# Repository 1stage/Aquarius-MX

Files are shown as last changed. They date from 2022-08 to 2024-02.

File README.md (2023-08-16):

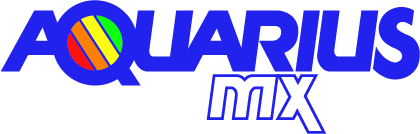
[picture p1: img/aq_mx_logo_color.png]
Aquarius MX Logo


## Overview
The Aquarius MX system expander brings USB compatibility to the Aquarius Computer along with a 32K RAM expansion, and features all the functionality of Bruce Abbott's Micro Expander in an easy-to-build solution that fits the footprint of the Mini Expander.

## Features
- **USB Drive Port** - Reads and writes to USB drive, for quick access to games and programs
- **32k RAM** - Removes the need for a separate RAM expansion cartridge
- **Cartridge ROM Loading** - Quick loading/running of legacy Aquarius ROM cartridges through USB
- **AY-3-8910 Sound Chip** - Three voice PSG (Programmable Sound Generator) with Control Pad IO
- **AY-3-8913 Sound Chip** - Support for optional second PSG (Programmable Sound Generator) for a total of six voices
- **Real Time Clock** - Support for optional Dallas DS1244Y Real Time Clock chip for TimeDate functions
- **PT3 Music Player** - Built-in retro music player
- **Aquarius Control Pad Inputs** - Standard DB9 connectors for attaching Aquarius Control Pads (internal header also available)
- **USB BASIC** - Enhanced commands for USB and IO devices to improve your BASIC programs
- **Classic Design** - Matches original Aquarius design aesthetic, in a device the same size as the Mini Expander: 210mm x 120mm x 55mm / 8.5" x 4.75" x 2.125"
- **Easy to Build** - Using standard through-hole components, this is an easy-to-make project for those who like to tinker in electronics
- **Open Source** - All components of this project are open source: make or modify them to your heart's content
- **Expandable** - System expansion port available for future add-ons

## Status Updates
- **16 AUG 2023** - MX BASIC 2.0 Final Release. Legacy v1.2 moved to archive.
- **09 AUG 2023** - MX BASIC 2.0 Beta Final Candidate release
- **16 JUL 2023** - MX BASIC 2.0 Beta 01 release
- **03 JUN 2023** - Update to 1-6-0 PCB to solve a shorting issue (thanks Carl Miles for finding this one). New version is 1-6-0b. Pushed to PCBWAY and PCB directory. 1-6-0a removed from repo.
- **16 MAY 2023** - Alpha Testing in process. Version 1-6-0a of PCB available, supporting new ROM/CART and RTC reset options; AQ_MX_RRU.JED incremented to 1.2 to support reset behavior updates. ROM v1.3 development upgraded to v2.0 due to large list of features and updates.
- **01 MAY 2023** - Version 1-5-0a of PCB available, supporting RTC integration.
- **02 FEB 2023** - Published version 1-4-0c of the PCB which fixes a missing mounting hole for Controller B when using a metal DB9 port. If you ordered a 1-4-0b version, the hole can be drilled out at 1/8" / 3.25mm.
- **21 JAN 2023** - Published version 1-4-0b of the PCB. Allows use of either **[Type A or Type B CH376S USB interface boards](https://github.com/1stage/Aquarius-MX/tree/main/pcb#ch376s-usb-interface-modules)**, and allows use of less expensive metal DB9 connectors.
- **07 NOV 2022** - Created PDF form template for bottom label.
- **26 SEP 2022** - Released YouTube video on intro to USB BASIC programming. Added source files and tools from the videos into the src/usb-basic folder.
- **21 SEP 2022** - v1.2 of MX ROM released to fix LOAD into array bug, and added "smart" load of SCR files into Screen RAM; [**AquaLite 1.32 released**](http://aquarius.je/aqualite) with the v1.2 MX ROM included, fixes SAVE issues, and can now be used to develop MX-dependent games & software.
- **15 SEP 2022** - Four YouTube videos on the Aquarius MX are posted; see links in docs folder.
- **09 SEP 2022** - Testing complete. All components are cleared for production and sale.
- **29 AUG 2022** - Signature Version (prebuilt) serial number 0001-SPH available for purchase on eBay (SOLD, 9/5/2022).
- **28 AUG 2022** - Prototypes shipped to testers. ROM incremented to v1.1 (replaced KILL command with DEL).
- **24 AUG 2022** - Most files have been uploaded and are actively being updated directly to the Repo.
- **23 AUG 2022** - Vendors identified in USA and UK to supply components.
- **21 AUG 2022** - First prototype completed and tested locally. Others will be built and sent to designated testers through the end of AUGUST 2022.
- **16 AUG 2022** - GitHub repository site created.

## Build Process
1. **Acquire the components** - [Click for Bill of Materials](https://docs.google.com/spreadsheets/d/1y7v0VCkjMdx25ugit28F5JhuhwDJofCVQUG5Ozl9IgA)
2. **Program the ROM and Logic Chips** - [Watch the YouTube video](https://youtu.be/DqxqzWqVAIM)
3. **Assemble the PCB** - [Watch the YouTube video](https://youtu.be/_-p9Ycmr9VQ)
4. **Enclose components in the case** - [Watch the YouTube video](https://youtu.be/FKW6YiFKHf0)
5. **Format and configure USB drive**

## GitHub Folder Structure
- **case** - components to make the 3D printed enclosure
- **docs** - system documentation, including schematics, board layout, and logo files
- **img** - image files used on this site
- **pcb** - files for making or modifying the PCB
- **software** - files for creating or updating the software used to run or control the Aquarius MX
- **src** - files for programming in USB BASIC, or modifying ROM and GAL logic chips

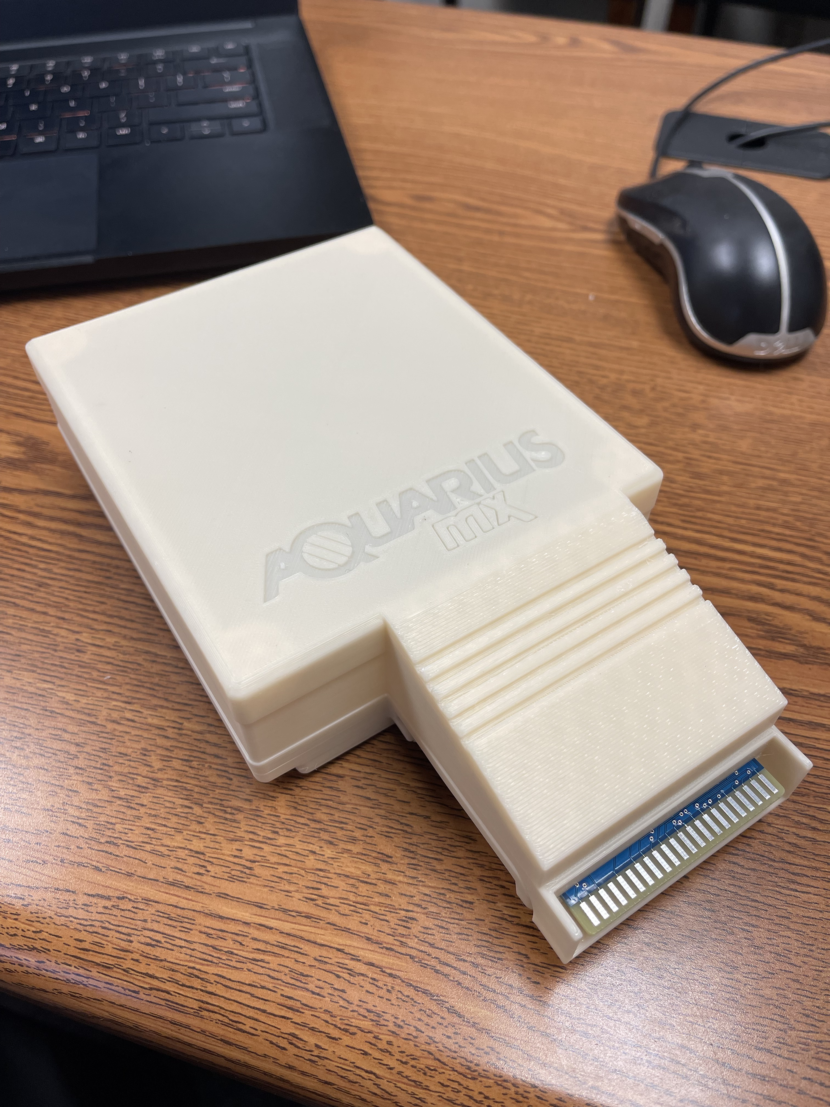
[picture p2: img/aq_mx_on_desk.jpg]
Aquarius MX on Desk


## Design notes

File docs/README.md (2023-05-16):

# Aquarius MX Documentation
This folder contains Aquarius MX documentation and logo files.

## Folder Contents
 - **USB BASIC v1.3.pdf** - This file details the new and updated commands in USB BASIC v1.3.
 - **MX_Bottom_Label.pdf** - This file is a PDF form (with embedded fonts) that allows makers of the Aquarius MX to create a professional-looking label for the bottom of the case. It can be printed using a laser, inkjet, or dyesub printer, or can be used for laser-engraved labels.
   - **Model Number field** - This value should match the PCB version, so the default MX0103-C is probably best. If you make any updates to the MX PCB, or add any modifications, consider changing this to something more in line with your modification.
   - **Serial Number field** - This value is the serial number for your unit. It is common to start with a unique sequence of numbers like 2001, 2002, 2003, followed by a three letter combination of the person making the unit.
   - **Build Date field** - This should be the date you created this unit, in DD MON YYYY format, so January 10, 2023 would be 10 JAN 2023.
 - **logo** - This foder contains the EPS (Encapsulated Post Script) logo files in vector format for use in documentation and other branding for the Aquarius MX.
   - **aq_mx_logo_blue.eps** - This logo file is the MONOCHROME version of the Aquarius MX logo. Use this file for single-color use of the logo. *DO NOT CHANGE THE COLOR OF THE LOGO TO ANYTHING OTHER THAN THE DEFAULT BLUE.*
   - **aq_mx_logo_bw.eps** - This logo file is the BLACK and WHITE version of the Aquarius MX logo. Use this file for instances where the logo will be printed on standard black on white, or on a light-colored background where only BLACK ink is available.
   - **aq_mx_logo_color.eps** - This logo file is the COLOR version of the Aquarius MX logo, which includes color banding in the "Q". Use this file for full-color use of the logo.
   - **aq_mx_logo_white.eps** - This logo file is the WHITE on dark version of the Aquarius MX logo. Use this file for instances where the logo needs to be used against a dark background. *DO NOT CHANGE THE COLOR OF THE LOGO TO ANYTHING OTHER THAN WHITE.*
 - **aq_mx_vX-X-Xx_BOARD.PDF** - This file documents the PCB layout for the Aquarius MX.
 - **aq_mx_vX-X-Xx_SCHEMATIC.PDF** - This file documents the electronic schematic for the Aquarius MX.
 - **usb-basic-commands.md** - A brief overview that discusses the USB BASIC commands.
 
 *Note: There are PNG versions (with transparency) of each of the logos listed above in raster format in the "img" folder at the root of the Aquarius MX GitHub repository.*
## How-to Videos
- **Aquarius MX Build Videos** (YouTube)
   - **[Aquarius Computer - Overview of the Aquarius MX Expander](https://youtu.be/i6mWsHNqth0)**
   - **[Aquarius Computer - Building the Aquarius MX PCB](https://youtu.be/_-p9Ycmr9VQ)**
   - **[Aquarius Computer - Programming the Aquarius MX ROM and GALs](https://youtu.be/DqxqzWqVAIM)**
   - **[Aquarius Computer - Assembling and Testing the Aqurius MX](https://youtu.be/FKW6YiFKHf0)**
   - **[Aquarius Computer - Using USB BASIC](https://youtu.be/Butym641a-0)**

## Logo Usage Recommendations
- **Keep it in Proportion** - Maintain the proper proportions of the Aquarius MX logo. Don't squash or stretch the logo to fill empty space. In most design/layout applications, this means dragging to resize the logo from the CORNER points, not the sides.
- **Colors Matter** - Don't change the colors of the logo to suit your needs. Keep the BLUE the same color blue, and don't change the COLOR version of the logo to modify the rainbow colors in the "Q".
- **Black on White** - If a single-ink/color usage is needed, use the "BW" version of the logo on light color paper/backgrounds in BLACK ink. Otherwise, use the "WHITE" version of the logo on dark color paper/backgrounds in WHITE ink.
- **Don't Make it Your Own** - Don't alter the design of the logo, or add your own branding to it that intrudes within an area closer than 10% of the height or width of the border of the logo. The logo is for EVERYONE to use as a standard.

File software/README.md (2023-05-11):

# Aquarius MX Software
This folder contains the **CURRENT RELEASE** version 1.2 of the software for programming and using the Aquarius MX.

## Folder Contents
 - **bin** - This folder contains the compiled BINARY images 
   - **AQ_MX_ROM.BIN** - For programming the EPROM (64kb MX system ROM)
   - **AQ_MX_RRU.JED** - For programming the GAL which controls the ROM/RAM/USB devices
   - **AQ_MX_AY.JED** - For programming the GAL which controls the AY sound chip IO
 - **usb** - this contains a starting set of files to be written to your properly formatted USB drive, including ROM files, PT3 music files, and starter BASIC programs that demonstrate how to use the Aquarius MX's new USB BASIC commands.

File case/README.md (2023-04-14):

# Aquarius MX 3D Printed Case
This folder contains the STL (STereoLithogray) files needed to 3D print an enclosure for the Aquarius MX.

## Files
- **aq_mx_base_template.stl** - This is a template for consistently applying the rubber feet and bottom label in the correct position on the bottom of the case.
- **aq_mx_case_bottom.stl** - This is the bottom or base of the Aquarius MX case.
- **aq_mx_case_top.stl** - This is the top or cover of the Aquarius MX case.
- **aq_mx_top2.stl** - This is an alternate top or cover with an opening to access control pad header.
- **aq_mx_top2_door.stl** - This is the door that goes with top2.
- **aq_mx_pcb_feet.stl** - This is a set of feet that can be used instead of a case to hold the PCB at the proper height.

## General Notes
- Now that either type of CH376S modules and/or either type of DB9 ports are usable, the 3D printed case MAY have to be modified to allow access to these newer ports...
  - When using the Type B CH376S module, it is inset further into the case than the Type A. This is not a problem with small USB thumbdrives, but some larger drives might not fit.
  - When using metal shrouded DB9 ports instead of the plastic automotive grade versions, the port is inset further into the case, so MOST Control Pad connectors won't fit through the standard opening. The area around these ports will have to be modified to allow these plugs to fit. At some point, a version of the 3D printed case will be developed with an OPEN BACK for the ports, where inserts for any type of port can be printed separately and glued in place. There is no timeline on this option, so for now, modifying the case is the only option.
- The RAM chip can be socketed and eventually replaced with a Dallas DS1244 RTC (Real Time Clock) module. This works as RAM for all released versions of the Aquarius MX (board and ROM), but DateTime commands that access the RTC won't be available until the 1.3 ROM is released (see the src > rom > v1.3 path for the work-in-progress). This relates to the 3D printed case because there is still plenty of HEIGHT inside the case, as-designed, for this RTC, even socketed, but the version of the case with the door (top2) does expose some of the RTC, which could interfere with future Control Pad interfaces or modified doors.

## FDM Printing
The typical method people will use to print the Aquarius MX case is FDM (Fused Deposition Modeling), the most common and cost-effective means to create a 3D printed enclosure. For the Aquarius MX case, here are the recommended specifications for FDM printing.

- **Material** - It is recommended that both components of the Aquarius MX case be printed in PLA (PolyLactic Acid) plastic rather than ABS (Acrylonitrile Butadiene Styrene) plastic, due to the large, flat surface features of the case. ABS is more prone to warping in the corners, and this can create an offset of the plane which keeps the PCB flat and even with the expansion port of the Aquarius computer. A heated build surface is strongly encouraged, particularly with the top of the case, as an embossed Aquarius MX logo is featured, and usually sticks better to a heated surface.
- **Nozzle Diameter** - A typical 0.4mm nozzle works fine
- **Layer Height** - A layer height of between 0.2mm and 0.4mm offers a good range of speed/surface quality.
- **Build Area** - The 3D printer must support a build size of 212.1mm x 120.9mm x 65.3mm / 8.5" x 4.75" x 2.125" to print the largest of the two parts (the top).
- **Support Material** - Standard square supports are recommended. Tree supports do not offer the best results. We don't require a brim or raft, but if you use these, remember to account for this in your build volume dimensions. 

### PLA Part Printing Orientation
- **Bottom** - This part should be printed with the BOTTOM facing down on the build surface, and support material is generated under the "neck" and inside the alignment notches on the neck. Using the above recommended settings, the BOTTOM piece will typically take 10 to 14 hours to complete, and will consume about 90g of PLA filament.
- **Top** - This part should be printed with the TOP facing down on the build surface, and support material is generated beneath the top "ramp" and inside the cartridge alignment guides. Note that this part features an embossed Aquarius MX logo, which prints best if a heated build surface is used. Some printers benefit from additional build surface adhesive, such as glue stick or hairspray, but go with what you're used to doing. Using the above recommended settings, the BOTTOM piece will typically take 13 to 19 hours to complete, and will consume about 114g of PLA filament

## SLA Resin Printing
Some manufacturers such as JLCPCB offer SLA (StereoLithogrAphy) resin printing for about US$20 for the two parts of the case, but shipping will usually add another US$30-40. Due to the volume and dimensions of the Aquarius MX case, SLA resin printing is not practical for most consumer-grade resin printers.

## SLS/MFJ Printing
If you have access to a high-end SLS (Selective Laser Sintering) or MJF (MultiJet Fusion) printer, these produce EXCEPTIONAL results, but at a significant cost. Most service bureaus will charge approximately US$200 for the two parts of the case, plus shipping.

## Finishing
- The case can be printed in a light beige color to approximate the Aquarius plastic (see BOM for details), or in black. The parts can alternately be printed in any color, then primed, filled and painted to suit your needs. Note that there are fine details in the embossed logo that can be lost if a filler primer is used, and some of the parts of the case that join with the Aquarius are tight, and can cause some paints to rub off if not sealed and/or lubricated properly.
- The case uses four 1/2" #4 pan head screws to attach the top and bottom halves. A metal "thread cutting" screw designed for plastic is recommended. See BOM for details.
- The finished case will also need four rubber feet for the bottom to bring the case up to the proper height for alignment with the Aquarius cartridge port. See BOM for details. You can print and use the **aq_mx_base_template** file for accurate positioning of these rubber feet.

## PCB Feet
The PCB feet file can be used instead of printing a full case for the Aquarius MX. These feet print in less than 1 hour on most FDM printers, and can be screwed to the bottom of the PCB through the mounting holes using the same screws that would hold the full case together. This maintains the PCB at a plane that is inline with the Expansion Port on the Aquarius Computer. This is important because if the PCB is at an angle (too high or too low), the contact between the computer and the expander PCB can be lost, and will cause the Aquarius MX (or the computer) to malfunction or become damaged. After printing, the four feet must be separated from one another to fit in each of the four corner PCB mounting holes. The "flashing" at the bottom edges between the feet should be trimmed off or sanded for best results.

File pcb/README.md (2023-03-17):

# Aquarius MX PCB
This folder contains the components and procedures for creating the Aquarius MX PCB (Printed Circuit Board).

[PCB is available for order directly from **PCBWay by clicking here!**](https://www.pcbway.com/project/shareproject/Aquarius_Computer_Aquarius_MX_USB_Expander_c4a2f027.html) Don't forget to like and vote for our project!

## Overview of PCB Assembly Options
For those who want to build their own Aquarius MX, there are a number of options and features that can alter the cost and complexity of the process. Solutions range from a bare PCB with only the components necessary to run and use USB BASIC and the core Aquarius MX software, all the way to a fully assembled and finished Aquarius MX. The following items offer details of the range of options.
- **Bare Bones** - The simplest version of the Aquarius MX features the PCB, the ROM (socket recommended), RAM, USB module (headers recommended), GAL-RRU logic chip (socket recommended), address buffers, ROM address headers, balance capacitors, audio amp, and reset circuit. It does not include a 3D printed enclosure, so the PCB feet MUST be used to keep the PCB aligned with the Aquarius computer Expansion Port. The AY-3-8910 sound chip and the GAL-AY logic chip are ommitted, so there will be no enhanced sound or Control Pad input, and since there is not Control Pad input, the DB9 Control Pad ports are omitted, along with the PSG control header. It is estimated this version of the Aquarius MX can be built for less than US$75.
  - **PROS** - Cheapest solution; easy & quick to build; still maintains USB file access; all USB BASIC commands accessible (if not functional).
  - **CONS** - No three-voice sound or Control Pad input; vulnerable to damage for both the MX and the Aquarius computer due to exposed components.
- **Bare with Sound and IO** - Includes everything from Bare Bones, but adds the AY-3-8910 sound chip (socket recommended), GAL-AY logic chip (socket recommended), and a 2x10 Control Pad pin header (still no DB9 ports). With the additional components, it is estimated this version of the Aquarius MX can be built for less than US$100.
  - **PROS** - Inexpesive solution that has full software functionality of the MX; easy & quick to build.
  - **CONS** - Still vulnerable to damage to the MX and the Aquarius computer due to exposed components.
- **MX to Go** - Adds the 3D printed case and cable-attached DB9 ports to allow Control Pad input at a reduced cost. USB card is more securely mounted to the MX PCB with Nylon stand-offs, both for stability and to keep it at the proper height within the case. Rubber feet are added to the case for proper alignment. DB9 ports are added by using the male end of two, less expensive "ATARI joystick" extension cables, either soldered directly to the DB9 pads on the PCB, or added to a 2x10 pin header, then trailed out the back of the MX case. With the additional components, it is estimated this version of the Aquarius MX can be built for less than US$125.
  - **PROS** - Adds Control Pad input, inexpensively; components are no longer at risk of damage now that they're inside a case
  - **CONS** - Lacks a professional, finished appearance; cables rattle around a bit
- **Complete Aquarius MX** - Adds the official DB9 ports used on the Mini Expander for a finished, professional appearance. It is estimated this version of the Aquarius MX can be built for less than US$150.
  - **PROS** - Professional appearance; perfect for resale
  - **CONS** - More expensive than the other options

## Folder Contents
 - **eagle** - This foder contains the files for Eagle (PCB design and layout tool published by Autodesk)
   - **archive** - Contains previous versions of the PCB source files
   - **aq_mx_v1-4-0c.brd** - Eagle Board file, describing the physical layout for the PCB, including all copper, solder masks, and silkscreen markings
   - **aq_mx_v1-4-0c.cam** - Eagle CAM board manufacturing profile for exporting proper layers to Gerber format
   - **aq_mx_v1-4-0c.sch** - Eagle Schematic file, describing the electronic architecture of the Aquarius MX
 - **gerber** - This folder contains a ZIP archive file used to upload to PCB manufacturers such as OSH Park, JLCPCB, PCBWay, and others.
 
## CH376S USB Interface Modules
There are two types of CH376S USB interface modules available. Here is how to identify the type of CH376S module you have:
 - **Type A Module** (referred to as an "LC Tech module" by Bruce Abbott during development of Micro Expander). Here's how to identify a **Type A** module:
    - Two sets of 1x3 jumper pins next to the USB port
    - Data header row (D0-D7) is at the BACK of the module, furthest away from the USB port
    - LED (D1) is near the 2x8 header pins
 - **Type B Module** (referred to as an "IC Station module" by Bruce Abbott during development of Micro Expander). Here's how to identify a **Type B** module:
    - One set of 1x3 jumper pins next to the USB port
    - Data header row (D0-D7) is towards the MIDDLE of the board, closest to the CH376S chip
    - LED (D1) is between the USB port and the 1x3 jumper pins

Beginning with v1-4-0, the Aquarius MX supports both **Type A** and **Type B** modules on a single PCB. Versions v1-3-0c and prior of the Aquarius MX PCB support only the **Type A** modules.
 - **Type A** modules install into the two columns of header pins closer to the BACK of the Aquarius MX. 
 - **Type B** modules install into the two columns of pins closer to the FRONT of the Aquarius MX. Note that since the **Type B** module is 1/10" further away from the back of the case, some USB thumb drives may be more difficult to insert. 

## Recommended PCB Manufacturing Settings
 - **Base Material:** FR-4
 - **Layers:** 2
 - **Dimension:** 112.5mm x 208.6mm
 - **Different Design:** 1
 - **Delivery Fomat:** Single PCB
 - **PCB Thickness:** 1.6mm
 - **Layer stackup:** PCB
 - **Color:** Blue (recommended)
 - **Silkscreen:** White (default with Blue color)
 - **Surface Finish:** HASL (with lead)
 - **Outer Copper Weight:** 1
 - **Gold Fingers:** No
 - **Flying Probe Test:** Fully Test
 - **Castellated Holes:** No
 - **Remove Order Number:** Yes
 - **Paper between PCBs:** No
 - **Appearance Quality:** IPC Class 2 Standard
 - **Confirm Production file:** No
 - **Silkscreen Technology:** Ink-jet/Screen Printing Silkscreen

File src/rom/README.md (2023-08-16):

# Aquarius MX ROM Source Code
This folder contains the source code files for the Aquarius MX ROM.

## Release Folders
 - **v2-0** - This is the current PRODUCTION version of the MX ROM. See readme.md within folder for full list of commands and functions.
 - **archive** - Old versions of the MX ROM.
   - **v1-2** - This was the final version of USB BASIC. 
   - **v1-1** - Changed KILL to DEL
   - **v1-0** - Last version used by the Micro Expander.

## General Notes
- ROM/BIN (BINary) files are created using ASM (ASseMbly language), which is compiled using a Z80 assembler (usually zmac).

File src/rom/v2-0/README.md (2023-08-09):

MX BASIC Documentation
======================

Generated by makedoc.py

---
## & Operator
Get Variable Address
### FORMAT:
 - &*varname*
   - Action: Returns the address of the first byte of data identified with variable *varname*.
     - Variable *varname* can be either a simple variable or an indexed array element, either string or numeric in both cases.
     - For numeric variables and array elements, the returned address points to the binary floating point number.
     - For string variables and array elements, the returned address points to the string descriptor.
     - If the variable or array does not exist, it is automatically created.
     - The address returned will be an integer in the range of 0 and 65535.
 - &&*varname*
   - Action: Returns the address of the first byte of the string text associated with *stringvar*.
     - Variable *arrayname* can be either a simple string variable or string array element.
     - Returns TM error if *varname* is not a string variable.
     - If the variable or array does not exist, it is automatically created.
     - Returns 0 if the variable or array element was automatically created.
 - &\**arrayname*
   - Action: Returns the address of the first byte of data identified with array *arrayname*.
     - Array *arrayname* can be either a numeric or string array. It is specified without following parenthesis.
     - Returns FC error if the array does not exist.
 - Note: Care should be taken when working with an array, because the addresses of arrays change whenever a new simple variable is assigned.
### EXAMPLES:
` A=44:COPY &A,&B,4:PRINT B `
> Assigns A a value, copies its contents from the address of A to a new address for B, and prints the value at that address.

` DIM A(9):PRINT &*A `
> Prints start address of array A() definition.

` PRINT PEEK(&A$) `
> Prints the length of A$.

` PRINT DEEK(&A$+2) `
> Prints the address of the text for A$.

` PRINT &&A$ `
> Also prints the address of the text for A$.

---
## AND Function
Bitwise AND
### FORMAT:
 - AND( *number1*, *number2* )
   - Action: Returns the bitwise AND of two numbers.
     - Both *number1* and *number2* must be between -32768 and 65535.
     - Can be used instead of AND operator which only allows operands between -32768 and 32767.
### EXAMPLE:
` PRINT AND(-1,$FFFF) `
> Prints 65535

---
## ASC$ Function
Convert Hexadecimal String to ASCII String
### FORMAT:
 - ASC$ ("*string*")
   - Action: Returns string whose characters ASCII values match the series of two digit hexadecimal numbers in *string*.
     - See the HEX$ function for string-to-hex conversion.
### EXAMPLE:
` PRINT ASC$("414243") `
> Prints the string "ABC".

---
## ATN
Arctangent
### FORMAT:
  - ATN ( *number* )
    - Action: This mathematical function returns the arctangent of the number.
      - The result is the angle (in radians) whose tangent is the number given. The result is always in the range -pi/2 to +pi/2.
### EXAMPLES:
` PRINT ATN(1) `
> Prints the arctangent of 1, a value of `0.785398`

` X = ATN(J)*180/ {pi} `
> Defines variable X as the arctangent of another variable, J, divided by pi.

---
## CALL
Jump to and run machine code at specified address
### FORMAT:
 - CALL *address*
   - Action: Causes Z80 to jump from it's current instruction location to the specified one. Note that there must be valid code at the specified address, or the Aquarius will crash.
   - *address* can be a 16 bit signed or unsigned integer or hex value
### EXAMPLES:
` CALL $A000 `
> Begin executing machine code stored at upper half of middle 32k expansion RAM

` 10 LOAD "PRG.BIN",$A000 `

` 20 CALL $A000 `
> Loads raw binary code into upper 16k of 32k expansion, and then begins executing it.

---
## CAT
Catalog disk (quick DIR listing)
### FORMAT:
 - CAT
   - Action: Show a brief listing of all files and folders in the current directory.
     - File size, date, and time are not shown.
     - Directory names are shown in < >.
### EXAMPLE:
` CAT `
> List all files and folders in current directory in a 3-across format

---
## CD
Change directory / current path
### FORMAT:
 - CD
   - Action: show current path
 - CD "*dirname*"
   - Move into directory indicated by *dirname*
### EXAMPLES:
` CD "songs3" `
> Move into `songs3` (add `songs3` to current path)

` CD "/" `
> Move to root of the USB drive

` CD ".." `
> Back up one level to folder containing this one

` CD `
> Show the current path

---
## CD$
Get Current Directory path as a string
### FORMAT:
 - CD$
   - Action: Returns the current directory path as displayed by the CD command with no arguments
### EXAMPLES:
` PRINT CD$ `
> Prints the current directory path to the screen

` 10 A$=CD$:PRINT A$ `
> Assigns the current path string to A$, then prints it.

---
## CIRCLE Statement
Draw circle or ellipse on screen.
### FORMAT:
  - CIRCLE(*xcenter*, *ycenter*), *radius*[,[*color*][,[*start*],[*end*][,*aspect*]]]
    - Action: Draws circle, ellipse, or arc with given *radius* centered at *xcenter*, *ycenter*.
      - If *color* is not specified, the screen colors are maintained.
      - The *start* and *end* angle parameters are radian arguments between -2π and 2π which specify where the drawing of the ellipse is to begin and end.
        - If start or end is negative, the ellipse is connected to the center point with a line, and the angles are treated as if they are positive (note that this is different from adding 2π).
        - The start angle may be less than the end angle.
      - The option *aspect* describes the ratio of the x radius to the y radius (x:y).
        - The default aspect ratio gives a visual circle, assuming a standard monitor screen aspect ratio of 4:3.
        - If the aspect ratio is less than 1, then the radius is given in x-pixels. If it is greater than 1, the radius is given in y-pixels.
        - In many cases, an aspect ratio of 1 gives better ellipses. This also causes the ellipse to be drawn faster.
### EXAMPLES:
` CIRCLE(40,36),10,8 `
> Draws a grey circle in the center of the screen.

` CIRCLE(40,36),10,3,-0.75,-5.7,0.75 `
> Draws a popular arcade character in the middle of the screen

---
## CLEAR
Clear Variables and/or Error Code
### FORMAT:
  - CLEAR [ *number*, [ *address* ] ]
    - Action: Clears all variables and arrays, last arror number and line.
      - If *number* is specified allocates string space.
        - BASIC starts with 1024 bytes of string space allocated.
      - If *address* is specified, sets top of BASIC memory.
        - If 0, set to start of system variables minus one
        - FC Error if less than end of BASIC program plus 40 bytes
        - FC Error if greater than or equal to start of system variables
  - CLEAR ERR
    - Action: Clears last error number and line.
      - Leaves variables and arrays intact.
  - CLEAR DIM *array* [, *array* ...]
   - Action: Eliminates array from program.
     - Arrays may be redimensioned after they are ERASEd, or the previously allocated array space in memory may be used for other purposes.
     - If an attempt is made to redimension an array without first ERASEing it, a "Redimensioned array" errors.
### EXAMPLES:
` CLEAR 2000 `
> Reserves 2000 bytes of space for strings.

` CLEAR 100, $A000 `
> Reserves 100 bytes for strings and sets top of BASIC memory to 40960

` CLEAR 500, 0 `
> Reserves 500 bytes for strings and sets to the maximum allowed

` CLEAR ERR `
> Sets last error number and line as returned by ERR(1) and ERR(2) to 0.

` CLEAR DIM A `
> Removes array A() from memory.

` 10 DIM B$(20) `
` 20 CLEAR DIM B$ `
` 30 DIM B$(10) `
> Dimensions B$ as a 20 unit string array, then ERASES it, then redimensions it as a 10 unit array.

---
## CLS (Extended)
Clear Screen / Clear Screen with specified foreground and background colors
### FORMAT:
 - CLS [ *foreground, background* ]
   - Action: Clears the screen, moves the cursor to the top left position of the screen, and resets the DRAW parameters to their defaults.
     - The optional *foreground* and *background* parameters are numbers between 0 and 15 that specifies the new foreground and background colors.
       - If either parameter is specified, both must be specified.
       - If *foreground* and *background* , the screen is cleared with the default BLACK characters on CYAN background.
>
    0 BLACK      4 BLUE       8  GREY        12 LTYELLOW
    1 RED        5 MAGENTA    9  DKCYAN      13 DKGREEN
    2 GREEN      6 CYAN       10 DKMAGENTA   14 DKRED
    3 YELLOW     7 WHITE      11 DKBLUE      15 DKGREY

   - Warning: If the foreground and background colors are the same, typed and PRINTed text will be invisible.
   - Advanced: Unlike PRINT CHR$(11), CLS does not clear memory locations 13288 - 13313 ($33E8 - $33FF) and 14312 - 14355 ($37E8 - $37FF).
### EXAMPLES:
` CLS `
> Clear screen with default colors

` CLS 0,7 `
> Clear screen - black text on white background

` CLS 3,0 `
> Clear screen - yellow text on black background

` CLS F,B `
> Clear screen - text color F, background color B (using BASIC variables)

---
## COLOR Function
Get Current Color
### FORMAT:
 - COLOR( 0 )
   - Action: Returns the current draw color as set by the last CLS or DRAW statement.
 - COLOR( 1 )
   - Action: Returns the current draw color as set by the last CLS or DRAW statement.
 - Any other arguments result in an FC Error.
### EXAMPLES:
` PRINT COLOR(0) `
> Prints the current draw color

---
## COLOR Statement
Set Foreground Color
### FORMAT:
 - COLOR *color*
   - Action: Sets the default color for LINE and COLOR to *color*.
     - Results in FC Error if *color* is not between 0 and 15, inclusive.
### EXAMPLES:
` COLOR 2 `
> Sets the foreground to green.

---
## COPY Statement (Enhanced)
Copy screen to Line Printer / Copy memory
### FORMAT:
  - COPY
    - Action: Sends screen contents to line printer (legacy command)
  - COPY *source*, *dest*, *count*
### EXAMPLES:
` COPY ` (no parameters)
> Send contents of screen to line printer

` COPY 12368,12328,920 `
> Scroll Screen Up One Line

` COPY 12288,12328,920 `
> Scroll Screen Down One Line

` COPY 12329,12328,39 `
> Scroll Row 1 right 1 char

` COPY $3000,$2000,2048 `
> Copy Screen and Colors to Low RAM

` COPY $2000,$3000,2048 `
> Restore Screen and Colors

---
## DEBUG
Activate machine language debugger
### FORMAT:
 - DEBUG
   - Action: Pauses current program and activates the debugger (if one is installed).
     - At startup, no debugger is installed: A message is displayed and control immediately returns to BASIC.
### EXAMPLES:
` DEBUG `
> Displays message "Debugger not installed" and returns to BASIC prompt.

---
## DEC
Hexadecimal to integer conversion
### FORMAT:
 - DEC(*hexadecimal string*)
   - Action: Returns the DECimal value of the hexadecimal number in *hexadecimal string*.
     - If the first non-blank character of the string is not a decimal digit or the letters A through F, the value returned is zero.
     - String conversion is finished when the end of the string or any character that is not a hexadecimal digit is found.
     - See the HEX function for number-to-hex conversion.
### EXAMPLES:
` PRINT DEC("FFFF") `
> Prints "65535"

` 10 A$=HEX$(32):PRINT DEC(A$) `
> Prints "32"

---
## DEEK
Read 16 bit word from Memory
### FORMAT:
- DEEK(*address*)
  - Action: Reads a word from memory location *address*, returning a number between 0 and 65535.

### EXAMPLES:
` POKE DEEK(14337),PEEK(14349) `
> Remove cursor from screen.

` PRINT DEEK($384B) `
> Print the top of BASIC memory address.

---
## DEF FN / FN
Define User Function
### FORMAT:
  - DEF FN *name* ( *variable* ) = *expression*
    - Action: This sets up a user-defined function that can be used later in the program. The function can consist of any mathematical formula. User-defined functions save space in programs where a long formula is used in several places. The formula need only be specified once, in the definition statement, and then it is abbreviated as a function name. It must be executed once, but any subsequent executions are ignored.
      - The function name is the letters FN followed by any variable name. This can be 1 or 2 characters, the first being a letter and the second a letter or digit.
      - The parameter *variable* represents the argument variable or value that will be given in the function call and does not affect any program variable with the same name. For any other variable name in *expression*, the value of that program variable is used.
      - A DEF FN statement must be executed before the function it defines may be called. If a function is called before it has been defined, an "Undefined user function" error occurs.
      - Multiple user functions may be defined at once, each with a unique FN name. Executing a DEF with the same FN name as a previously defined user function replaces the previous definition with the new one. DEF FN is illegal in direct mode.
      - The function is called later in the program by using the function name with a variable in parentheses. This function name is used like any other variable, and its value is automatically calculated.
### EXAMPLES:
` 10 DEF FN A(X)=X+7 `

` 20 PRINT FN A(9) `
> Prints the value 16 (9 + 7)

` 10 DEF FN AA(X)=Y*Z `

` 20 R=FN AA(9) `
> Assigns R the value of X * Y, and the number 9 inside the parentheses does not affect the outcome of the function, because the function definition in line 10 doesn't use the variable in the parentheses.

` 10 DEF FN A9(Q) = INT(RND(1)*Q+1) `

` 20 G=G+FN A9(10) `
> Increments the value of G the rounded value of a random number between 1 and 10.

---
## DEF USR
Set USR() Function Address
### FORMAT:
  - DEF USR = *address*
    - Action: Sets the address to call when the USR() function is executed.
### EXAMPLES:
` DEF USR=1382 `
> Sets USR() to execute a RET, returning the whatever value was passed into it.
` DEF USR=$150B `
> Sets USR() to execute NEG, returning negative the passed in value.

---
## DEL
Delete a file
### FORMAT:
 - DEL *filespec*
   - Action: Deletes the file named *filespec* from the current directory.
     - *filespec* can be any string expression
     - No warnings are given.
     - Wildcards and paths cannot be used.
     - If *filspec* is a literal string, the end quotation mark is optional.
### ERRORS
 - If *filespec* is not included, an MO Error results
 - If file *filespec* does not exist, an IO Error with DOS Error "file not found" results.
### EXAMPLES:
` DEL "THISFILE.BAS" `
> Deletes the file named `THISFILE.BAS` from the current directory.

` 10 DEL "SAVEGAME.DAT" `
> Deletes the file named `SAVEGAME.DAT` from the current folder from within a program.

---
## DIR
Get a listing of the files on the current USB directory
### FORMAT:
 - DIR [ "*wildcard*" ]
   - Action: Show files in current directory with size, with an optional wildcard on filename
 - DIR SDTM [ "*wildcard*" ]
   - Action: Show files in current directory with size, date, and time, with optional *wildcard* on filename
   - Final quotation mark at end of *wildcard* string is optional.
### EXAMPLES:
` DIR `
> Show all files in current directory

` DIR "*.BAS" `
> Show BASIC program files in current directory

` DIR "*." `
> List all folder (or files without an extension) in current directory

` DIR SDTM "*A*" `
> Show any files with a letter A in the name, along with their last DateTime stamp

---
## DOKE
Writes 16 bit word(s) to memory location(s), aka "Double Poke"
### FORMAT:
 - DOKE *address*, *word*, [, *word* ...]
   - Action: Writes *word* to memory starting at *address*.
### EXAMPLES:
` DOKE 14340, 1382 `
> Set USR() function address

` DOKE $3028, $6162 `
> Put the characters `ba` at the top left of the screen

` DOKE $3028, $3130, $3332 `
> Put the characters `0123` at the top left of the screen

---
## DRAW Statement
Draws a figure.
### FORMAT:
  - DRAW *string expression*
    - Action: The DRAW statement combines most of the capabilities of the other graphics statements into an object definition language called Graphics Macro Language (GML). A GML command is a single character within a string, optionally followed by one or more arguments.
#### Commands:
Each of the movement commands begins movement from the current graphics position.
 - This is usually the coordinate of the last graphics point plotted with another GML command, LINE, or PSET.
 - The current position defaults to upper right hand corner of the screen (0,0) when at startup and after CLS or RUN.
 - Movement commands move for a distance of scale factor *n, where the default for n is 1; thus, they move one point if n is omitted and the default scale factor is used.
| Command  | Action
|    Un    | Move up
|    Dn    | Move down
|    Ln    | Move left
|    Rn    | Move right
|    En    | Move diagonally up and right
|    Fn    | Move diagonally down and right
|    Gn    | Move diagonally down and left
|    Hn    | Move diagonally up and left
This command moves as specified by the following argument:
` Mx, y ` Move absolute or relative.
  - If x is preceded by a + or -, x and y are added to the current graphics position, and connected to the current position by a line.
  - Otherwise, a line is drawn to point x, y from the current position.
The following prefix commands may precede any of the above movement commands:
` B`  Move, but plot no points.
` N`  Move, but return to original position when done.
The following commands are also available:
` An  ` Set angle n.
- n may range from 0 to 3, where 0 is 0°, 1 is 90°, 2 is 180°, and 3 is 270°.
- Figures rotated 90° or 270° are scaled so that they will appear the same size as with 0° or 180° on a monitor screen with the standard aspect ratio of 4:3.
- Angle is set to 0 at startup and by CLS and RUN.
` Cn  ` Set color n.
` Sn  ` Set scale factor n.
- n may range from 1 to 255. n is divided by 4 to derive the scale factor.
- The scale factor is multiplied by the distances given with U, D, L, R, E, F, G, H, or relative M commands to get the actual distance traveled.
- Scle factor is set to 4 at startup and by CLS and RUN.
`x*string* ` Execute substring.
- This command executes a second substring from a string, much like GOSUB. One string executes another, which executes a third, and so on.
- *string* is a variable assigned to a string of movement commands.
#### Numeric Arguments:
- Numeric arguments can be constants like "123" or "=variable;", where variable is the name of a variable.
- When you use the second syntax, "=variable;", the semicolon must be used. Otherwise, the semicolon is optional between commands.
### EXAMPLES:
```
  10 DRAW "BM 40,36"
  20 A=20: DRAW "R=A; D=A; L=A; U=A;"
```
> Moves to the center of the screen without drawing, then draws a box 11 pixels wide by 11 pixels high.
```
  30 PSET (10, 20)
  40 DRAW "E20 F20 L39"
```
> Draws a 42 pixel wide triangle with its top vertex at x-coordinate 10 and y-coordinate 20.

---
## DTM$
Get DateTime
### FORMAT:
 - DTM$(*number*)
   - Action: If a Real Time Clock is installed:
     - If *number* is 0, returns a DateTime string "YYMMDDHHmmsscc"
     - Otherwise returns formatted times string "YYYY-MM-DD HH:mm:ss"
     - Returns "" if a Real Time Clock is not detected.
### EXAMPLES:
` PRINT DTM$(0) `
> 38011903140700

` PRINT DTM$(1) `
> 2038-01-19 03:14:07

` PRINT LEFT$(DTM$(1),10) `
> 2038-01-19

` PRINT RIGHT$(DTM$(1),8) `
> 03:14:07

` PRINT MID$(DTM$(1),6,11) `
> 01-19 03:14

---
## EDIT
Edit BASIC Line
### FORMAT:
 - EDIT *line number*
   - Action: Displays BASIC line *line number* on screen and enters edit mode. While editing a line, the following control keys are available:
```
  CTL - P   Move cursor left
  CTL - /   Move cursor right
    <--     Delete character to left
  CTL - \   Delete character to right
    RTN     Save changes and exit edit mode
  CTL - C   Discard changes and exit edit mode
  CTL - R   Retype previously entered IMMEDIATE MODE command
```

   - Note: The above control keys are also available when entering a new line or direct mode command.

---
## ERR
Error Status
### FORMAT:
  - ERR ( *number* )
    - Action: Returns error status values.
      - If *number* is -1, returns the line number to GOTO when an error occurs.
        - Returns 0 if error trapping is disabled.
      - If *number* is 0, returns the number corresponding to the last error.
        - - Returns 0 if no error has occurred.
      - If *number* is 1, returns the line number the last error occurred on.
        - Returns 0 if no error has occurred.
        - Returns 65535 if the error occurred in immediate mode.
      - If *number* is 2, returns the number corresponding to the last DOS error.
        - Returns 0 if the last DOS command completed successfully.
      - If *number* is 3, returns the status code of the last CH376 operation.
        - This may not be directly related to the DOS error number.
      - Returns FC Error if *number* is none of the above

### Basic Error Numbers
| Err# | Code | Description |
|---|---|---|
| 1  |  NF  | NEXT without FOR |
| 2  |  SN  | Syntax error |
| 3  |  RG  | RETURN without GOSUB |
| 4  |  OD  | Out of DATA |
| 5  |  FC  | Function Call error |
| 6  |  OV  | Overflow |
| 7  |  OM  | Out of Memory |
| 8  |  UL  | Undefined Line number |
| 9  |  BS  | Bad Subscript |
|  10  |  DD  | Re-DIMensioned array |
|  11  |  /0  | Division by Zero |
|  12  |  ID  | Illegal direct |
|  13  |  TM  | Type mismatch |
|  14  |  OS  | Out of String space |
|  15  |  LS  | String too Long |
|  16  |  ST  | String formula too complex |
|  17  |  CN  | Can't CONTinue |
|  18  |  UF  | UnDEFined FN function |
|  19  |  MO  | Missing operand |
|  20  |  RE  | Disk I/O error |
|  21  |  IO  | RESUME without ERROR |
|  22  |  UE  | Unprintable error |

### DOS Error Numbers
| Err# | Error Message | Description |
|---|---|---|
| 1  | no CH376 | CH376 not responding |
| 2  | no USB | Not in USB mode |
| 3  | no disk | USB Drive mount failed |
| 4  | invalid name | Invalid DOS file name |
| 5  | file not found | File does not exist |
| 6  | file empty | File does not contain data |
| 7  | filetype mismatch | File is not in CAQ format |
| 8  | remove dir error | Unable to remove directory |
| 9  | read error | Error while reading USB drive  |
|  10  | write error | Error while writing USB drive  |
|  11  | file create error | Unable to create file |
|  12  | directory not found | Unable to open directory |
|  13  | path too long | Path is too long |
|  14  | disk error #xx | Other disk error |

---
## ERR$
Error Status
### FORMAT:
  - ERR$ ( *number* [, *error*] )
    - Action: Returns string containing description of error
      - If *number* is 0, returns a two character BASIC error code.
      - If *number* is 1, returns a BASIC error description
      - If *number* is 2, returns a DOS error description
    - If second argument *error* is included, prints the description for that error number.
      - Otherwise, prints the description corresponding to the value returned by ERR(*number*).
      - Returns an empty string if *error* or ERR(*number*) is 0.
      - Returns FC Error if *error* or ERR(*number*) is less than 0.
### EXAMPLES:
`

---
## ERROR
Trigger a BASIC Error
### FORMAT:
 - ERROR *error*
   - Action: Simulate the occurrence of an MX BASIC error or allows error codes to be defined by the user.
     - The value of *error* must be greater than 0 and less than 128.
     - If the value of *error* equals an error code already in use by MX BASIC (see ERR):
       - The ERROR statement will simulate the occurrence of that error, and the corresponding error message will be printed.
     - To define your own error code, use a value that is greater than any used by MX BASIC's error codes.
       - It is preferable to use the highest available values, so compatibility may be maintained when more error codes are added to MX BASIC.
       - This user-defined error code may then be conveniently handled in an error trap routine.
     - If an ERROR statement specifies a code for which no error message has been defined, MX BASIC responds with the message UNPRINTABLE ERROR.
     - Execution of an ERROR statement for which there is no error trap routine causes an error message to be printed and execution to halt.
     - If *error* is 0, no error is triggered, and program execution continues normally.
### EXAMPLES:
```
10 S = 10
20 T = 5
30 ERROR S + T
40 END
```
> Displays `?LS Error in 30` and halts program.

` ERROR 15 `
> Displays `?LS Error`

```
110 ON ERROR GOTO 400
120 INPUT "WHAT IS YOUR BET";B
130 IF B>5000 THEN ERROR 120
...
400 IF ERR(0)=120 THEN PRINT "HOUSE LIMIT IS $5000"
410 IF ERR(1)=130 THEN RESUME 120
```

---
## EVAL
Evaluate a formula in a string.
### FORMAT:
 - EVAL(*string*)
   - Action: Evaluates the numeric formula contained in *string* and returns the result.
### EXAMPLE:
` PRINT EVAL("7 + 4") `
> Prints the number 11.

---
## FILE$
Get Last Filename
### FORMAT:
 - FILE$
   - Action: Returns the contents of the FileName buffer.
### EXAMPLES:
` PRINT FILE$ `
> Prints the name of the last file accessed.

---
## FILEEND
Get End Address of Last LOADed File
### FORMAT:
 - FILE$
   - Action: Returns the end address of the last successful LOAD. This is the address of the last byte loaded plus one.
### EXAMPLES:
```
LOAD "BINFILE.RAW",START
PRINT FILEEND-START
```
> Loads file then prints the total bytes loaded.

---
## FRE Function (Enhanced)
Show available Memory / Show memory details
### FORMAT:
 - FRE ( 0 )
   - Action: Returns the number of bytes in memory not being used by BASlC.
 - FRE ( 1 )
   - Action: Returns the total size of string space (as set by the first argument of CLEAR).
 - FRE ( 2 )
   - Action: Returns the top of BASIC memory (as set by the second argument of CLEAR).
 - FRE ( 3 )
   - Action: Returns the top of user memory (the highest value allowed for CLEAR).
 - FRE ( *string* )
   - Action: Forces a garbage collection before returning the number of free bytes of string space.
     - BASIC will not initiate garbage collection until all free memory has been used up.
     - Therefore, using FRE("") periodically will result in shorter delays for each garbage collection.
  - Any other argument returns an FC error.
### EXAMPLE:
` PRINT FRE(0) `
> Displays amount of free remaining memory available to BASIC.

` PRINT HEX$(FRE(2)) `
> Displays the current top address of BASIC memory as a hexadecimal format address.

---
## GET Statement
Copy a rectangle of screen data to a numeric array.
### FORMAT:
 - GET (*x1*,*y1*)-(*x2*,*y2*),*arrayname*
   - Action: Copies a rectangle of screen characters and colors to numeric array *arrayname*.
     - The rectangle's upper left corner is at column *x1* on line *y1* and lower right corner is at column *x2* on line *y2*
     - *arrayname* must already be DIMensioned to a size large enough to hold the data.
       - To calculate the size of an array needed to store the elements in a rectangle:
         - Multiply the width of the rectangle in columns by the height in lines.
         - Round up to an even number
         - Divide by two
     - Can also be combined with LOAD array* and SAVE array* to import/export "sprite" graphics from/to USB drive.
     - See PUT statement for copying from array to screen.
 - Advanced: The screen data (CHRRAM and COLRAM) is stored in the array as binary data.
### EXAMPLE:
```
10 DIM A(8)
20 GET (1,1)-(4,4),A
30 SAVE "CURSOR.SPR",*A
```
> Saves the contents of a 4x4 character/color grid at the upper left of the screen to file CURSOR.SPR.

---
## HEX$
Integer to hexadecimal conversion
### FORMAT:
 - HEX$(*number* [,*length*])
   - Action: Returns string containing *number* in two-byte hexadecimal format.
     - If *length* is 0 or omitted, the returned string will be two characters if *number* is between 0 and 255, otherwise it will be four characters.
     - If *length* is 1, the returned string will be two characters long. If *nunmber* is greater than 255 or less than 0, only the LSB will be returned.
     - If *length* is 2, the returned string will be four characters long.
     - Returns FC Error if *number* is not in the range -32676 through 65535 or *length* is not in the range 0 through 2.
     - See the DEC function for hex-to-number conversion.
 - HEX$("*string*")
   - Action: Returns string containing a series of two digit hexadecimal numbers representing the characters in *string*.
     - Length of returned string is twice that *string*.
     - LS Error results if length of *string* is greater than 127.
     - See the ASC$ function for hex-to-string conversion.
### EXAMPLES:
` PRINT HEX$(1) `
> Prints "01"

` PRINT HEX$(1,2) `
> Prints "0001"

` PRINT HEX$(-1,1) `
> Prints "FF"

` 10 PRINT HEX$(PEEK(12288)) `
> Prints the HEX value of the border char (usually "20", SPACE character)

` PRINT HEX$("123@ABC") `
> Prints "31323340414243"

---
## Hexadecimal Numeric Literals
 - A hexadecimal numeric literal is a value between 0 and 65535, inclusive. It consists of a dollar sign followed by 1 to 4 hexadecimal digits.
   - May be used in any numeric expression or anywhere a numeric expression is allowed.
   - May be be used in DATA statements.
   - May *not* be used as entries to the INPUT statement, in string arguments to the VAL() function, or as the target of a GOTO or GOSUB statement.
### EXAMPLES:
` PRINT $FFFF `
> Prints 65535

` A = $101 `
> Sets A to 257

` P = $3000+40*R+C `
> Sets P to screen row 1, column 1 address

---
## Hexadecimal String Literal
 - A hexadecimal string literal consists of a dollar sign followed by quotation mark, an even number of hexadecimal digits.
   - Terminated with a quotation mark or end of line.
   - May be used in any string expression or anywhere a string expression is allowed.
   - May be be used in DATA statements.
   - May *not* be used as entries to the INPUT statement.
### EXAMPLE:
` PRINT $"414243" `
> Prints ` ABC `

---
## IN
Read Z80 I/O Port
### FORMAT:
 - IN(*address*)
   - Action: Reads a byte from the I/O port specified by LSB of *address*.
   - Advanced: During the read, *address* is put on the Z80 address bus.
### EXAMPLES:
` PRINT IN(252) `
> Prints cassette port input status

` S=IN($FE) `
> Set variable S to Printer Ready status

---
## INSTR Function
Search for string in another string
### FORMAT:
 - INSTR ( [ *offset* , ] *string1* , *string2* )
   - Action: Searches for the first occurrence of *string2* in *string1* and returns the position at which the match is found.
     - Optional *offset* sets the position for starting the search.
       - Must be in the range 1 to 255 or an FC Error results.
     - If *offset* > LEN(*string1*) or if *string1* is null or if *string2* cannot be found, INSTR returns 0.
     - If *string2* is null, INSTR returns *offset* or 1.
     - *string1* and *string2* may be string variables, string expressions or string literals.
### EXAMPLE:
```
  10 X$ = "ABCDEB"
  20 Y$ = "B"
  30 PRINT INSTR(X$,Y$) ;INSTR(4,X$,y$)
```
> Prints the numbers 2 and 6.

---
## JOY
Read AY-3-8910 Control Pad Inputs
### FORMAT:
 - JOY(*stick*)
   - Action: Reads integer input value from *stick*, where:
     - `0` will read left or right control pad
     - `1` will read left control pad only
     - `2` will read right control pad only
### EXAMPLES:
` PRINT JOY(0) `
> Prints input value of either/both control pads (not effective in immediate mode).

```
10 PRINT JOY(1)
20 GOTO 10
```
> Continuously reads and prints the input value from only the left control pad.

---
## KEY
Read Keyboard
### FORMAT:
 - KEY(*number*)
   - Action: Checks for a key press and returns the ASCII code of the key.
     - If *number* is 0, waits for a key to be pressed then returns it's ASCII code.
     - If *number* is positive, checks to see if a key has been pressed, returning the key's ASCII code (or 0 if no key was pressed). A key press will only be detected once, returning 0 on subsequent calls until the key is released and pressed again.
     - If *number* is negative, returns the ASCII code of the key currently being pressed (or 0 if no keys are being pressed). Subsequent calls will continue to return the key's ASCII code if the key remains pressed.
     - KEY() does not expand control-key combinations to keywords. Instead CTRL-A through CTRL-Z generate ASCII 1 through 27 (^A-^Z) The rest of the control characters are assigned as follows:
```
  KEY:  ;   =   0   :   /   -  8   9   7   ,   1   .   2  <--
ASCII: 128  27  28  29  30  31 91  93  96 123 124 125 126 127
 NOTE:  ^@ ESC  ^\  ^]  ^^  ^_ [   ]   `  {    |   }   ~  DEL

  KEY:   3    4    5    6   SPACE  RTN  Shift-SPC  Shift-RTN
ASCII:  158  143  159  142   $C6   255     160        134
 NOTE: LEFT  UP  DOWN RIGHT  dot  black   blank   checkerboard
```

### EXAMPLES:
` PRINT KEY(0) `
> Wait for a key press then print ASCII code

` 10 K=KEY(1) `

` 20 IF K THEN S$=S$+CHR$(K) `
> Check for key press and add key character to string once per key press

` 10 K=KEY(-1) `

` 2O IF K=97 THEN X=X-1 `

` 30 IF K=115 THEN X=X+1 `
> Continuously decrement or increment X as long as the A or S key, respectively, is pressed.

---
## KEY Statement
Controls keyboard functions
### FORMAT:
 - KEY SOUND [ON | OFF]
   - Action: Turns key click ON or OFF
 - KEY *string*
   - Action: Causes BASIC to act as though the characters in *string* are being typed on the keyboard.
     - Returns LS Error if *string* is longer than 15 characters.

### EXAMPLES:
` KEY SOUND OFF `
> Turns key click off.

` KEY SOUND ON `
> Turns key click on.

---
## LINE Statement
Draw line or box on screen.
### FORMAT:
  - LINE [ (*x-coord1*,*y-coord1*) ] - ( *x-coord2*,*y-coord2*) [ ,[ *color* ] [,B[F] ]
    - Action: Draws line from the first specified point to the second specified point.
      - If the first (*x-coord1*,*y-coord1*) is omitted (starts with a dash), the line starts at the last referenced point.
      - B (box) draws a box with the specified points at opposite corners.
      - BF (filled box) draws a box (as ,B) and fills in the interior with points.
      - If *color* is not specified, the current screen colors are maintained and two commas must be used before B or BF
### EXAMPLES:
` LINE (0,36)-(79,36) `
> Draws a horizontal line which divides the screen in half from top to bottom.

` LINE (40,0)-(40,71) `
> Draws a vertical line which divides the screen in half from left to right.

` LINE (0,0)-(79,71) `
> Draws a diagonal line from the top left to lower right corner of the screen.

` LINE (10,10)-(20,20),2 `
> Draws a green line.

```
10 CLS
20 LINE -(RND(1)*80,RND(1)*72),RND(1)*16
30 GOTO 20
```
>  Draw lines forever using random attributes.

---
## LOAD Statement (updated)
Load File from USB Drive
### FORMAT:
 - LOAD *filespec*
   - Action: Load BASIC program *filespec* into memory
     - *filename* can be any string expression
     - If *filename* is shorter than 9 characters and does not contain a ".", the extension ".BAS" is appended.
     - File on USB drive must be in CAQ format. The internal filename is ignored.
     - If *filspec* is a literal string, the end quotation mark is optional.
 - LOAD *filespec* , \**arrayname*
   - Action: Load contents of array file *filespec* into array *arrayname*
     - If *filename* is shorter than 9 characters and does not contain a ".", the extension ".CAQ" is added.
     - File on USB drive mus be in CAQ format with the internal filename "######".
 - LOAD *filespec* , *address* [ , *length* [, *offset*]]
 - LOAD *filespec* , \**arrayname*
   - Action: Load contents of array file *filespec* into array *arrayname*
 - LOAD *filespec* , *address* [ , *length* [, *offset*]]
   - Action: Load contents of binary file *filespec* into memot
     - *length* specifies the number of bytes to load from the file
     - *offset* specifies the position in the file to start loadin from
### ERRORS
 - If *filespec* is not included, an MO Error results
 - If file *filespec* does not exist, an IO Error with DOS Error "file not found" results.
 - If only *filespec* is specified and the file is not a BASIC program in CAQ format, an IO Error with DOS Error "filetype mismatch" results.
 - If *arrayname* is specified and the array is not DIMmed, an FC Error results.
 - If *arrayname* is specified and the file is not array data in CAQ format, an IO Error with DOS Error "filetype mismatch" results.
### EXAMPLES:
` LOAD "progname.bas" `
> Load basic program into memory.

` LOAD "array.caq",*A `
> Load contents of file into array A().

` LOAD "capture.scr",12288 `
> Loads the file "capture.scr" into SCREEN RAM.

---
## LOCATE
Move the cursor to a specific column and row on the screen
### FORMAT:
 - LOCATE *column*,*row*
   - Action: Moves the cursor to the specified spot on the screen
     - *column* can be 1-38 (leftmost and rightmost columns cannot be used)
     - *row* can be 1-23 (topmost and bottommost rows cannot be used)
### EXAMPLES:
` LOCATE 1,1:print"Hello" `
> Prints `Hello` at top left of screen

` CLS:LOCATE 19,11:PRINT"&" `
> Clears the screen and prints `&` in the middle

---
## MENU
Display and execute menu.
### FORMAT:
  - MENU ( *xpos*,*ypos*) [, *spacing*;] *string* [,*string*,...] GOTO *line*, [,*line*...]
    - xpos* and *ypos* are the coordinates of the top left-most corner of the list of options display.
      - The list will actually start at (*xpos*+1, *ypos*), and the cursor will appear at (*xpos*,*ypos*).
      - The coordinates must fall in the target range (0,0) to (39,23), otherwise an FC error results..
    - "spacing" determines the number of blank lines between each menu item.
    - Each *string* identifies the menu items that will be printed on the screen.
      - Variables may be used here, but they must be defined before the MENU statement is executed.
      - Literal strings must be enclosed in quotation marks.
    - The subsequent GOTO statement indicates which part of the program to execute once a menu item has been selected.
      - Each *string* menu item corresponds to the *line* number in the same position.
      - If there is no corresponding line number, for a selected menu item, a UL error results.
### EXAMPLE:
```
10 CLS Clear the screen.
20 MENU(10,5),2,"CIRCLE","TRIANGLE","BOX"GOTO 100,200,300
100 CLS
110 CIRCLE (35,30),25
120 INPUT X
130 CLS
140 GOTO 20
200 CLS
210 LINE(10,10)-(40,40)
220 LINE-(50,25)
240 INPUT X
250 CLS
260 GOTO 20
300 CLS
310 LINE(30,30)-(70,70),,BF
320 INPUT X
330 CLS
340 GOTO 20
```

---
## MID$ Statement
  Replace a portion of one string with another string.
### FORMAT:
 - MID$ ( *var$* , *pos* [ , *len*] ) = *string*
   - Action: The contents of string variable *var$*, beginning at position *pos*, are replaced by the characters in *string*
     - if *pos* is less than 1 or more than 255, an FC error results
     - The optional *len* refers to the number of characters from *string* that will be used in the replacement
     - If *len* is omitted, all of *string* is used.
     - Regardless of whether *len* is omitted or included, the replacement of characters never goes beyond the original length of *var$*.
### EXAMPLE:
```
10 A$="KANSAS CITY, MO"
20 MID$(A$,14) ="KS"
30 PRINT A$
```
> Prints ` KANSAS CITY, KS `

---
## MKDIR
Create directory in current path
### FORMAT:
 - MKDIR "*dirname*"
   - Action: Create directory *dirname* in the current directory (see CD).
     - Returns without error if directory already exists.
     - Returns Disk I/O Error "file exists" if a file with the same name is in the current directory.
### EXAMPLE:
` MKDIR "mydir" `
> Creates new directory MYDIR in the current directory.

---
## ON ERROR
Enable or Disable error trapping.
### FORMAT:
  - ON ERROR GOTO *line number*
    - Action: Enables error trapping and specifies the first line of the error handling subroutine.
      - Once error trapping has been enabled all errors detected, including direct mode errors , will cause a jump to the specified error handling subroutine
      - If **line number* does not exist, an UL error results.
      - If an error occurs during execution of an error handling subroutine, the BASIC error message is printed and execution terminates.
        - Error trapping does not occur within the error handling subroutine.
  - ON ERROR GOTO 0
    - Action: Disables error trapping.
      - Subsequent errors will print an error message and halt execution.
      - An ON ERROR GOTO statement that appears in an error trapping subroutine causes MX BASIC to stop and print the error message for the error that caused the trap.
        - To prevent this, use CLEAR ERR or RESUME *line number* before the ON ERROR GOTO 0.
      - It is recommended that all error trapping subroutines execute an ON ERROR GOTO 0 if an error is encountered for which there is no recovery action.
### EXAMPLE:
```
10 ON ERROR GOTO 100
20 NEXT
30 PRINT "I get skipped"
100 PRINT ERR(-1)
110 PRINT ERR(0)
120 PRINT ERR(1)
```
> Sets line 100 as the error handler, forces an error (NEXT without FOR) in line 20, then jumps to 100 and prints `100` for the error handler line, then the error number, then the line the error occurred on `20`.

---
## OR Function
Bitwise OR
### FORMAT:
 - OR( *number1*, *number2* > )
   - Action: Returns the bitwise OR of two numbers.
     - Both *number1* and *number2* must be between -32768 and 65535.
     - Can be used instead of OR operator which only allows operands between -32768 and 32767.
### EXAMPLE:
` PRINT HEX$(OR($8080,$0808)) `
> Prints 8888

---
## OUT
Write to Z80 I/O Port
### FORMAT:
 - OUT *address*,*byte*
   - Action: Writes *byte* to the I/O port specified by LSB of *address*.
   - Advanced: During the write, *address* is put on the Z80 address bus.
### EXAMPLES:
` OUT 246, 12 `
> Send a value of 12 to the SOUND chip

` 10 X=14:OUT $FC, X `
> Send a value of 14 to the Cassette sound port

---
## PEEK Function (Enhanced)
Read Byte from Memory
### FORMAT:
 - PEEK( *address* )
   - Action: Returns contents of memory location *address*.
### EXAMPLES:
` PRINT CHR$(PEEK(12288)) `
> Print the current border character

` PRINT PEEK($3400) `
> Print the current border color value

---
## PEEK$ Function
Read String from Memory
### FORMAT:
 - PEEK( *address*, *length* )
   - Action: Returns a string containing *length* bytes from memory starting at location *address*.
     - Length must be between 0 and 255, inclusive.
     - If length is 0, an empty string is returned.
### EXAMPLES:
` PRINT PEEK$(12328,40) `
> Print the contents of screen line 1.

` PRINT HEX$(PEEK$(&A,4)) `
> Print the binary value floating point number in variable A as a hexadecimal number.

---
## POKE Statement (Enhanced)
Writes byte(s) to memory location(s)
### FORMAT:
 - POKE *address*, [ *byte or string*, *byte or string*... ] [,STEP *count*, *byte or string*...]
   - Action: Writes *byte or string* to *address*, followed by *address* STEP *count* addresses away...
 - POKE *address1* TO *address2* [STEP *count*], *byte*
   - Action: Writes *byte* to memory from *address1* TO *address2*.
     - If optional STEP *count* is specified then then then *count* minus 1 locations are skipped between writes.
       - FC Error if *count* is not between 1 and 255.
### EXAMPLES:
` POKE $3000+500,64 `
> Display `@` at screen center

` POKE 12347,7,6 `
> Display double-ended arrow

` POKE 12366,$13,STEP 39,$14 `
> Display standing person "sprite"

` POKE 12329,$D4,STEP 1023,$10 `
> Display red heart on black background

` POKE $3009,T$,5,C$ `
> Display T$, copyright, C$ on row 0

` POKE $3400 TO $3427,5 `
> Set border color to magenta

` POKE $3028 TO $33E7,$86 `
> Fill screen with checkerboard character

` POKE 12689 TO 12699 STEP 2,64 `
> Draws six @ characters on the screen, skipping one character location between each.

```
POKE 12367 TO 13287 STEP 40,255
POKE 13391 TO 14311 STEP 40,$16
```
> Draws a red vertical bar along the right side of the screen.

---
## POS Function (Enhanced)
Get Screen Position
### FORMAT:
 - POS( 0 )
   - Action: Returns current print column. This is one less than the actual screen column as set using LOCATE.
 - POS( 1 )
   - Action: Returns current screen column. This is the same as would be set by the first parameter of the LOCATE command.
 - POS( 2 )
   - Action: Returns current screen row. This is the same as would be set by the row parameter of the LOCATE command.
 - POS( 3 )
   - Action: Returns the screen RAM address corresponding to the current screen position.
 - POS( 4 )
   - Action: Returns the color RAM address corresponding to the current screen position.
 - POS( -1 )
   - Action: Returns last pixel X-coordinate as set by PSET, PRESET, LINE, or DRAW
 - POS( -2 )
   - Action: Returns last pixel Y-coordinate as set by PSET, PRESET, LINE, or DRAW
 - POS( -3 )
   - Action: Returns the last calculated screen RAM address,
     - The value returned is dependent on the last graphics command executed.
 - Any other arguments result in an FC Error.
### EXAMPLES:
` P = POS(0) `
> Sets P to current print position
` LOCATE POS(1)+1,POS(2)+1 `
> Moves cursor one character position down and to the right
` POKE POS(3),32 `
> Replaces the cursor with a space
` POKE POS(4),$70 `
> Changes the colors at the current screen position with white on black.

---
## PRESET Statement
Erase a pixel
### FORMAT:
  - PRESET [STEP] (*x-coord*,*y-coord*)
    - Action: Erases a pixel from the screen.
### EXAMPLES:
` PRESET (20,10) `
> Erases the pixel at column 20 of line 10.

` PRESET STEP (0,0) `
> Erases the pixel at the last referenced coordinates.

---
## PSET Statement (Enhanced)
Draw a pixel
### FORMAT:
  - PSET [STEP] (*x-coord*,*y-coord*) [ , *color* ]
    - Action: Draws a pixel on the screen.
### EXAMPLES:
` PSET (20,10) `
> Draws a pixel at x-coordinate 20 and y-coordinate 10.
` PSET (40,36),3 `
> Draws a yellow pixel at the center of the screen.

` PSET STEP (-10,8) `
> Draws a pixel at 10 points to the left of and 8 points below the last referenced Coordinates.

---
## PSG
Write to Programmable Sound Generator(s)
### FORMAT:
 - PSG *register*, *value* [, ...]
   - Action: Writes a *register* *value* pair to either PSG1 or PSG2
     - *register*  0-15 goes to PSG1 at $F7 (register) and $F6 (data)
     - *register* 16-31 goes to PSG2 at $F9 (register) and $F8 (data)
### EXAMPLES:
` PSG 8,15,0,148,1,1,7,56 `
> Play a Db4 note on PSG1 channel A, continuously

` PSG 8,0,7,0 `
> Turn the PSG1 sound off

` PSG 24,15,16,148,17,1,23,56 `
> Play a Db4 note on PSG2 channel A, continuously

` PSG 24,0,23,0 `
> Turn the PSG2 sound off

---
## PUT Statement
Copy data from a numeric array into a rectangle of screen data.
### FORMAT:
 - PUT (*x1*,*y1*)-(*x2*,*y2*),*arrayname* [,*operation*]
   - Action: Copies bytes from *arrayname* into a a rectangle of screen characters and colors.
     - The rectangle's upper left corner is at column *x1* on line *y1* and lower right corner is at column *x2* on line *y2*
     - *arrayname* must already be DIMensioned and populated with data.
     - *operation* determines what the foreground and background colors will be when the image is written onto the screen.
       - PSET overwrites the screen colors with the colors in the array.
       - PRESEST overites the screen colors with the ones-complement of the colors in the array.
       - SWAP overwrites the foreground colors on the screen with the backgrounds in the array and vice versa.
       - AND, OR, and XOR combine the color byte in the array with the screen color byte using the equivalent bit operation.
       - *Note:* If no operation is specified, the PSET operation is used .
     - See GET statement for copying from screen to array.

### EXAMPLE:
```
10 DIM A(8)
20 LOAD "CURSOR,SPR",*A
30 PUT (1,1)-(4,4),A,PSET
```
> Loads a file into array A, then displays the contents of in a 4x4 character/color grid at the upper left of the screen.

---
## RESUME Statement
Continue program execution after an error recovery procedure has been performed.
### FORMAT:
 - RESUME *line number*
   - Resumes execution at *line number*.
   - A RESUME statement that is not in an error trap routine causes an "RESUME without error" message to be printed*
### EXAMPLE:
```
10 ON ERROR GOTO 900
...
900 IF ERR(0)=120 AND ERR(1)=90 THEN PRINT "TRY AGAIN": RESUME 80
```

---
## RUN Statement (Enhanced)
Loads and runs BASIC programs (*.CAQ or *.BAS)
### FORMAT:
 - RUN *filename*
   - Action: Loads program into memory and runs it.
     - If *filename* is shorter than 9 characters and does not contain a ".", the extension ".BAS" is appended.
     - File on USB drive must be in CAQ format. The internal filename is ignored.
 - RUN "*filename*"
   - Action: Loads program named *filename* into memory and runs it.
     - If executed from within another BASIC program, the original program is cleared (same as NEW command) and the new program is loaded and executed in its place.
     - Wildcards and paths cannot be used.
### EXAMPLES:
` RUN "RUN-ME" `
> Loads and runs the file named `RUN-ME.BAS`. Note the program must exist within the current folder path.

` 10 PRINT "Loading Program..." `

` 20 RUN "NEXTPRG.CAQ" `
> Displays "Loading Program..." on screen and then immediately loads and runs the `NEXTPRG.CAQ` program.

---
## SAVE Statement (Updated)
Save File to USB Drive
### FORMAT:
 - SAVE "*filename*"
   - Action: Save BASIC program to file *filename* on USB drive.
     - *filename* can be any string expression
     - If *filename* is shorter than 9 characters and does not contain a ".", the extension ".BAS" is appended.
     - If *filspec* is a literal string, the end quotation mark is optional.
     - Advanced: File on USB drive will be in CAQ format with the internal filename set to the first 6 characters of *filename*.
 - SAVE "*filespec*",\**arrayname*
   - Action: Save contents of array *arrayname* to file *filename* on USB drive.
     - If *filename* is shorter than 9 characters and does not contain a ".", the extension ".CAQ" is added.
     - Advanced: File on USB drive will be in CAQ format with the internal filename set to "######".
 - SAVE *filespec*,*address*,*length*[,*offset*]
   - Action: Saves *length* bytes of memory starting at *address* to file *filename* on USB drive.
### ERRORS
 - If *filespec* is not included, an MO Error results
 - If file *filespec* does not exist, an IO Error with DOS Error "file not found" results.
 - If *arrayname* is specified and the array is not DIMmed, an FC Error results.
### EXAMPLES:
` SAVE "progname" `
> Save current program to USB drive with file name "PROGNAME.BAS"

` SAVE "progname." `
> Save current program to USB drive with file name "PROGNAME"

` SAVE "progname.caq" `
> Save current program to USB drive with file name "PROGNAME.CAQ"

` SAVE "array",*A `
> Save contents of array A() to USB drive with file name "ARRAY.CAQ"

` SAVE "capture.src",12288,2048 `
> Save Screen and Color RAM as raw binary file

---
## SDTM
Set DateTime
### FORMAT:
 - SDTM "*string*"
   - Action: If a Real Time Clock is installed, allows user to set the time on the Dallas DS1244Y RTC. DateTime string must be listed in "YYMMDDHHMMSS" format:
        - Improperly formatted string causes FC Error
        - DateTime is set by default to 24 hour mode,
          with cc (hundredths of seconds) set to 0
### EXAMPLES:
` SDTM "230411101500" `
> Sets DateTime to 11 APR 2023 10:15:00 (24 hour format)

` 10 SDTM "010101000000" `
> Sets DateTime to 01 JAN 2001 00:00:00 (24 hour format)

---
## SLEEP
Pause program execution.
### FORMAT:
 - SLEEP *number*
   - Action: Causes BASIC to pause for approximately *number* milliseconds.
     - If *number* is zero, does not pause.
     - Returns FC Error if *number* is not between 0 and 65535, inclusive.
     - Ctrl-C will interrupt the SLEEP command and the BASIC Program
### EXAMPLES:
` SLEEP 250 `
> Pauses for 1/4 second.

` SLEEP S `
> Pauses for S / 1000 seconds.

---
## STRING$
Create string of repeating characters.
### FORMAT:
 - STRING$ (*length*)
   - Action: Returns a string of *length* whose characters all spaces (ASCII code 32).
 - STRING$ (*length*, *byte* )
   - Action: Returns a string of *length* whose characters all have ASCII code *byte*.
 - STRING$ (*length*, *string* )
   - Action: Returns a string of *length* whose characters are all r the first character of *string*.
### EXAMPLE:
```
  10 X$ = STRING$ (10 , 45)
  20 PRINT X$ "MONTHLY REPORT" X$
```
Prints ` ----------MONTHLY REPORT---------- `

---
## SWAP
Swap variable contents.
### FORMAT:
 - SWAP *variable1*, *variable2*
   - Action: Exchanges the values of two variables.
     - The variables must be of the same type or a TM error results.
### EXAMPLE:
```
  10 A$=" ONE " : B$=" ALL ": C$="FOR"
  20 PRINT A$ C$ B$
  30 SWAP A$, B$
  40 PRINT A$ C$ B$
```
> Prints ` ONE FOR ALL ` then ` ALL FOR ONE `.

---
## SWAP Statement
Swap MSB and LSB
### FORMAT:
 - SWAP(*number*)
   - Action: Returns *number* with the least significant and most significant bytes swapped.
     - *number* must be between -32768 and 65535.
### EXAMPLES:
` PRINT HEX$(SWAP($ABCD)) `
> Prints CDAB

---
## VER
Returns 16 bit integer value of MX BASIC ROM version
### FORMAT:
 - VER(0)
   - Action: Returns integer of current MX BASIC ROM version
### EXAMPLES:
` PRINT VER(0) `
> Prints `512`

` PRINT HEX$(VER(0)) `
> Prints `0200`, the HEX value of version 2, rev 0

---
## WAIT Statement
Suspend program execution while monitoring the status of a Z80 input port.
### FORMAT:
 - WAIT *address*, *byte1* [, *byte2*]
   - Action: Causes execution to be suspended until a Z80 port develops a specified bit pattern.
     - The I/O port to read is specified by the LSB of *address*
     - The data read at the port is Exclusive OR'ed with *byte2*, then AND'ed with *byte1*.
     - If the result is zero, MX BASIC loops back and reads the data at the port again.
     - If the result is nonzero, execution continues with the next statement.
     - If *byte2* is omitted, it is assumed to be zero
   - Advanced: During the read, *address* is put on the Z80 address bus.
   - Caution: WAIT is not interrupted by Control-C. The RST key must be used to exit a WAIT that is in an infinite loop.
### EXAMPLE:
` WAIT $FF,$3F,$FF `
> Wait for any key to be pressed.

---
## XOR Function
Bitwise Exclusive OR
### FORMAT:
 - XOR( *number1*, *number2* )
   - Action: Returns the bitwise Exclusive OR of two numbers.
     - Both *number1* and *number2* must be between -32768 and 65535.
### EXAMPLE:
` PRINT HEX$(XOR($FFFF,$0808)) `
> Prints F7F7

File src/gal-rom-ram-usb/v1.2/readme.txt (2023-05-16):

files
=====

AQ_MX_RRU.PLD source code for use with WinCUPL http://www.atmel.com/tools/wincupl.aspx

AQ_MX_RRU.docx WinCUPL listing file (includes expanded logic terms, fuse map, chip pinouts)

AQ_MX_RRU.jed JEDEC file used to program GAL

Explanation of PLD Source Code
==============================

Syntax:-  

  ! = negate/invert signal
  # = logical OR
  & = logical AND

Pin assignment example:-

PIN 17 = !RAME ; 

  Designates pin 17 as variable 'RAME'. '!' = inverted (active low) at pin.  

Equations:-

RAME = !MREQ&(!RD#!WR)&(((A15&!A14&!LATCH)#(!A15&A14))#(A15&A14&LATCH&!RD));

The 32k static RAM is selected when MREQ is low and RD or WR is low, normally in the address range $4000-$BFFF. When the ROM remapping latch is set the lower 16k still has full read/write access at $4000-$7FFF, but the upper 16k is write-protected and accessed at $C000-$FFFF.  

LATCH = LATR&((!IORQ&!WR&!A7&!A6)#LATCH);

If LATR is low then the ROM remapping latch is forced into reset. This occurs on power up when the reset generator pulls LATR low. When LATR is released the latch can be set by writing to I/O address $00-$3F. Once set it remains so until the next power up, because the output is fed back into the input which holds it high (LATCH = ... OR LATCH). 

ROME = !MREQ&(!RD#!WR)&A15&A14&!LATCH; 

In this revision, the ROM device has been changed from a Winbond W27C512 256k (16kb x 4) EPROM to a Dallas DS1244Y Real-Time Clock (RTC) with 32k (16kb x 2) of NVRAM. The device functions in the same way as the ROM, but the Write Enable line has been added to the logic to allow access to the Phantom Clock functions. The ROM is enabled when reading memory addresses $C000-$FFFF, but only when the latch is reset. When the latch is set the ROM is disabled.

RA14 = A14&!(A15&LATCH);

RAM address line A14 normally passes straight through, but when the latch is set A14 is forced low when A15 is high. This causes the upper 16k to be addressed at $C000-$FFFF.

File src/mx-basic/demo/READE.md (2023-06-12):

# MX BASIC Demonstration Programs

| Program  | Description |
| --- | --- |
| keys.bas | Directlty reads keyboard using IN() function. Shows keys keys currently pressed. |

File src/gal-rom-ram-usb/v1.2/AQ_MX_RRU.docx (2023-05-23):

*******************************************************************************

AQ_MX_RRU v1.2

*******************************************************************************

CUPL(WM) 5.0a Serial# 60008009

Device g16v8ma Library DLIB-h-40-8

Created Sun Feb 12 08:24:00 2023

Name AQ_MX_RRU

Partno 0

Revision 02

Date 05/22/2023

Designer Sean Harrington, Mack Wharton, & Bruce Abbott

Company

Assembly

Location

===============================================================================

Expanded Product Terms

===============================================================================

CH376 =>

A6 & !A7 & !IORQ & !WR

# A6 & !A7 & !IORQ & !RD

LATCH =>

!A6 & !A7 & !IORQ & LATR & !WR

# LATCH & LATR

PRST =>

!RESET

RA14 =>

A14 & !A15

# A14 & !LATCH

RAME =>

A14 & A15 & LATCH & !MREQ & !RD

# A14 & !A15 & !MREQ & !RD

# A14 & !A15 & !MREQ & !WR

# !A14 & A15 & !LATCH & !MREQ & !WR

# !A14 & A15 & !LATCH & !MREQ & !RD

ROME =>

A14 & A15 & !LATCH & !MREQ & !RD # !WR

CH376.oe =>

1

LATCH.oe =>

1

LATR.oe =>

0

PRST.oe =>

1

RA14.oe =>

1

RAME.oe =>

1

ROME.oe =>

1

===============================================================================

Symbol Table

===============================================================================

Pin Variable Pterms Max Min

Pol Name Ext Pin Type Used Pterms Level

A5 16 V - - -

A6 1 V - - -

A7 2 V - - -

A14 3 V - - -

A15 4 V - - -

! CH376 12 V 2 7 1

IORQ 8 V - - -

LATCH 18 V 2 7 1

LATR 15 V - - -

MREQ 5 V - - -

PRST 13 V 1 7 1

RA14 19 V 2 7 1

! RAME 17 V 5 7 1

RD 6 V - - -

RESET 9 V - - -

! ROME 14 V 1 7 1

WR 7 V - - -

CH376 oe 12 D 1 1 0

LATCH oe 18 D 1 1 0

LATR oe 15 D 1 1 0

PRST oe 13 D 1 1 0

RA14 oe 19 D 1 1 0

RAME oe 17 D 1 1 0

ROME oe 14 D 1 1 0

LEGEND D : default variable F : field G : group

I : intermediate variable N : node M : extended node

U : undefined V : variable X : extended variable

T : function

===============================================================================

Fuse Plot

===============================================================================

Syn 02192 - Ac0 02193 -

Pin #19 02048 Pol - 02120 Ac1 -

00000 --------------------------------

00032 ----x----x----------------------

00064 ----x--x------------------------

00096 xxxxxxxxxxxxxxxxxxxxxxxxxxxxxxxx

00128 xxxxxxxxxxxxxxxxxxxxxxxxxxxxxxxx

00160 xxxxxxxxxxxxxxxxxxxxxxxxxxxxxxxx

00192 xxxxxxxxxxxxxxxxxxxxxxxxxxxxxxxx

00224 xxxxxxxxxxxxxxxxxxxxxxxxxxxxxxxx

Pin #18 02049 Pol - 02121 Ac1 -

00256 --------------------------------

00288 -x-x--------------x--x---x------

00320 ------x-----------x-------------

00352 xxxxxxxxxxxxxxxxxxxxxxxxxxxxxxxx

00384 xxxxxxxxxxxxxxxxxxxxxxxxxxxxxxxx

00416 xxxxxxxxxxxxxxxxxxxxxxxxxxxxxxxx

00448 xxxxxxxxxxxxxxxxxxxxxxxxxxxxxxxx

00480 xxxxxxxxxxxxxxxxxxxxxxxxxxxxxxxx

Pin #17 02050 Pol x 02122 Ac1 -

00512 --------------------------------

00544 ----x-x-x----x---x--------------

00576 ----x----x---x---x--------------

00608 ----x----x---x-------x----------

00640 -----x-xx----x-------x----------

00672 -----x-xx----x---x--------------

00704 xxxxxxxxxxxxxxxxxxxxxxxxxxxxxxxx

00736 xxxxxxxxxxxxxxxxxxxxxxxxxxxxxxxx

Pin #16 02051 Pol x 02123 Ac1 -

00768 xxxxxxxxxxxxxxxxxxxxxxxxxxxxxxxx

00800 xxxxxxxxxxxxxxxxxxxxxxxxxxxxxxxx

00832 xxxxxxxxxxxxxxxxxxxxxxxxxxxxxxxx

00864 xxxxxxxxxxxxxxxxxxxxxxxxxxxxxxxx

00896 xxxxxxxxxxxxxxxxxxxxxxxxxxxxxxxx

00928 xxxxxxxxxxxxxxxxxxxxxxxxxxxxxxxx

00960 xxxxxxxxxxxxxxxxxxxxxxxxxxxxxxxx

00992 xxxxxxxxxxxxxxxxxxxxxxxxxxxxxxxx

Pin #15 02052 Pol x 02124 Ac1 -

01024 xxxxxxxxxxxxxxxxxxxxxxxxxxxxxxxx

01056 xxxxxxxxxxxxxxxxxxxxxxxxxxxxxxxx

01088 xxxxxxxxxxxxxxxxxxxxxxxxxxxxxxxx

01120 xxxxxxxxxxxxxxxxxxxxxxxxxxxxxxxx

01152 xxxxxxxxxxxxxxxxxxxxxxxxxxxxxxxx

01184 xxxxxxxxxxxxxxxxxxxxxxxxxxxxxxxx

01216 xxxxxxxxxxxxxxxxxxxxxxxxxxxxxxxx

01248 xxxxxxxxxxxxxxxxxxxxxxxxxxxxxxxx

Pin #14 02053 Pol x 02125 Ac1 -

01280 --------------------------------

01312 ----x--xx----x---x--------------

01344 xxxxxxxxxxxxxxxxxxxxxxxxxxxxxxxx

01376 xxxxxxxxxxxxxxxxxxxxxxxxxxxxxxxx

01408 xxxxxxxxxxxxxxxxxxxxxxxxxxxxxxxx

01440 xxxxxxxxxxxxxxxxxxxxxxxxxxxxxxxx

01472 xxxxxxxxxxxxxxxxxxxxxxxxxxxxxxxx

01504 xxxxxxxxxxxxxxxxxxxxxxxxxxxxxxxx

Pin #13 02054 Pol - 02126 Ac1 -

01536 --------------------------------

01568 -----------------------------x--

01600 xxxxxxxxxxxxxxxxxxxxxxxxxxxxxxxx

01632 xxxxxxxxxxxxxxxxxxxxxxxxxxxxxxxx

01664 xxxxxxxxxxxxxxxxxxxxxxxxxxxxxxxx

01696 xxxxxxxxxxxxxxxxxxxxxxxxxxxxxxxx

01728 xxxxxxxxxxxxxxxxxxxxxxxxxxxxxxxx

01760 xxxxxxxxxxxxxxxxxxxxxxxxxxxxxxxx

Pin #12 02055 Pol x 02127 Ac1 -

01792 --------------------------------

01824 -xx------------------x---x------

01856 -xx--------------x-------x------

01888 xxxxxxxxxxxxxxxxxxxxxxxxxxxxxxxx

01920 xxxxxxxxxxxxxxxxxxxxxxxxxxxxxxxx

01952 xxxxxxxxxxxxxxxxxxxxxxxxxxxxxxxx

01984 xxxxxxxxxxxxxxxxxxxxxxxxxxxxxxxx

02016 xxxxxxxxxxxxxxxxxxxxxxxxxxxxxxxx

LEGEND X : fuse not blown

- : fuse blown

===============================================================================

Chip Diagram

===============================================================================

______________

| Aqu_mem |

A6 x---|1 20|---x Vcc

A7 x---|2 19|---x RA14

A14 x---|3 18|---x LATCH

A15 x---|4 17|---x !RAME

MREQ x---|5 16|---x A5

RD x---|6 15|---x LATR

WR x---|7 14|---x !ROME

IORQ x---|8 13|---x PRST

RESET x---|9 12|---x !CH376

GND x---|10 11|---x

|______________|

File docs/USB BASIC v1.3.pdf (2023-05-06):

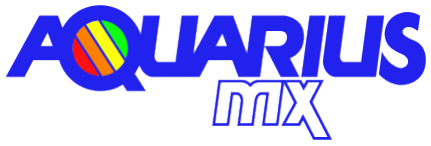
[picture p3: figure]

# USB BASIC v1.3

Supplemental BASIC Commands for Aquarius MX Aquarius System Development
Sean Harrington, Designer

Deck
1-0

1-0

# OVERVIEW

### USB BASIC is a set of commands and functions that extend the original

Aquarius BASIC language for use with the Aquarius MX expander.

- Works on Aquarius MX and Micro Expander modules
- Leverages USB drive for rapid access to digital storage
- Implements a RTC (Real Time Clock) for TimeDate functionality
- Expands addressing capabilities of BASIC commands
- Runs as a ROM, so Ext BASIC is not accessible (Aquarius II and modded Aquarius)

1-0

# NEW FEATURES

- Numeric references in most BASIC commands updated
- Can accept signed integers (-32768 to 32767)
- Can accept unsigned integers (0 to 65535)
- Can accept hexadecimal values ($0000 to $FFFF)
- Support for Dallas DS1244Y RTC (RealTime Clock) for DateTime functions
- PEEK & POKE commands expanded
- Can accept auto-incrementing start address with multiple trailing values
- Can accept start address and TO keyword with end address for repeated single value
- Can accept STEP keywords for counts, followed by one or more bytes
- PT3 Player has been migrated to a standalone ROM file (PT3PLAY.ROM)

1-0

# SCHEDULE

Plan for roll-out of USB BASIC v1.3

1-0

# TESTING & ROLLOUT

- Alpha Testers needed to run test plans on real and emulated hardware
- 5 MAY 2023 – Test plans ready; Test ROM available to download and burn
- 10 MAY 2023 – Alpha Testing complete
- Beta Testers needed to run unstructured tests on real and emulated hardware
- 11 MAY 2023 – Final ROM and documentation ready to download and test
- 16 MAY 2023 – All testing complete
- 17 MAY 2023 – General Release (TARGET)
- Integrators to begin offering replacement ROMs
- Instructions on RTC installation for existing Hardware complete

1-0

# COMMANDS

Review of Original and New USB BASIC Commands

1-0

# COMMANDS - ORIGINAL

- ATN( )
- CALL xx
- CAT
- CD “ “
- CLS x
- COPY aa,bb,cc
- DEBUG
- DEC( )
- DEEK( )
- DEF FN
- DEL “ “
- DIR
- DOKE xx, zz
- DTM$( )
- EDIT
- HEX$( )
- IN( )
- JOY( )
- KEY( )
- LOAD “ “, x
- LOCATE x,y
- OUT x, z
- PSG( )
- RUN “ “
- SAVE “ “, xx, z
- SDTM “ “
- VER( )

1-0

# COMMANDS – NEW, v1.3

- ATN( )
- CALL xx
- CAT
- CD “ “
- CLS x
- COPY aa,bb,cc
- DEBUG
- DEC( )
- DEEK( )
- DEF FN
- DEL “ “
- DIR
- DOKE xx, zz
- DTM$( )
- EDIT
- HEX$( )
- IN( )
- JOY( )
- KEY( )
- LOAD “ “, x
- LOCATE x,y
- OUT x, z
- PSG( )
- RUN “ “
- SAVE “ “, xx, z
- SDTM “ “
- VER( )

1-0

# ATN( )

Mathematical function that returns the arctangent of a number. The result is the angle (in radians) whose tangent is the number fed to the function.
EXAMPLES:

## PRINT ATN(0)

10 J=12

## 20 X=ATN(J)*180/3.14159

1-0

# CALL xx

Causes the Aquarius to jump to a machine code routine at the address given. EXAMPLES:

## CALL 8192

## 20 CALL $4000

1-0

# CAT

Displays a brief listing of the files in the current directory of the USB drive (immediate mode only!).
EXAMPLE:

## CAT

<.. | > <DATA | > RUN-ME BAS
<SCR | >

1-0

CD “ “

Changes the Current Directory of the USB drive to the one supplied, otherwise, displays the name of the Current Directory.
EXAMPLES:

## CD “DATA”

CD

## /DATA

CD “..” | (Goes to previous directory)

1-0

# CLS x

Clears the screen of all color and text to a default black text on cyan background (value 6), unless a value for color is supplied: (FG * 16) + BG
EXAMPLES:

## CLS

## 10 CLS 9

## 10 CLS $0006

1-0

# COPY aa,bb,cc

Copies a section of memory starting from address aa to the address beginning at bb for a size of cc bytes.
EXAMPLES:
COPY $3000,$3000+440,120 | Copy the top three lines of characters on the screen to the middle of the screen
10 COPY $C000,$8000,$4000 | Copy the memory in the cartridge space to the top 16k of the 32k expansion

1-0

# DEBUG

Launches the built-in AquBug Debugger in the Aquarius MX ROM. EXAMPLE:

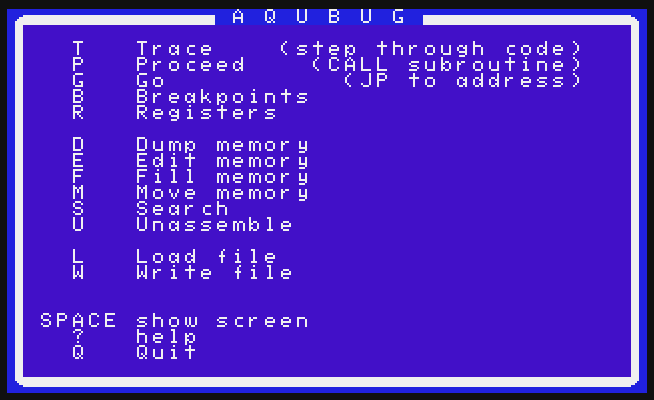
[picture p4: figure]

## DEBUG

1-0

# DEC( )

Returns the DECimal value of the hexadecimal number in <string>. EXAMPLES:

## PRINT DEC(“FFFF”) Prints 65535

## 10 A$=HEX$(32)

20 PRINT DEC(A$) | Prints 32

1-0

# DEEK( ) – “DOUBLE PEEK”

Reads a word from memory location <address>, returning a number between 0 and 65535.
EXAMPLES:
POKE DEEK(14337),PEEK(14349) | Remove cursor from screen
10 PRINT DEEK($384B) | Prints the top of BASIC memory address

1-0

# DEF FN / FN

This sets up a user-defined function that can be used later in the program. The function can consist of any mathematical formula.
EXAMPLES:

## 10 DEF FN A(X)=X+7

20 PRINT FN A(9) | Prints 16 (9 + 7)

1-0

# DEL “ “

Deletes the file or directory supplied in quotes.
EXAMPLES:
DEL “RUN-ME.BAS” | Deletes file named run-me.bas

## 20 A$=“data.bin”

10 DEL A$ | Deletes filename in A$, data.bin

1-0

# DIR

Displays a complete listing of the files in the current directory of the USB drive, with file type and size (immediate mode only!).
EXAMPLE:

## DIR

.. | <dir> data | <dir>
run-me | BAS 139 splash SCR 2048
Ok

1-0

# DOKE xx, zz – “DOUBLE POKE”

Write 16 bit (2 byte) word to Memory Location(s).
EXAMPLES:
DOKE 14340,1382 | Set USR() function address
DOKE $3028,$6162 | Put the characters ab at the top left of the screen

1-0

# DTM$( )

If a RTC (Real Time Clock) is installed, returns a DateTime string in one of two formats. EXAMPLES:

PRINT DTM$(0) | Prints 23051208140700 (YYMMDDHHMMSSCC)

## 10 A$=DTM$(1)

20 PRINT LEFT$(A$,10) | Prints 2023-05-12
30 PRINT RIGHT$(A$,8) | Prints 08:14:07

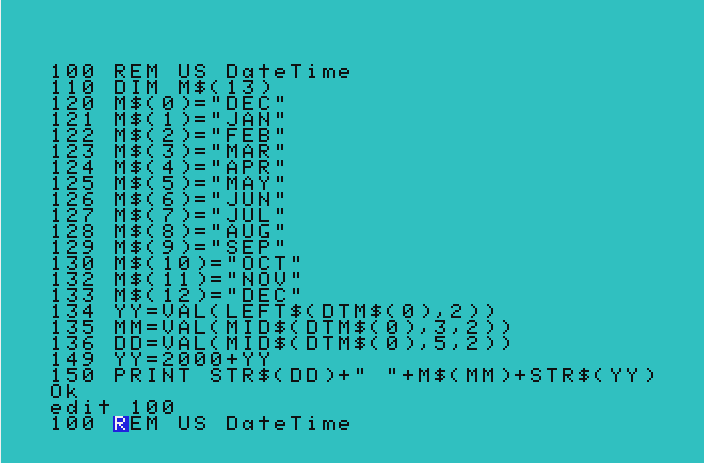
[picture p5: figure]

1-0

# EDIT

Activates the built-in, single line BASIC editor in the Aquarius MX ROM. DETAILS:

## CURSOR is shown as BLUE box with WHITE text

CTRL + P | = cursor left
CTRL + / | = cursor right

## DELETE/BKSP = delete char left of cursor text keyed = adds text at cursor RETURN = enters/commits edits

1-0

# HEX$( )

Returns string containing <number> in two-byte hexadecimal format. EXAMPLES:

PRINT HEX$(255) | Prints 00FF
10 PRINT HEX$(PEEK(12288)) | Prints 0020

1-0

IN( )

Reads a byte from the I/O port specified by LSB of <address>. EXAMPLES:

PRINT IN(252) | Prints cassette port input status
10 S=IN($FE) | Set variable S to Printer Ready status

1-0

# JOY( )

Reads an input value from the joystick(s).
EXAMPLES:
PRINT JOY(0) | Prints value from either joystick/control pad
10 Z=JOY(1) | Set variable Z to value from left joystick/control pad
50 PRINT HEX$(JOY(2)) | Prints hex value from right joystick/control pad

1-0

# KEY( )

Reads a key value input from the keyboard.
EXAMPLES:
PRINT HEX$(KEY(0)) | Wait until a key is pushed and print hex value
10 A=KEY(1000) | Scan the keyboard up to 1000 times or until a key is pushed, and assign the value to variable a

1-0

# LOAD “ “, aa

Loads a file into memory at the specified address. The following filetypes don’t require an address, as the system knows where to load them: .CAQ, .ROM, .BAS, .SCR. EXAMPLES:
LOAD “RUN-ME.BAS” | Loads file named run-me.bas
20 LOAD “data.bin”,8192 | Loads file named data.bin to address 8192
40 LOAD “splash.scr” | Loads file named splash.scr to CHRRAM and COLRAM

1-0

# LOCATE x, y

Moves the cursor to a specified column and row on the screen. Note that in immediate mode, the cursor returns to the next row, so the command is more useful in a BASIC program loop.
EXAMPLES:
LOCATE 1,0 | Moves cursor to first character of top row
10 LOCATE 20,12 | Moves cursor to the middle of the screen
20 PRINT CHR$(KEY(0)) | and prints the character of the first key pressed

1-0

# OUT x, z

Sends a value (z) to the specified IO device (x).
EXAMPLES:
OUT 246, 12 | Send a value of 12 to the SOUND chip
10 X=14:OUT $FC, X | Send a value of 14 to the Cassette sound port

1-0

# PSG x, z, …

Send a value (z) to the specified sound chip register (x). Multiple pairs of values may be strung together separated by commas.
EXAMPLES:
PSG 8,15,9,15,10,15 | Set volume of all sound channels to 15 (max)
10 PSG 8,15,0,148,1,1,7,56 | Play a Db4 on channel A, and wait for a key
20 A=KEY(0):PSG 8,0 | press before stopping the sound

1-0

# RUN “ “

Loads a file into memory and runs it. Only works properly with the following filetypes: .CAQ, .ROM, .BAS. (Note that old program will be overwritten!)
EXAMPLES:
RUN “SNAFU.ROM” | Loads and runs file named SNAFU.rom
20 RUN “game.bas” | Loads and runs file named game.bas

1-0

# SAVE “ “, aa, zz

Saves a file from memory address (aa) for a specified length (zz). If no address and length are given, it assumed to save from BASIC program space, and should be given a .BAS suffix by user when named.
EXAMPLES:
SAVE “TESTER.BAS” | Saves the current BASIC program to a file

## named TESTER.BAS

20 SAVE “DATA.BIN”,$8000,32 Saves 32 bytes of memory starting at $8000 to a file named DATA.BIN

1-0

# SDTM “ “

If a RTC (Real Time Clock) is installed, sets the date when the string is entered in the format “YYMMDDHHMMSS”. Note that the century is assumed to be 20, and the centiseconds are assumed to be 00.
EXAMPLES:

## SDTM “230512081407” Sets RTC to 2023-05-12 08:14:07

## 10 SDTM “010101000000” Sets RTC to 2001-01-01 00:00:00

1-0

# VER( )

Returns the current version of USB BASIC. The value in parenthesis is typically 0, but can be any integer between -32768 and 65535.
EXAMPLES:
PRINT HEX$(VER(0)) | Prints 0103 for USB BASIC v1.3
20 A=VAL(HEX$(VER(0))) | Checks version and prints No if less
30 IF A<103 THEN PRINT “No” | than 103.

1-0

# QUESTIONS?

- Visit GitHub site at https://github.com/1stage/Aquarius-MX
- Email Sean Harrington, sph@1stage.com

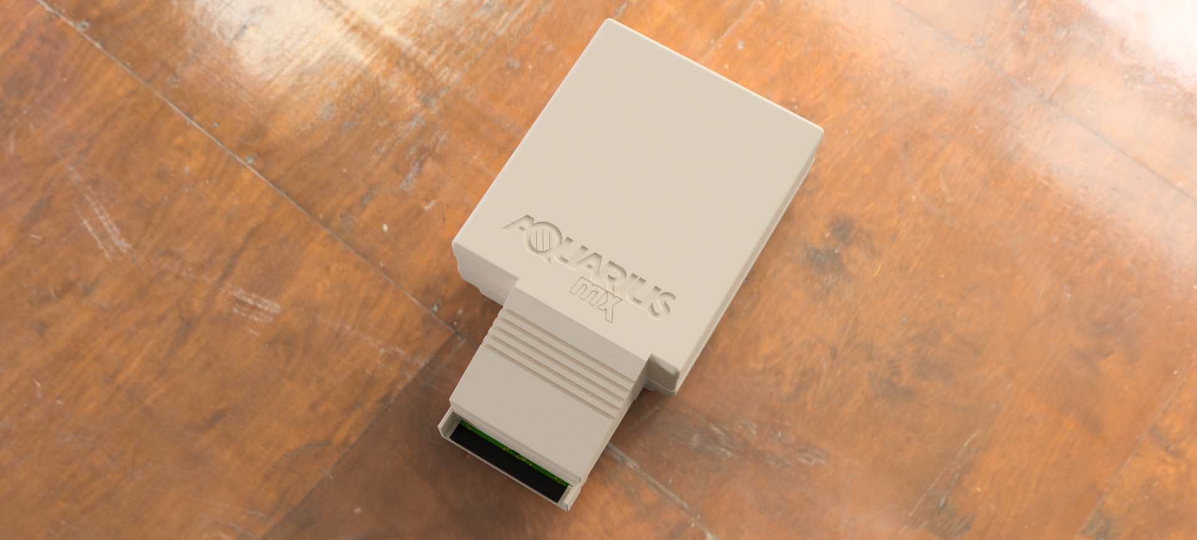
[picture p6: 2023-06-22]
img/Aquarius MX Case.png

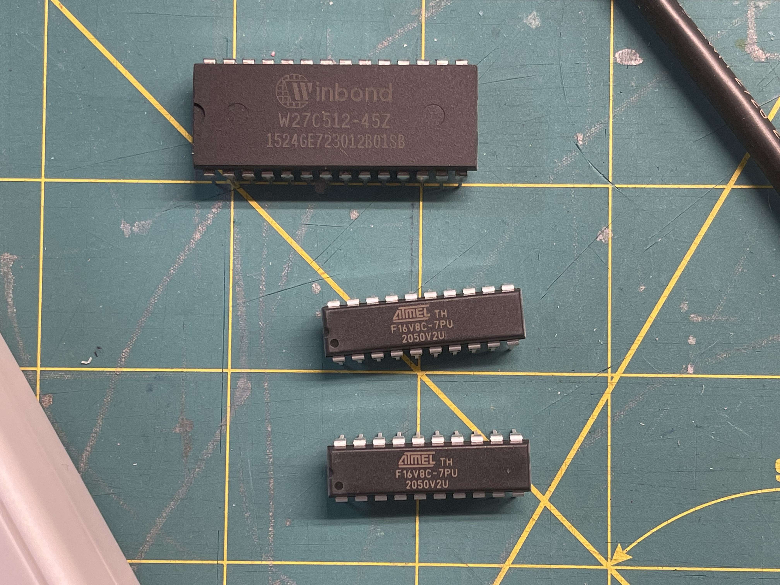
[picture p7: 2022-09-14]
img/aq_mx_chips.jpg

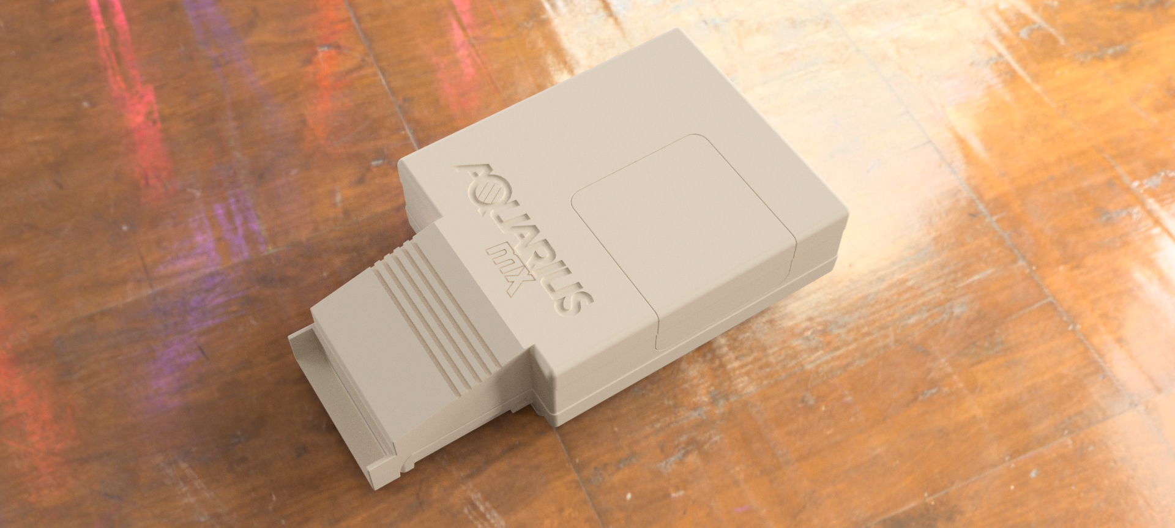
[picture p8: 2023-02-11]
img/Aquarius MX Expansion Door.png

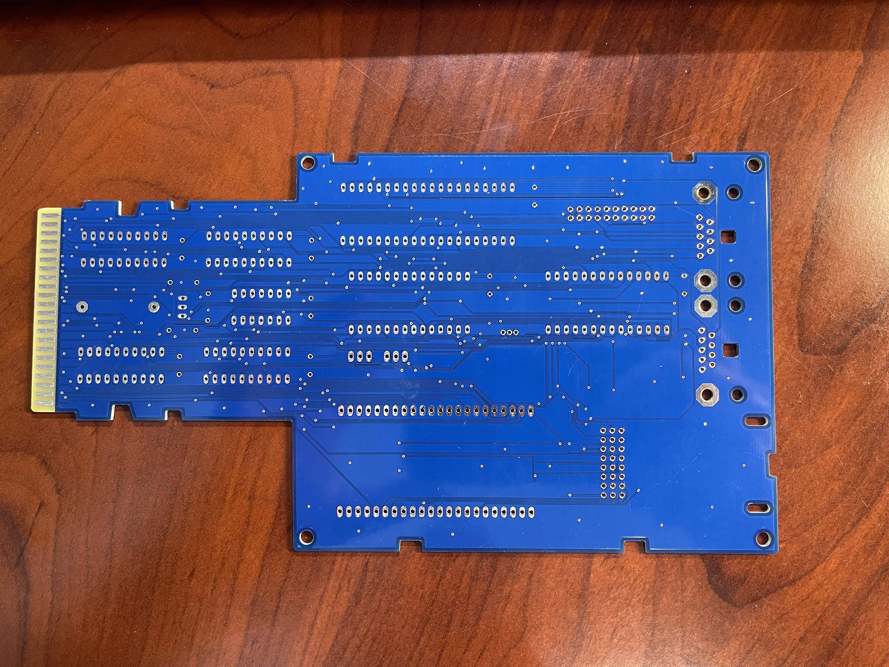
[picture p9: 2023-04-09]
img/aq_mx_pcb_bottom.jpg

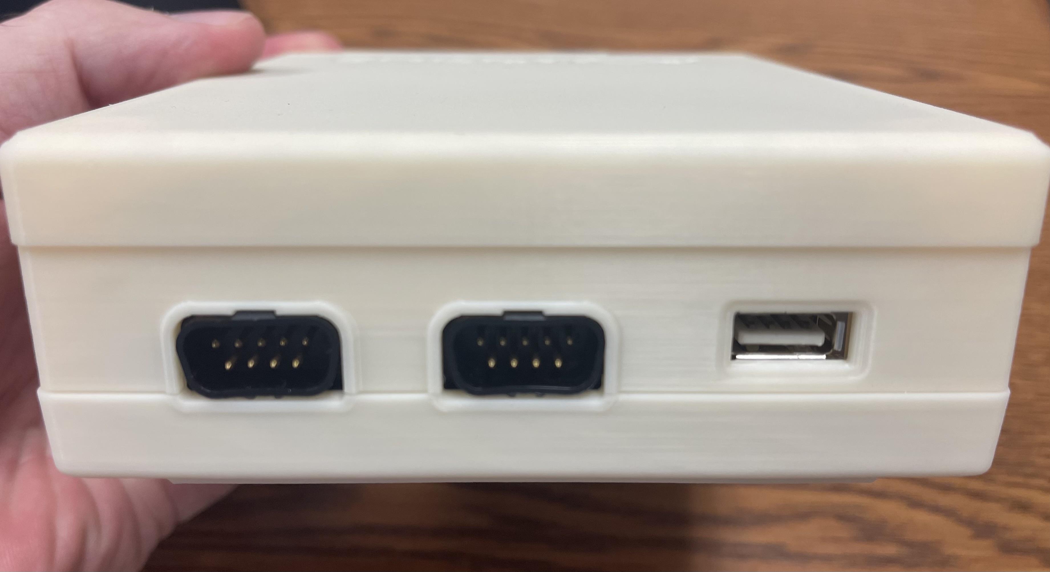
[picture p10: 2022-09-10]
img/aq_mx_back_ports.jpg

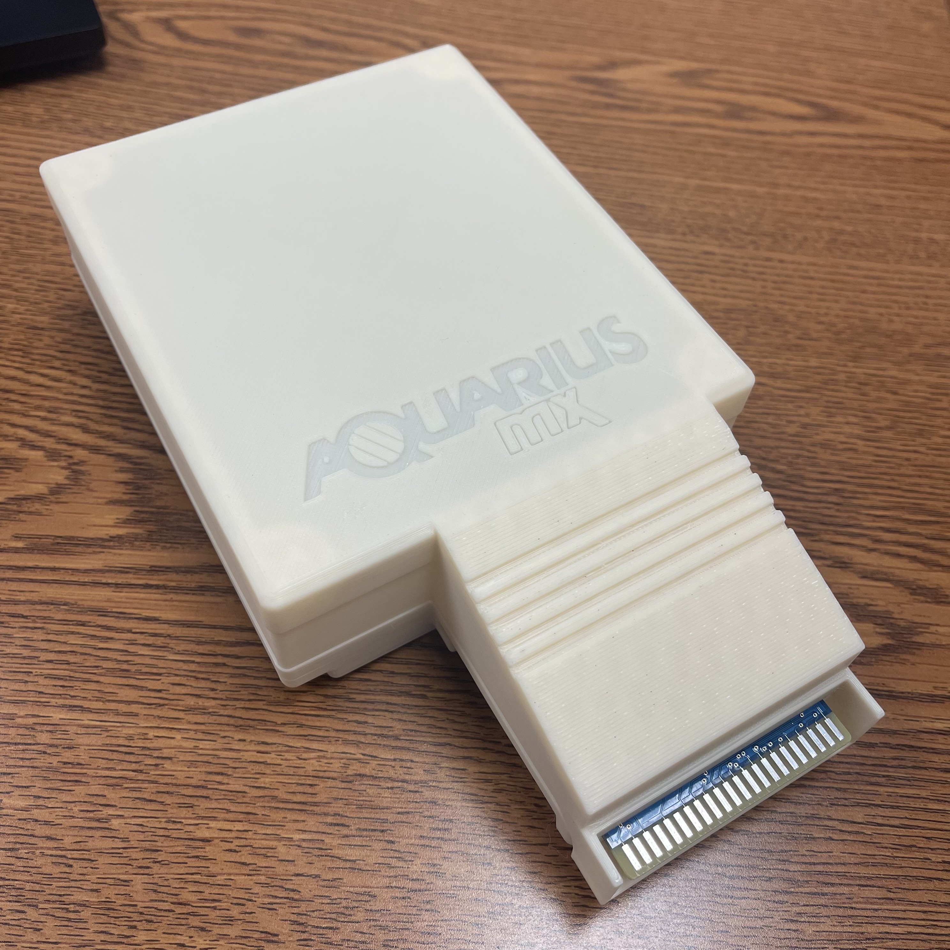
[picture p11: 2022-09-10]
img/aq_mx_on_desk_close.jpg

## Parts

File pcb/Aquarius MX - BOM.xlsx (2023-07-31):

Order Qty. | Description | EST Price (USD) | EST Ext. Price: (USD) | Notes | Link
1 | Aquarius MX PCB - v1.4.0 Rev C (Blue PCB) | $6.16 | $6.16 | As of 16 AUG 2022, 10 @ PCBs are US$24.66, DHL Shipping is $36.72 via JLCPB
1 | 3D printed shell, top & bottom | $7.00 | $7.00 | Assumes about 1/4 of a 1kg roll of "skin tone" PLA 1.75mm, @ about 36 hours of printing | https://www.amazon.com/gp/product/B01N7R2CZL/ref=ppx_yo_dt_b_search_asin_title?ie=UTF8&psc=1
4 | #4 1/2" Pan Head Phillips Screw for Plastic, 20tpi | $0.10 | $0.40 | Use hot glue or 2-part putty in screw holes if your screws are too small | https://www.mcmaster.com/catalog/129/3370/90380A110
4 | Rubber feet | $0.10 | $0.40 | Required to keep unit at cartridge port height | https://www.amazon.com/gp/product/B01LDLJG2W/ref=ppx_yo_dt_b_asin_title_o00_s00?ie=UTF8&psc=1
1 | 2x10 keyed male vertical pin header | $0.37 | $0.37 | Control IO header | https://www.amazon.com/gp/product/B00VGDRKYO/ref=ppx_yo_dt_b_asin_title_o05_s00?ie=UTF8&psc=1
1 | 2x8 female vertical pin header | $1.50 | $1.50 | USB header; can mount for internal USB or external USB connection | https://www.amazon.com/Glarks-Straight-Connector-Assortment-Prototype/dp/B076H25ZB8
2 | DIL20-4 IC socket | $1.00 | $2.00 | GAL sockets | https://www.amazon.com/uxcell-2-54mm-Soldering-Socket-Adaptor/dp/B07H3RPFH8?s=industrial
1 | DIL28-6 IC socket | $1.00 | $1.00 | Sound chip socket | https://www.amazon.com/Glarks-122Pcs-Sockets-Adaptor-Assortment/dp/B01GOLSUAU
1 | DIL40-6 IC socket | $2.00 | $2.00 | ROM socket | https://www.amazon.com/Glarks-122Pcs-Sockets-Adaptor-Assortment/dp/B01GOLSUAU
2 | CONN D-SUB PLUG 9POS R/A SOLDER | $11.33 | $22.66 | DB9 Control Pad connectors, can use either indicated plastic variety or standard metal DB9 ports | https://www.arrow.com/en/products/5745001-3/te-connectivity?q=5745001-3
1 | CH376S U-Disk Read Write Module USB | $9.00 | $9.00 | USB Interface board, can accept either Type A or Type B boards. | https://www.ebay.com/sch/i.html?_from=R40&_trksid=p2380057.m570.l1313&_nkw=ch376s&_sacat=0
8 | 0.1uF 104 100nF Multilayer Monolithic Ceramic Capacitor 5.08mm | $0.70 | $5.60 | Chip filter/balance caps | https://www.amazon.com/gp/product/B08B3VCK42/ref=ppx_yo_dt_b_asin_title_o03_s00?ie=UTF8&psc=1
1 | 10uF @ 16v (or higher) Axial Electrolytic Capacitor | $0.25 | $0.25 | 5v balance cap (63v rating is typical but anything >16v will work)
1 | 4.7K ohm 1/4w metal film resistor, axial | $0.10 | $0.10
1 | 47 ohm 1/4w metal film resistor, axial | $0.10 | $0.10
1 | 10k ohm 1/4w metal film resistor, axial | $0.10 | $0.10
1 | BC548 NPN TO-92 Transistor (CBE) | $0.50 | $0.50
1 | DS1233 Econo Reset controller T0-92 | $1.00 | $1.00 | DS1233D-10-T-R | https://www.digikey.com/en/products/detail/analog-devices-inc-maxim-integrated/DS1233D-10-T-R/956854
2 | 74LS244N DIL20-4 Address Buffer | $1.25 | $2.50 | soldered
1 | 74LS74N Clock Divider DIP14 | $1.25 | $1.25 | soldered
1 | CY62256LL-PC RAM DIP28 | $5.00 | $5.00 | 32k RAM - soldered
1 | 27C512AP Winbond EEPROM DIP28-6 | $7.00 | $7.00 | Socketed
2 | GAL16V8 Logic Chip DIP20 | $0.50 | $1.00 | Socketed
1 | General Instruments AY-3-8910 Sound Chip | $13.00 | $13.00 | Socketed
2 | 1x3 Right Angle pin header | $1.00 | $2.00 | ROM select lines
2 | Pin header jumper | $0.05 | $0.10 | ROM select lines
2 | 10mm Nylon mounting spacers M2.5 single pass | $0.25 | $0.50 | USB board mounting hardware | https://www.amazon.com/gp/product/B08HS7694T/ref=ppx_yo_dt_b_search_asin_title?ie=UTF8&th=1
2 | Nylon mounting nuts M2.5 | $0.10 | $0.20 | USB board mounting hardware | https://www.amazon.com/gp/product/B07LFXL1KH/ref=ppx_yo_dt_b_search_asin_title?ie=UTF8&psc=1
4 | Nylon washers M.25 | $0.05 | $0.20 | USB board mounting hardware | https://www.amazon.com/gp/product/B07CRBVDF3/ref=ppx_yo_dt_b_search_asin_title?ie=UTF8&psc=1
2 | 6mm Nylon mounting screws M2.5 | $0.20 | $0.40 | USB board mounting hardware | See Mounting Spacers link above
1 | 32Gb USB Drive, slim size | $6.30 | $6.30 | USB thumb drive, formatted FAT32 | https://www.amazon.com/dp/B018SVZZ0W/?coliid=I156AO276GUR1G
47 | TOTAL |  | $99.59 | ESTIMATED

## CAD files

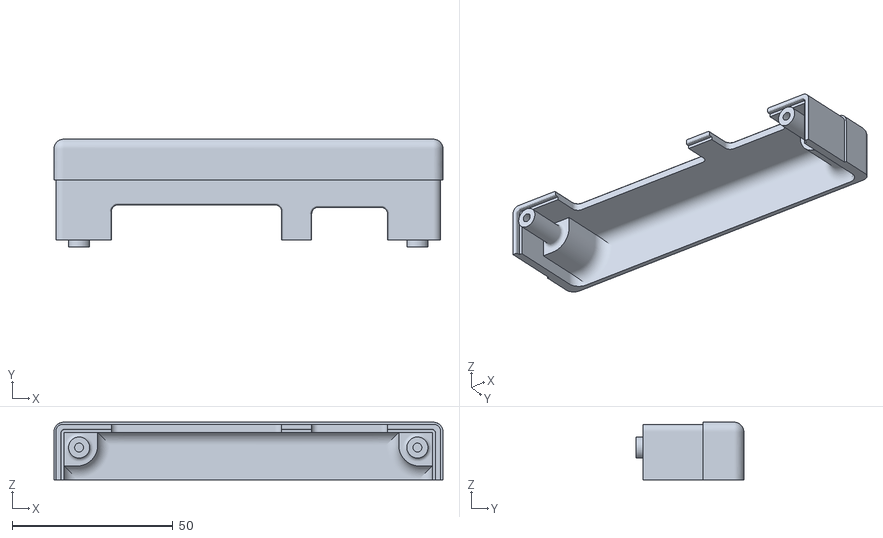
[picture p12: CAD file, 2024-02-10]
case/Top Ports.stl
120.9 x 33.5 x 17.9

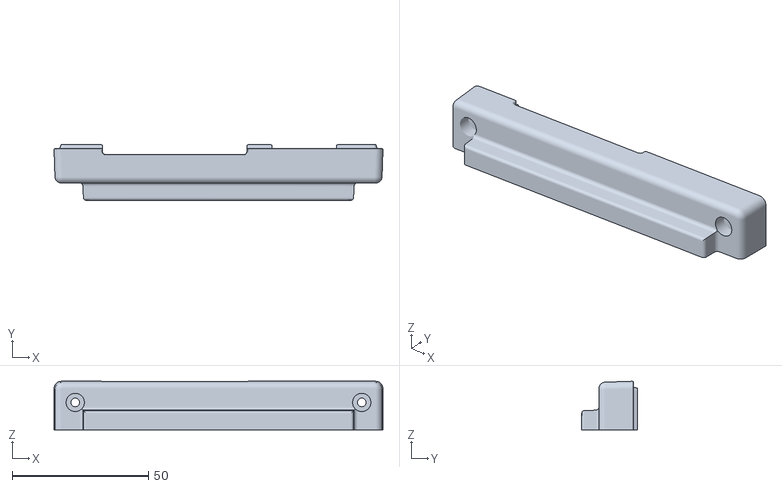
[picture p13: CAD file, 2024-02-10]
case/Base Ports.stl
120.7 x 20.4 x 17.8

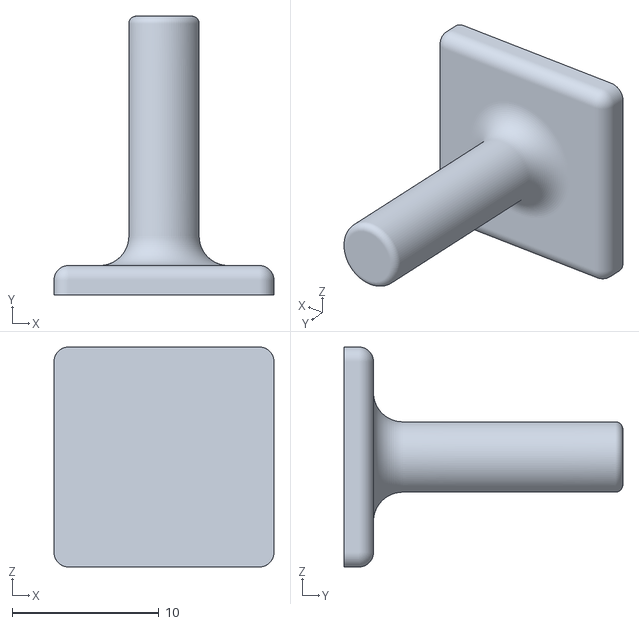
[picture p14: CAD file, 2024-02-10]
case/aq_mx_rtc_foot.stl
15.0 x 19.0 x 15.0

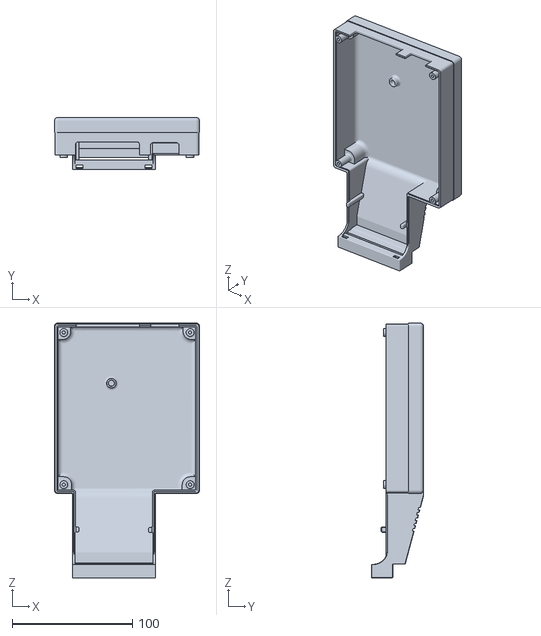
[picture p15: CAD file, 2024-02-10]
case/aq_mx_case_top.stl
120.9 x 43.5 x 212.1

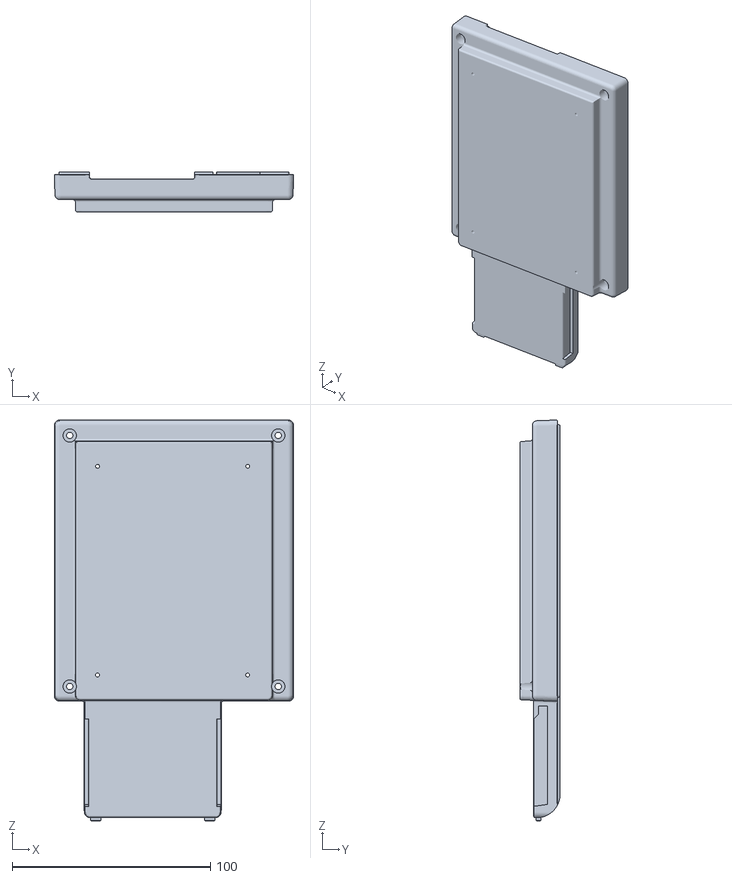
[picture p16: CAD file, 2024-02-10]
case/aq_mx_case_bottom.stl
120.7 x 20.4 x 202.2

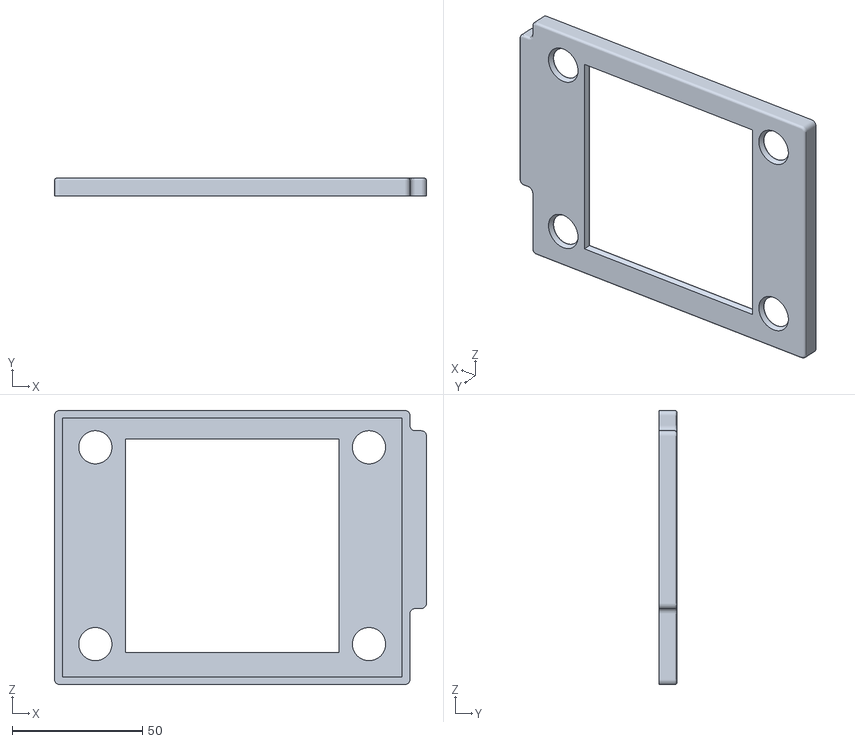
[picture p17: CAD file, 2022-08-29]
case/aq_mx_base_template.stl
143.0 x 7.00 x 105.5

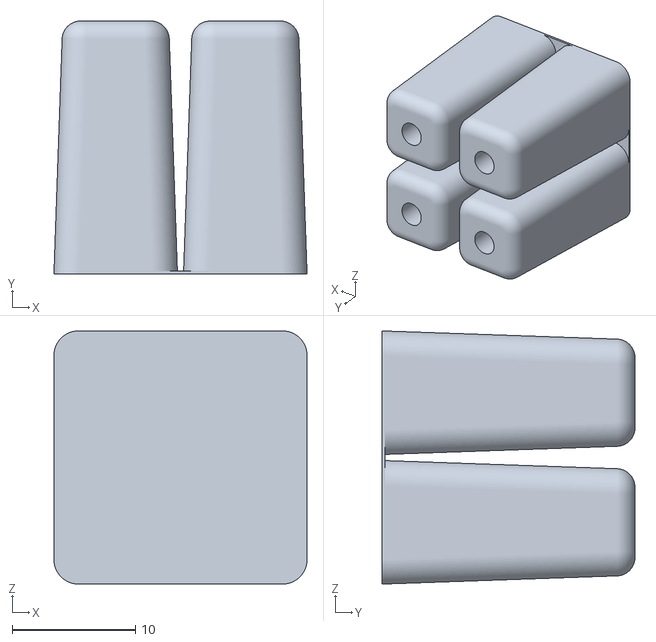
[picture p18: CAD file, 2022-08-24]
case/aq_mx_pcb_feet.stl
20.5 x 20.5 x 20.5

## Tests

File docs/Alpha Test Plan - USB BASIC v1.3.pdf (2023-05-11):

Alpha Test Plan - USB BASIC v1.3.xlsx

Tester Name:

Date Completed:

E1

Environment(s) Tested: | AquaLite S2 + Micro Expander Option
Test No | Environment | Description | Process | Expected Results | Actual Results ("As Expected" ok) | Pass/Fail | Initials | Date/Time
E-1.0.0 | AL S2 + MX | Setup AquaLite v1.36
E-1.0.1 | AL S2 + MX | | Download & install AquaLite v1.36 from https://aquarius.je/aqualite (unzip files) | AquaLite v1.36 is downloaded and installed on your system.
E-1.0.2 | AL S2 + MX | | Launch AquaLite v1.36. (aqualite.exe) | System should boot into "BASIC Press RETURN key to start" flashing screen. Menubar should say AquaLite v1.36.
E-1.0.3 | AL S2 + MX | | Within AquaLite v1.36, go to menu option Tool > Options, select the Peripherals tab, and make sure Micro Expander is checked. Click Ok. | System should beep and reboot.
E-1.0.4 | AL S2 + MX | | Press the A key within the emulator. | The "About USB BASIC" screen should be displayed. Release Date should show "Alpha 2023-05-09".
E-1.0.5 | AL S2 + MX | | Press any key to exit the About screen. | The "Aquarius MX USB BASIC v1.3" screen should be displayed.
E-1.0.6 | AL S2 + MX | | Press RETURN/ENTER key to go to the USB BASIC command screen. Note: This screen is the starting point for most tests in this plan. | The "Copyright © 1982 by Microsoft, Inc S2" screen should be displayed with "USB BASIC v1.3" on the next line, followed by "Ok" on the next line with a cursor below.
Test No | Environment | Description | Process | Expected Results | Actual Results ("As Expected" ok) | Pass/Fail | Initials | Date/Time
E-1.1.0 | AL S2 + MX | Test legacy commands
E-1.1.1.1 | AL S2 + MX | Test CALL xx | From the USB BASIC command screen type CALL $8000 and hit RETURN | The cursor should move down one row, and the system should freeze.
E-1.1.1.2 | AL S2 + MX | | From the AquaLite menu, select File > Hard Reset, and then hit the RETURN/ENTER key to go to USB BASIC. | The "Copyright © 1982 by Microsoft, Inc S2" screen should be displayed with "USB BASIC v1.3" on the next line, followed by "Ok" on the next line with a cursor below.
E-1.1.1.3 | AL S2 + MX | | From the USB BASIC command screen type CALL -32768 and hit RETURN | The cursor should move down one row, and the system should freeze.
E-1.1.1.4 | AL S2 + MX | | From the AquaLite menu, select File > Hard Reset, and then hit the RETURN/ENTER key to go to USB BASIC. | The "Copyright © 1982 by Microsoft, Inc S2" screen should be displayed with "USB BASIC v1.3" on the next line, followed by "Ok" on the next line with a cursor below.
E-1.1.1.5 | AL S2 + MX | | From the USB BASIC command screen type CALL 32768 (NO minus sign!) and hit RETURN | The cursor should move down one row, and the system should freeze.
E-1.1.1.6 | AL S2 + MX | | From the AquaLite menu, select File > Hard Reset, and then hit the RETURN/ENTER key to go to USB BASIC. | The "Copyright © 1982 by Microsoft, Inc S2" screen should be displayed with "USB BASIC v1.3" on the next line, followed by "Ok" on the next line with a cursor below.
E-1.1.2 | AL S2 + MX | Test CAT | From the USB BASIC command screen type CAT and hit RETURN | System should display a brief listing of the contents of the USB folder within the AquaLite program folder, followed by Ok beneath. Note that the contents can vary from system to system.
E-1.1.3.1 | AL S2 + MX | Test CD | From the USB BASIC command screen type CD and hit RETURN | The cursor should move down one row, and a / character should be displayed, followed by Ok beneath.
E-1.1.3.2 | AL S2 + MX | | From the USB BASIC command screen type CD"ROMS" and hit RETURN | The cursor should move down one row and display Ok beneath.
E-1.1.4 | AL S2 + MX | Test DIR | From the USB BASIC command screen type DIR and hit RETURN | System should display a detailed listing of the contents of the USB > ROMS folder within the AquaLite program folder, followed by Ok beneath. Note that the RETURN/ENTER key may have to be pressed one or more times to scroll through the full list of contents.
E-1.1.5.1 | AL S2 + MX | Test CLS | From the USB BASIC command screen type CLS and hit RETURN | System should clear the screen and show Ok in black letters on a cyan background.
E-1.1.5.2 | AL S2 + MX | | From the USB BASIC command screen type CLS 8 and hit RETURN | System should clear the screen and show Ok in black letters on a grey background.
E-1.1.5.3 | AL S2 + MX | | From the USB BASIC command screen type CLS $7D and hit RETURN | System should clear the screen and show Ok in white letters on a dark green background.
E-1.1.5.4 | AL S2 + MX | | From the USB BASIC command screen type CLS and hit RETURN | System should clear the screen and show Ok in black letters on a cyan background.

# Alpha Test Plan USB BASIC v1.3

DO NOT CONTINUE IF ANY TESTS IN THIS SECTION DID NOT PASS! CONTACT THE TESTING COORDINATOR, Sean Harrington sph@1stage.com.

## Setup

## Legacy Commands

Test No | Environment | Description | Process | Expected Results | Actual Results ("As Expected" ok) | Pass/Fail | Initials | Date/Time
E-1.1.6.1 | AL S2 + MX | Test SAVE a BASIC file | From the USB BASIC command screen type NEW and hit RETURN | System should display Ok beneath.
E-1.1.6.2 | AL S2 + MX | | From the USB BASIC command screen type the code below and hit RETURN after each line: 10 REM Testing SAVE 20 CLS 30 PRINT “Hello” | System should show each line typed, and move down to the empty line beneath.
E-1.1.6.3 | AL S2 + MX | | From the USB BASIC command screen type LIST and hit RETURN | System should show all three lines in the program and display Ok beneath.
E-1.1.6.4 | AL S2 + MX | | From the USB BASIC command screen type SAVE "TEST01.BAS" and hit RETURN | The cursor should move down one row and display Ok beneath. In the USB > ROMS folder within the AquaLite program folder, there should be a new file named TEST01.BAS.
E-1.1.6.5 | AL S2 + MX | | From the USB BASIC command screen type CAT and hit RETURN | System should display a brief listing of the contents of the folder, and the "TEST01.BAS" file should be lised among those files. Note that the RETURN/ENTER key may have to be pressed one or more times to scroll through the full list of contents.
E-1.1.7.1 | AL S2 + MX | Test LOAD a BASIC file | From the USB BASIC command screen type NEW and hit RETURN | System should display Ok beneath.
E-1.1.7.2 | AL S2 + MX | | From the USB BASIC command screen type LIST and hit RETURN | System should display NO PROGRAM LINES with Ok beneath.
E-1.1.7.3 | AL S2 + MX | | From the USB BASIC command screen type LOAD "TEST01.BAS" and hit RETURN | System should display Ok beneath.
E-1.1.7.4 | AL S2 + MX | | From the USB BASIC command screen type LIST and hit RETURN | System should show all three lines in the program listed in test E-1.1.6.2 and display Ok beneath.
E-1.1.8.1 | AL S2 + MX | Test RUN a BASIC file | From the USB BASIC command screen type NEW and hit RETURN | System should display Ok beneath.
E-1.1.8.2 | AL S2 + MX | | From the USB BASIC command screen type RUN "TEST01.BAS" and hit RETURN | System should clear the screen, print Hello at the top, and display Ok beneath.
E-1.1.9.1 | AL S2 + MX | Test DEL | From the USB BASIC command screen type DEL "TEST01.BAS" and hit RETURN | System should display Ok beneath.
E-1.1.9.2 | AL S2 + MX | | From the USB BASIC command screen type CAT and hit RETURN | System should display a brief listing of the contents of the folder, and the "TEST01.BAS" file SHOULD NOT be lised among those files. Note that the RETURN/ENTER key may have to be pressed one or more times to scroll through the full list of contents.
E-1.1.10.1 | AL S2 + MX | Test SAVE a BIN file | From the USB BASIC command screen type NEW and hit RETURN | System should display Ok beneath.
E-1.1.10.2 | AL S2 + MX | | From the USB BASIC command screen type the code below and hit RETURN after each line: 10 REM Testing SAVE BIN 20 POKE $8000,97,98,99,100 30 PRINT “Done” | System should show each line typed, and move down to the empty line beneath.
E-1.1.10.3 | AL S2 + MX | | From the USB BASIC command screen type LIST and hit RETURN | System should show all three lines in the program and display Ok beneath.
E-1.1.10.4 | AL S2 + MX | | From the USB BASIC command screen type RUN and hit RETURN | System should print Done and display Ok beneath the program listing.
E-1.1.10.5 | AL S2 + MX | | From the USB BASIC command screen type CD "/" and hit RETURN | System should display Ok beneath.
E-1.1.10.6 | AL S2 + MX | | From the USB BASIC command screen type the code below and hit RETURN: SAVE "POKE.BIN", $8000, 4 | System should display Ok beneath.
E-1.1.10.7 | AL S2 + MX | | From the USB BASIC command screen type DIR and hit RETURN | System should display a detailed listing of the contents of the USB folder within the AquaLite program folder, and the file named "POKE.BIN" should be listed in the contents. Note that the RETURN/ENTER key may have to be pressed one or more times to scroll past the full list of contents.
E-1.1.11.1 | AL S2 + MX | Test LOAD a BIN file | From the AquaLite menu, select File > Hard Reset, and then hit the RETURN/ENTER key to go to USB BASIC. | The "Copyright © 1982 by Microsoft, Inc S2" screen should be displayed with "USB BASIC v1.3" on the next line, followed by "Ok" on the next line with a cursor below.
E-1.1.11.2 | AL S2 + MX | | From the USB BASIC command screen type the code below and hit RETURN: LOAD "POKE.BIN", $3242 | System should display abcd in the middle of the screen, with Ok beneath the text you just typed.

Test No | Environment | Description | Process | Expected Results | Actual Results ("As Expected" ok) | Pass/Fail | Initials | Date/Time
E-1.1.12.1 | AL S2 + MX | Test RUN a ROM file | From the AquaLite menu, select File > Hard Reset, and then hit the RETURN/ENTER key to go to USB BASIC. | The "Copyright © 1982 by Microsoft, Inc S2" screen should be displayed with "USB BASIC v1.3" on the next line, followed by "Ok" on the next line with a cursor below.
E-1.1.12.2 | AL S2 + MX | | From the USB BASIC command screen type CD"ROMS" and hit RETURN | The cursor should move down one row and display Ok beneath.
E-1.1.12.3 | AL S2 + MX | | From the USB BASIC command screen type the code below and hit RETURN: RUN "SNAFU.ROM" | System should load the SNAFU game ROM and display the SNAFU title screen.
E-1.1.12.4 | AL S2 + MX | | From the AquaLite menu, select File > Hard Reset, and then hit the RETURN/ENTER key to go to USB BASIC. | The "Copyright © 1982 by Microsoft, Inc S2" screen should be displayed with "USB BASIC v1.3" on the next line, followed by "Ok" on the next line with a cursor below.
E-1.1.13.1 | AL S2 + MX | Test DEBUG | From the USB BASIC command screen type DEBUG and hit RETURN | The AQUBUG screen should pop up with white text on a blue background.
E-1.1.13.2 | AL S2 + MX | | On the AQUBUG screen type the letter Q | System should return to the USB BASIC command screen, showing the DEBUG command with Ok beneath.
E-1.1.14.1 | AL S2 + MX | Test HEX$ | From the USB BASIC command screen type the code below and hit RETURN: PRINT HEX$(12288) | System should display 3000 on the next line with Ok beneath.
E-1.1.14.2 | AL S2 + MX | | From the USB BASIC command screen type the code below and hit RETURN: PRINT HEX$(-123) | System should display FF85 on the next line with Ok beneath.
E-1.1.14.3 | AL S2 + MX | | From the USB BASIC command screen type the code below and hit RETURN: PRINT HEX$(65535) | System should display FFFF on the next line with Ok beneath.
E-1.1.15 | AL S2 + MX | Test JOY | From the USB BASIC command screen type the code below and try to type RETURN and the 1 key at about the same time (maybe a slight delay before the 1 key): PRINT JOY(0) | System should display 64 on the next line with Ok beneath. If you weren't able to get it to work exactly right, a 0 might be displayed instead of the 64. Try a couple of times to get it to work, if you can.
E-1.1.16 | AL S2 + MX | Test IN | From the USB BASIC command screen type the code below and hit RETURN: PRINT IN($FF) | System should display 247 on the next line with Ok beneath.
E-1.1.17.1 | AL S2 + MX | Test PSG | From the USB BASIC command screen type the code below and hit RETURN: PSG 8,15,0,148,1,1,7,56 | System should play a Db4 tone continuously.
E-1.1.17.2 | AL S2 + MX | | From the USB BASIC command screen type the code below and hit RETURN: PSG 8,0,7,0 | System should stop playing the tone.
E-1.1.18.1 | AL S2 + MX | Test OUT | From the USB BASIC command screen type the code below and hit RETURN: PSG 8,15,0,148,1,1,7,56 | System should play a Db4 tone continuously and print Ok beneath.
E-1.1.18.2 | AL S2 + MX | | From the USB BASIC command screen type the code below and hit RETURN after each line: OUT 247,8 OUT $F6,0 | System should print Ok after each RETURN, and then should stop playing the tone after the second.
E-1.1.19.1 | AL S2 + MX | Test EDIT | From the AquaLite menu, select File > Hard Reset, and then hit the RETURN/ENTER key to go to USB BASIC. | The "Copyright © 1982 by Microsoft, Inc S2" screen should be displayed with "USB BASIC v1.3" on the next line, followed by "Ok" on the next line with a cursor below.
E-1.1.19.2 | AL S2 + MX | | From the USB BASIC command screen type the code below and hit RETURN: 10 REM Testing EDIT | System should show each line typed, and move down to the empty line beneath.
E-1.1.19.3 | AL S2 + MX | | From the USB BASIC command screen type the code below and hit RETURN: EDIT 10 | System should list the previously entered line 10 with a blue cursor and white text positioned over the R in the REM command.
E-1.1.19.4 | AL S2 + MX | | Within the line 10 edit with the cursor on the R of REM, press the SPACE bar to insert a space between the line number 10 and the REM statement. | System should display line 10 with a SPACE between the 10 and the REM command.
E-1.1.19.5 | AL S2 + MX | | Within the line 10 edit with the cursor on the R of REM, CTRL + / eleven times so the cursor is on top of the SPACE after the word Testing. | System should list the previously entered line 10 with a blue cursor and white text positioned over the SPACE after the word Testing.
E-1.1.19.6 | AL S2 + MX | | Within the line 10 edit with the cursor on the SPACE between the word Testing and EDIT, press the DELETE/BACKSPACE key three times to delete the letters "ing" at the end of the word Testing. | System should list the previously entered line 10 with a blue cursor and white text positioned over the SPACE before the word EDIT.
E-1.1.19.7 | AL S2 + MX | | Within the line 10 edit with the cursor on the SPACE between the word Test and EDIT, press CTRL + P eight times so the cursor is over the letter R in REM, and then hit RETURN/ENTER. | The cursor should go to the line beneath line 10, and should NOT display Ok beneath.
E-1.1.19.8 | AL S2 + MX | | From the USB BASIC command screen type the code below and hit RETURN: LIST 10 | System should display a blank line, then list line 10 again, with Ok beneath.

Test No | Environment | Description | Process | Expected Results | Actual Results ("As Expected" ok) | Pass/Fail | Initials | Date/Time
E-1.1.20.1 | AL S2 + MX | Test LOCATE | From the USB BASIC command screen type the code below and hit RETURN after each line: 10 CLS 20 LOCATE 20,12 30 PRINT CHR$(KEY(0)) | System should show each line typed, and move down to the empty line beneath.
E-1.1.20.2 | AL S2 + MX | | From the USB BASIC command screen type RUN and hit RETURN | System should move the cursor to the middle of the screen.
E-1.1.20.3 | AL S2 + MX | | With the cursor in the middle of the screen, press the G key. | System should display a "g" in the middle of the screen, then go to the next line and print Ok beneath.
E-1.1.20.4 | AL S2 + MX | | From the AquaLite menu, select File > Hard Reset, and then hit the RETURN/ENTER key to go to USB BASIC. | The "Copyright © 1982 by Microsoft, Inc S2" screen should be displayed with "USB BASIC v1.3" on the next line, followed by "Ok" on the next line with a cursor below.
E-1.1.21.1 | AL S2 + MX | Test CTRL + C | From the AquaLite menu, select File > Hard Reset. Do NOT hit RETURN. Stay on the AquaLite menu. | The "Aquarius MX USB BASIC v1.3" screen should be displayed. There should NOT be an option near the bottom that says "<CTRL+C> Warm Start"
E-1.1.21.2 | AL S2 + MX | | Hit the RETURN/ENTER key to go to USB BASIC. | The "Copyright © 1982 by Microsoft, Inc S2" screen should be displayed with "USB BASIC v1.3" on the next line, followed by "Ok" on the next line with a cursor below.
E-1.1.21.3 | AL S2 + MX | | From the AquaLite menu, select File > Soft Reset. Do NOT hit RETURN. Stay on the AquaLite menu. | The "Aquarius MX USB BASIC v1.3" screen should be displayed. There SHOULD be an option near the bottom that says "<CTRL+C> Warm Start"
E-1.1.21.4 | AL S2 + MX | | Press CTRL + C. | A blank screen with "Break", followed by "Ok" on the next line with a cursor below.
Test No | Environment | Description | Process | Expected Results | Actual Results ("As Expected" ok) | Pass/Fail | Initials | Date/Time
E-1.2.0 | AL S2 + MX | Test NEW commands
E-1.2.1.1 | AL S2 + MX | Test POKE auto-increment | From the AquaLite menu, select File > Hard Reset, and then hit the RETURN/ENTER key to go to USB BASIC. | The "Copyright © 1982 by Microsoft, Inc S2" screen should be displayed with "USB BASIC v1.3" on the next line, followed by "Ok" on the next line with a cursor below.
E-1.2.1.2 | AL S2 + MX | | From the USB BASIC command screen type the code below and hit RETURN: POKE 12945,97,98,99,100 | The screen should print abcd in a row towards the middle bottom of the screen.
E-1.2.2.1 | AL S2 + MX | Test POKE range | From the USB BASIC command screen type CLS and hit RETURN | System should clear the screen and show Ok.
E-1.2.2.2 | AL S2 + MX | | From the USB BASIC command screen type the code below and hit RETURN: POKE $3291 TO $3299,97 | The screen should print aaaaaaaaa (nine letter a's) in a row towards the middle bottom of the screen.
E-1.2.3.1 | AL S2 + MX | Test POKE step | From the USB BASIC command screen type CLS and hit RETURN | System should clear the screen and show Ok.
E-1.2.3.2 | AL S2 + MX | | From the USB BASIC command screen type the code below and hit RETURN: POKE $3291,97,STEP 40,97,STEP 40,97 | The screen should print aaa (three letter a's) in a downward line at the middle bottom of the screen.
E-1.2.4.1 | AL S2 + MX | Test POKE strings | From the USB BASIC command screen type CLS and hit RETURN | System should clear the screen and show Ok.
E-1.2.4.2 | AL S2 + MX | | From the USB BASIC command screen type the code below and hit RETURN: POKE $3291,"Hubba",STEP 40,"Bubba" | The screen should print the words Hubba Bubba stacked on top of each other at the middle bottom of the screen.
E-1.2.5.1 | AL S2 + MX | Test COPY | From the AquaLite menu, select File > Hard Reset, and then hit the RETURN/ENTER key to go to USB BASIC. | The "Copyright © 1982 by Microsoft, Inc S2" screen should be displayed with "USB BASIC v1.3" on the next line, followed by "Ok" on the next line with a cursor below.
E-1.2.5.2 | AL S2 + MX | | From the USB BASIC command screen type the code below and hit RETURN: COPY $3000,$3000+440,120 | The text at the top of the screen ("Copyright © 1982 by Microsoft, Inc S2" & "USB BASIC v1.3" should be duplicated in the middle of the screen, with the Ok beneath the COPY command near the top.
E-1.2.6.1 | AL S2 + MX | Test ATN | From the AquaLite menu, select File > Hard Reset, and then hit the RETURN/ENTER key to go to USB BASIC. | The "Copyright © 1982 by Microsoft, Inc S2" screen should be displayed with "USB BASIC v1.3" on the next line, followed by "Ok" on the next line with a cursor below.
E-1.2.6.2 | AL S2 + MX | | From the USB BASIC command screen type the code below and hit RETURN: PRINT ATN(1) | System should display .785398 on the next line with Ok beneath.
E-1.2.7.1 | AL S2 + MX | Test DEC | From the USB BASIC command screen type CLS and hit RETURN | System should clear the screen and show Ok .
E-1.2.7.2 | AL S2 + MX | | From the USB BASIC command screen type the code below and hit RETURN: PRINT DEC("55FF") | System should display 22015 on the next line with Ok beneath.
E-1.2.8.1 | AL S2 + MX | Test DEEK | From the USB BASIC command screen type CLS and hit RETURN | System should clear the screen and show Ok .
E-1.2.8.2 | AL S2 + MX | | From the USB BASIC command screen type the code below and hit RETURN: PRINT HEX$(DEEK(12288+41)) | System should display 6B4F on the next line with Ok beneath. ($4F is the "O" character and $6B is the "k" character from the top left of the screen.)

PLEASE CONTINUE EVEN IF ALL TESTS IN THIS SECTION DID NOT PASS.
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

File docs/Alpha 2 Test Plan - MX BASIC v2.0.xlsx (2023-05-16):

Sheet: AL-S2-MX
Alpha Test Plan |  | Tester Name:
MX BASIC v2.0 |  | Date Completed:
E1 |  | Environment(s) Tested: | AquaLite S2 + Micro Expander Option
Setup
Test No | Environment | Description | Process | Expected Results | Actual Results ("As Expected" ok) | Pass/Fail | Initials | Date/Time
E-1.0.0 | AL S2 + MX | Setup AquaLite v1.36
E-1.0.1 | AL S2 + MX |  | Download & install AquaLite v1.36 from https://aquarius.je/aqualite (unzip files) | AquaLite v1.36 is downloaded and installed on your system.
E-1.0.2 | AL S2 + MX |  | Launch AquaLite v1.36. (aqualite.exe) | System should boot into "BASIC Press RETURN key to start" flashing screen. Menubar should say AquaLite v1.36.
E-1.0.3 | AL S2 + MX |  | Within AquaLite v1.36, go to menu option Tool > Options, select the Peripherals tab, and make sure Micro Expander is checked. Click Ok. | System should beep and reboot.
E-1.0.4 | AL S2 + MX |  | Press the A key within the emulator. | The "About MX BASIC" screen should be displayed. Release Date should show "Alpha 2023-05-09".
E-1.0.5 | AL S2 + MX |  | Press any key to exit the About screen. | The "Aquarius MX MX BASIC v2.0" screen should be displayed.
E-1.0.6 | AL S2 + MX |  | Press RETURN/ENTER key to go to the MX BASIC command screen. Note: This screen is the starting point for most tests in this plan. | The "Copyright © 1982 by Microsoft, Inc S2" screen should be displayed with "MX BASIC v2.0" on the next line, followed by "Ok" on the next line with a cursor below.
DO NOT CONTINUE IF ANY TESTS IN THIS SECTION DID NOT PASS! CONTACT THE TESTING COORDINATOR, Sean Harrington sph@1stage.com.
Legacy Commands
Test No | Environment | Description | Process | Expected Results | Actual Results ("As Expected" ok) | Pass/Fail | Initials | Date/Time
E-1.1.0 | AL S2 + MX | Test legacy commands
E-1.1.1.1 | AL S2 + MX | Test CALL xx | From the MX BASIC command screen type CALL $8000 and hit RETURN | The cursor should move down one row, and the system should freeze.
E-1.1.1.2 | AL S2 + MX |  | From the AquaLite menu, select File > Hard Reset, and then hit the RETURN/ENTER key to go to MX BASIC. | The "Copyright © 1982 by Microsoft, Inc S2" screen should be displayed with "MX BASIC v2.0" on the next line, followed by "Ok" on the next line with a cursor below.
E-1.1.1.3 | AL S2 + MX |  | From the MX BASIC command screen type CALL -32768 and hit RETURN | The cursor should move down one row, and the system should freeze.
E-1.1.1.4 | AL S2 + MX |  | From the AquaLite menu, select File > Hard Reset, and then hit the RETURN/ENTER key to go to MX BASIC. | The "Copyright © 1982 by Microsoft, Inc S2" screen should be displayed with "MX BASIC v2.0" on the next line, followed by "Ok" on the next line with a cursor below.
E-1.1.1.5 | AL S2 + MX |  | From the MX BASIC command screen type CALL 32768 (NO minus sign!) and hit RETURN | The cursor should move down one row, and the system should freeze.
E-1.1.1.6 | AL S2 + MX |  | From the AquaLite menu, select File > Hard Reset, and then hit the RETURN/ENTER key to go to MX BASIC. | The "Copyright © 1982 by Microsoft, Inc S2" screen should be displayed with "MX BASIC v2.0" on the next line, followed by "Ok" on the next line with a cursor below.
E-1.1.2 | AL S2 + MX | Test CAT | From the MX BASIC command screen type CAT and hit RETURN | System should display a brief listing of the contents of the USB folder within the AquaLite program folder, followed by Ok beneath. Note that the contents can vary from system to system.
E-1.1.3.1 | AL S2 + MX | Test CD | From the MX BASIC command screen type CD and hit RETURN | The cursor should move down one row, and a / character should be displayed, followed by Ok beneath.
E-1.1.3.2 | AL S2 + MX |  | From the MX BASIC command screen type CD"ROMS" and hit RETURN | The cursor should move down one row and display Ok beneath.
E-1.1.4 | AL S2 + MX | Test DIR | From the MX BASIC command screen type DIR and hit RETURN | System should display a detailed listing of the contents of the USB > ROMS folder within the AquaLite program folder, followed by Ok beneath. Note that the RETURN/ENTER key may have to be pressed one or more times to scroll through the full list of contents.
E-1.1.5.1 | AL S2 + MX | Test CLS | From the MX BASIC command screen type CLS and hit RETURN | System should clear the screen and show Ok in black letters on a cyan background.
E-1.1.5.2 | AL S2 + MX |  | From the MX BASIC command screen type CLS 8 and hit RETURN | System should clear the screen and show Ok in black letters on a grey background.
E-1.1.5.3 | AL S2 + MX |  | From the MX BASIC command screen type CLS $7D and hit RETURN | System should clear the screen and show Ok in white letters on a dark green background.
E-1.1.5.4 | AL S2 + MX |  | From the MX BASIC command screen type CLS and hit RETURN | System should clear the screen and show Ok in black letters on a cyan background.
E-1.1.6.1 | AL S2 + MX | Test SAVE a BASIC file | From the MX BASIC command screen type NEW and hit RETURN | System should display Ok beneath.
E-1.1.6.2 | AL S2 + MX |  | From the MX BASIC command screen type the code below and hit RETURN after each line: 10 REM Testing SAVE 20 CLS 30 PRINT “Hello” | System should show each line typed, and move down to the empty line beneath.
E-1.1.6.3 | AL S2 + MX |  | From the MX BASIC command screen type LIST and hit RETURN | System should show all three lines in the program and display Ok beneath.
E-1.1.6.4 | AL S2 + MX |  | From the MX BASIC command screen type SAVE "TEST01.BAS" and hit RETURN | The cursor should move down one row and display Ok beneath. In the USB > ROMS folder within the AquaLite program folder, there should be a new file named TEST01.BAS.
E-1.1.6.5 | AL S2 + MX |  | From the MX BASIC command screen type CAT and hit RETURN | System should display a brief listing of the contents of the folder, and the "TEST01.BAS" file should be lised among those files. Note that the RETURN/ENTER key may have to be pressed one or more times to scroll through the full list of contents.
E-1.1.7.1 | AL S2 + MX | Test LOAD a BASIC file | From the MX BASIC command screen type NEW and hit RETURN | System should display Ok beneath.
E-1.1.7.2 | AL S2 + MX |  | From the MX BASIC command screen type LIST and hit RETURN | System should display NO PROGRAM LINES with Ok beneath.
E-1.1.7.3 | AL S2 + MX |  | From the MX BASIC command screen type LOAD "TEST01.BAS" and hit RETURN | System should display Ok beneath.
E-1.1.7.4 | AL S2 + MX |  | From the MX BASIC command screen type LIST and hit RETURN | System should show all three lines in the program listed in test E-1.1.6.2 and display Ok beneath.
E-1.1.8.1 | AL S2 + MX | Test RUN a BASIC file | From the MX BASIC command screen type NEW and hit RETURN | System should display Ok beneath.
E-1.1.8.2 | AL S2 + MX |  | From the MX BASIC command screen type RUN "TEST01.BAS" and hit RETURN | System should clear the screen, print Hello at the top, and display Ok beneath.
E-1.1.9.1 | AL S2 + MX | Test DEL | From the MX BASIC command screen type DEL "TEST01.BAS" and hit RETURN | System should display Ok beneath.
E-1.1.9.2 | AL S2 + MX |  | From the MX BASIC command screen type CAT and hit RETURN | System should display a brief listing of the contents of the folder, and the "TEST01.BAS" file SHOULD NOT be lised among those files. Note that the RETURN/ENTER key may have to be pressed one or more times to scroll through the full list of contents.
E-1.1.10.1 | AL S2 + MX | Test SAVE a BIN file | From the MX BASIC command screen type NEW and hit RETURN | System should display Ok beneath.
E-1.1.10.2 | AL S2 + MX |  | From the MX BASIC command screen type the code below and hit RETURN after each line: 10 REM Testing SAVE BIN 20 POKE $8000,97,98,99,100 30 PRINT “Done” | System should show each line typed, and move down to the empty line beneath.
E-1.1.10.3 | AL S2 + MX |  | From the MX BASIC command screen type LIST and hit RETURN | System should show all three lines in the program and display Ok beneath.
E-1.1.10.4 | AL S2 + MX |  | From the MX BASIC command screen type RUN and hit RETURN | System should print Done and display Ok beneath the program listing.
E-1.1.10.5 | AL S2 + MX |  | From the MX BASIC command screen type CD "/" and hit RETURN | System should display Ok beneath.
E-1.1.10.6 | AL S2 + MX |  | From the MX BASIC command screen type the code below and hit RETURN: SAVE "POKE.BIN", $8000, 4 | System should display Ok beneath.
E-1.1.10.7 | AL S2 + MX |  | From the MX BASIC command screen type DIR and hit RETURN | System should display a detailed listing of the contents of the USB folder within the AquaLite program folder, and the file named "POKE.BIN" should be listed in the contents. Note that the RETURN/ENTER key may have to be pressed one or more times to scroll past the full list of contents.
E-1.1.11.1 | AL S2 + MX | Test LOAD a BIN file | From the AquaLite menu, select File > Hard Reset, and then hit the RETURN/ENTER key to go to MX BASIC. | The "Copyright © 1982 by Microsoft, Inc S2" screen should be displayed with "MX BASIC v2.0" on the next line, followed by "Ok" on the next line with a cursor below.
E-1.1.11.2 | AL S2 + MX |  | From the MX BASIC command screen type the code below and hit RETURN: LOAD "POKE.BIN", $3242 | System should display abcd in the middle of the screen, with Ok beneath the text you just typed.
E-1.1.12.1 | AL S2 + MX | Test RUN a ROM file | From the AquaLite menu, select File > Hard Reset, and then hit the RETURN/ENTER key to go to MX BASIC. | The "Copyright © 1982 by Microsoft, Inc S2" screen should be displayed with "MX BASIC v2.0" on the next line, followed by "Ok" on the next line with a cursor below.
E-1.1.12.2 | AL S2 + MX |  | From the MX BASIC command screen type CD"ROMS" and hit RETURN | The cursor should move down one row and display Ok beneath.
E-1.1.12.3 | AL S2 + MX |  | From the MX BASIC command screen type the code below and hit RETURN: RUN "SNAFU.ROM" | System should load the SNAFU game ROM and display the SNAFU title screen.
E-1.1.12.4 | AL S2 + MX |  | From the AquaLite menu, select File > Hard Reset, and then hit the RETURN/ENTER key to go to MX BASIC. | The "Copyright © 1982 by Microsoft, Inc S2" screen should be displayed with "MX BASIC v2.0" on the next line, followed by "Ok" on the next line with a cursor below.
E-1.1.13.1 | AL S2 + MX | Test DEBUG | From the MX BASIC command screen type DEBUG and hit RETURN | The AQUBUG screen should pop up with white text on a blue background.
E-1.1.13.2 | AL S2 + MX |  | On the AQUBUG screen type the letter Q | System should return to the MX BASIC command screen, showing the DEBUG command with Ok beneath.
E-1.1.14.1 | AL S2 + MX | Test HEX$ | From the MX BASIC command screen type the code below and hit RETURN: PRINT HEX$(12288) | System should display 3000 on the next line with Ok beneath.
E-1.1.14.2 | AL S2 + MX |  | From the MX BASIC command screen type the code below and hit RETURN: PRINT HEX$(-123) | System should display FF85 on the next line with Ok beneath.
E-1.1.14.3 | AL S2 + MX |  | From the MX BASIC command screen type the code below and hit RETURN: PRINT HEX$(65535) | System should display FFFF on the next line with Ok beneath.
E-1.1.15 | AL S2 + MX | Test JOY | From the MX BASIC command screen type the code below and try to type RETURN and the 1 key at about the same time (maybe a slight delay before the 1 key): PRINT JOY(0) | System should display 64 on the next line with Ok beneath. If you weren't able to get it to work exactly right, a 0 might be displayed instead of the 64. Try a couple of times to get it to work, if you can.
E-1.1.16 | AL S2 + MX | Test IN | From the MX BASIC command screen type the code below and hit RETURN: PRINT IN($FF) | System should display 247 on the next line with Ok beneath.
E-1.1.17.1 | AL S2 + MX | Test PSG | From the MX BASIC command screen type the code below and hit RETURN: PSG 8,15,0,148,1,1,7,56 | System should play a Db4 tone continuously.
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

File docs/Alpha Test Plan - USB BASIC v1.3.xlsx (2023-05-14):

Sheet: AL-S2-MX
Alpha Test Plan |  | Tester Name:
USB BASIC v1.3 |  | Date Completed:
E1 |  | Environment(s) Tested: | AquaLite S2 + Micro Expander Option
Setup
Test No | Environment | Description | Process | Expected Results | Actual Results ("As Expected" ok) | Pass/Fail | Initials | Date/Time
E-1.0.0 | AL S2 + MX | Setup AquaLite v1.36
E-1.0.1 | AL S2 + MX |  | Download & install AquaLite v1.36 from https://aquarius.je/aqualite (unzip files) | AquaLite v1.36 is downloaded and installed on your system.
E-1.0.2 | AL S2 + MX |  | Launch AquaLite v1.36. (aqualite.exe) | System should boot into "BASIC Press RETURN key to start" flashing screen. Menubar should say AquaLite v1.36.
E-1.0.3 | AL S2 + MX |  | Within AquaLite v1.36, go to menu option Tool > Options, select the Peripherals tab, and make sure Micro Expander is checked. Click Ok. | System should beep and reboot.
E-1.0.4 | AL S2 + MX |  | Press the A key within the emulator. | The "About USB BASIC" screen should be displayed. Release Date should show "Alpha 2023-05-09".
E-1.0.5 | AL S2 + MX |  | Press any key to exit the About screen. | The "Aquarius MX USB BASIC v1.3" screen should be displayed.
E-1.0.6 | AL S2 + MX |  | Press RETURN/ENTER key to go to the USB BASIC command screen. Note: This screen is the starting point for most tests in this plan. | The "Copyright © 1982 by Microsoft, Inc S2" screen should be displayed with "USB BASIC v1.3" on the next line, followed by "Ok" on the next line with a cursor below.
DO NOT CONTINUE IF ANY TESTS IN THIS SECTION DID NOT PASS! CONTACT THE TESTING COORDINATOR, Sean Harrington sph@1stage.com.
Legacy Commands
Test No | Environment | Description | Process | Expected Results | Actual Results ("As Expected" ok) | Pass/Fail | Initials | Date/Time
E-1.1.0 | AL S2 + MX | Test legacy commands
E-1.1.1.1 | AL S2 + MX | Test CALL xx | From the USB BASIC command screen type CALL $8000 and hit RETURN | The cursor should move down one row, and the system should freeze.
E-1.1.1.2 | AL S2 + MX |  | From the AquaLite menu, select File > Hard Reset, and then hit the RETURN/ENTER key to go to USB BASIC. | The "Copyright © 1982 by Microsoft, Inc S2" screen should be displayed with "USB BASIC v1.3" on the next line, followed by "Ok" on the next line with a cursor below.
E-1.1.1.3 | AL S2 + MX |  | From the USB BASIC command screen type CALL -32768 and hit RETURN | The cursor should move down one row, and the system should freeze.
E-1.1.1.4 | AL S2 + MX |  | From the AquaLite menu, select File > Hard Reset, and then hit the RETURN/ENTER key to go to USB BASIC. | The "Copyright © 1982 by Microsoft, Inc S2" screen should be displayed with "USB BASIC v1.3" on the next line, followed by "Ok" on the next line with a cursor below.
E-1.1.1.5 | AL S2 + MX |  | From the USB BASIC command screen type CALL 32768 (NO minus sign!) and hit RETURN | The cursor should move down one row, and the system should freeze.
E-1.1.1.6 | AL S2 + MX |  | From the AquaLite menu, select File > Hard Reset, and then hit the RETURN/ENTER key to go to USB BASIC. | The "Copyright © 1982 by Microsoft, Inc S2" screen should be displayed with "USB BASIC v1.3" on the next line, followed by "Ok" on the next line with a cursor below.
E-1.1.2 | AL S2 + MX | Test CAT | From the USB BASIC command screen type CAT and hit RETURN | System should display a brief listing of the contents of the USB folder within the AquaLite program folder, followed by Ok beneath. Note that the contents can vary from system to system.
E-1.1.3.1 | AL S2 + MX | Test CD | From the USB BASIC command screen type CD and hit RETURN | The cursor should move down one row, and a / character should be displayed, followed by Ok beneath.
E-1.1.3.2 | AL S2 + MX |  | From the USB BASIC command screen type CD"ROMS" and hit RETURN | The cursor should move down one row and display Ok beneath.
E-1.1.4 | AL S2 + MX | Test DIR | From the USB BASIC command screen type DIR and hit RETURN | System should display a detailed listing of the contents of the USB > ROMS folder within the AquaLite program folder, followed by Ok beneath. Note that the RETURN/ENTER key may have to be pressed one or more times to scroll through the full list of contents.
E-1.1.5.1 | AL S2 + MX | Test CLS | From the USB BASIC command screen type CLS and hit RETURN | System should clear the screen and show Ok in black letters on a cyan background.
E-1.1.5.2 | AL S2 + MX |  | From the USB BASIC command screen type CLS 8 and hit RETURN | System should clear the screen and show Ok in black letters on a grey background.
E-1.1.5.3 | AL S2 + MX |  | From the USB BASIC command screen type CLS $7D and hit RETURN | System should clear the screen and show Ok in white letters on a dark green background.
E-1.1.5.4 | AL S2 + MX |  | From the USB BASIC command screen type CLS and hit RETURN | System should clear the screen and show Ok in black letters on a cyan background.
E-1.1.6.1 | AL S2 + MX | Test SAVE a BASIC file | From the USB BASIC command screen type NEW and hit RETURN | System should display Ok beneath.
E-1.1.6.2 | AL S2 + MX |  | From the USB BASIC command screen type the code below and hit RETURN after each line: 10 REM Testing SAVE 20 CLS 30 PRINT “Hello” | System should show each line typed, and move down to the empty line beneath.
E-1.1.6.3 | AL S2 + MX |  | From the USB BASIC command screen type LIST and hit RETURN | System should show all three lines in the program and display Ok beneath.
E-1.1.6.4 | AL S2 + MX |  | From the USB BASIC command screen type SAVE "TEST01.BAS" and hit RETURN | The cursor should move down one row and display Ok beneath. In the USB > ROMS folder within the AquaLite program folder, there should be a new file named TEST01.BAS.
E-1.1.6.5 | AL S2 + MX |  | From the USB BASIC command screen type CAT and hit RETURN | System should display a brief listing of the contents of the folder, and the "TEST01.BAS" file should be lised among those files. Note that the RETURN/ENTER key may have to be pressed one or more times to scroll through the full list of contents.
E-1.1.7.1 | AL S2 + MX | Test LOAD a BASIC file | From the USB BASIC command screen type NEW and hit RETURN | System should display Ok beneath.
E-1.1.7.2 | AL S2 + MX |  | From the USB BASIC command screen type LIST and hit RETURN | System should display NO PROGRAM LINES with Ok beneath.
E-1.1.7.3 | AL S2 + MX |  | From the USB BASIC command screen type LOAD "TEST01.BAS" and hit RETURN | System should display Ok beneath.
E-1.1.7.4 | AL S2 + MX |  | From the USB BASIC command screen type LIST and hit RETURN | System should show all three lines in the program listed in test E-1.1.6.2 and display Ok beneath.
E-1.1.8.1 | AL S2 + MX | Test RUN a BASIC file | From the USB BASIC command screen type NEW and hit RETURN | System should display Ok beneath.
E-1.1.8.2 | AL S2 + MX |  | From the USB BASIC command screen type RUN "TEST01.BAS" and hit RETURN | System should clear the screen, print Hello at the top, and display Ok beneath.
E-1.1.9.1 | AL S2 + MX | Test DEL | From the USB BASIC command screen type DEL "TEST01.BAS" and hit RETURN | System should display Ok beneath.
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

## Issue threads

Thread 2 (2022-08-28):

USB port does not align perfectly with the rear of top case

1stage, 2022-08-28:
There is often as much as a 1mm difference between the center of the USB port and the hole in the case.

1stage, 2022-08-28:
Due to manufacturing discrepancies across CH376S product line (and we use that term loosely), the mounting holes on these items differ as much as 1mm, hence the offset. Builders are recommended to slightly drill out the mounting holes on the CH376S module (not the MX PCB) closest to the USB port. This can allow a bit more flexibility in positioning the USB port to align with the case, and the mounting hardware can keep this fixed better in place.

Closed 2022-08-28.

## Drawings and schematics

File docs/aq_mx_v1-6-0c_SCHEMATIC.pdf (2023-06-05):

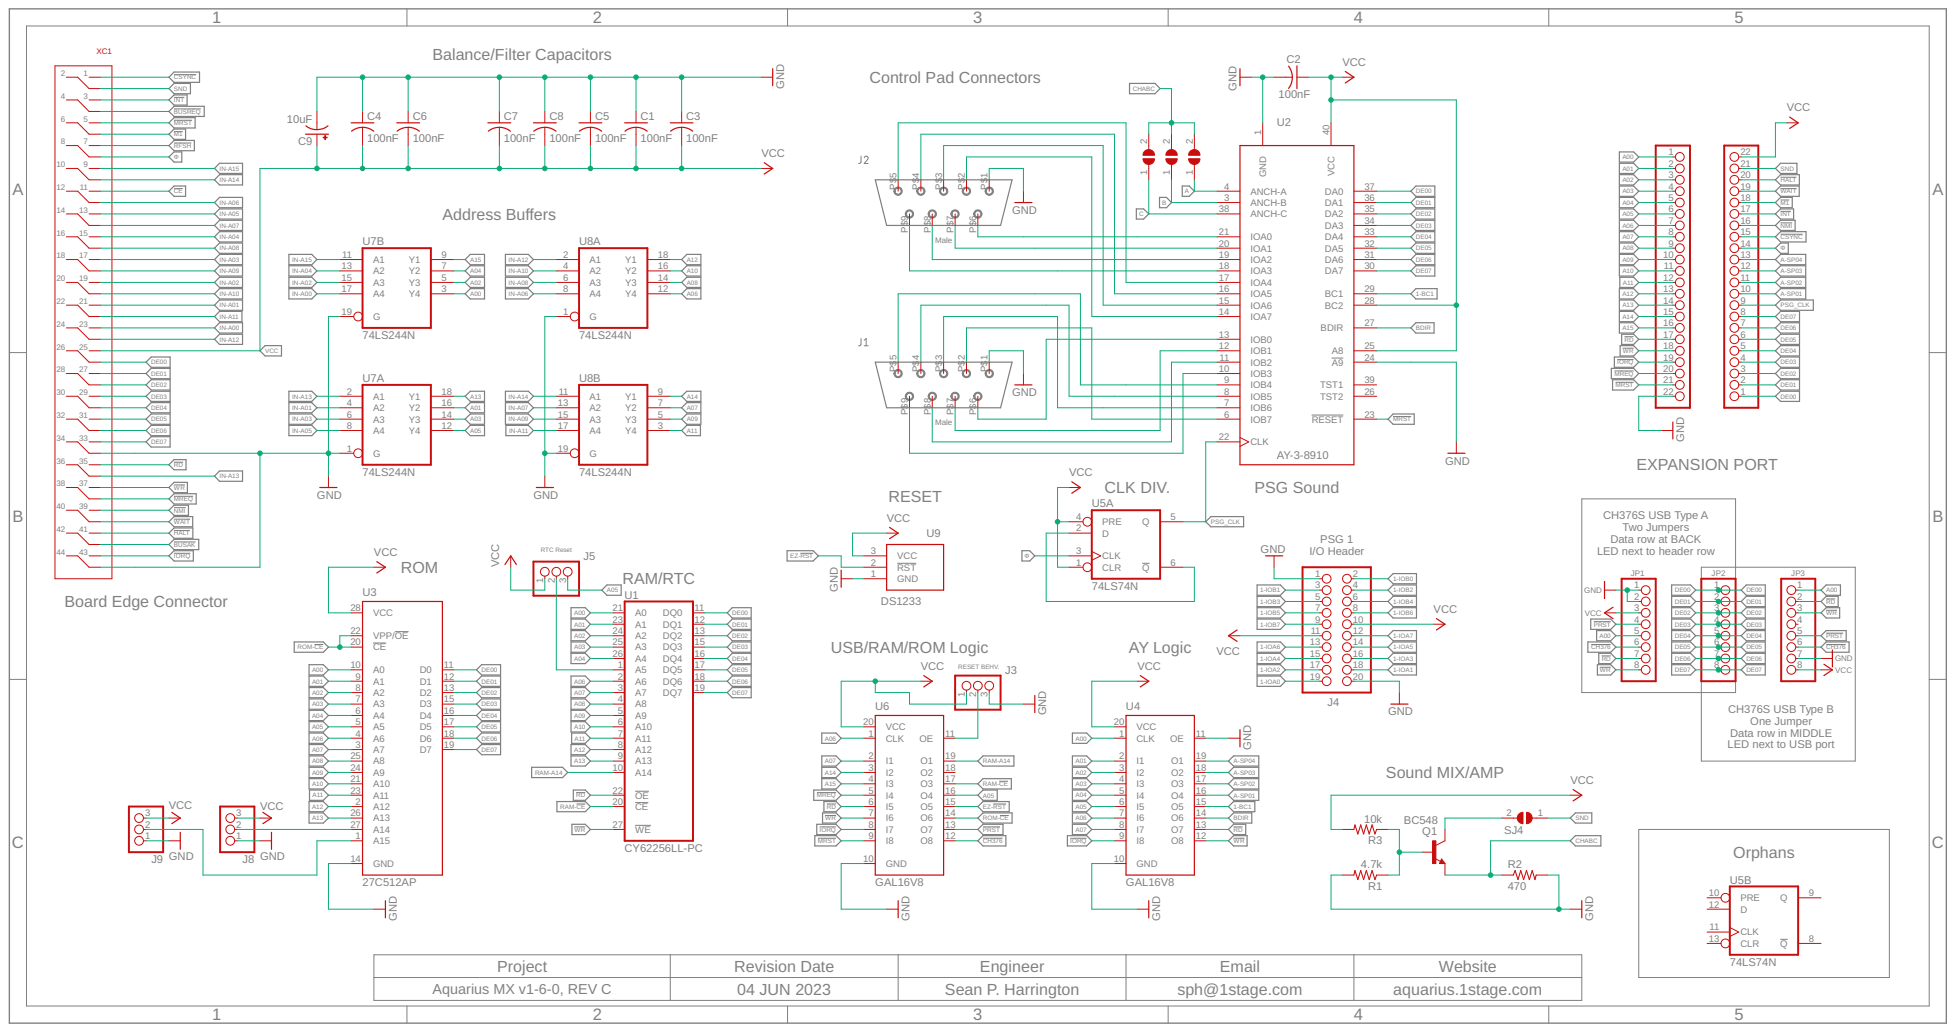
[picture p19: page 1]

LED next to header row EXPANSION PORT

CH376S USB Type A
Two Jumpers Data row at BACK

CH376S USB Type B One Jumper Data row in MIDDLE

LED next to USB port

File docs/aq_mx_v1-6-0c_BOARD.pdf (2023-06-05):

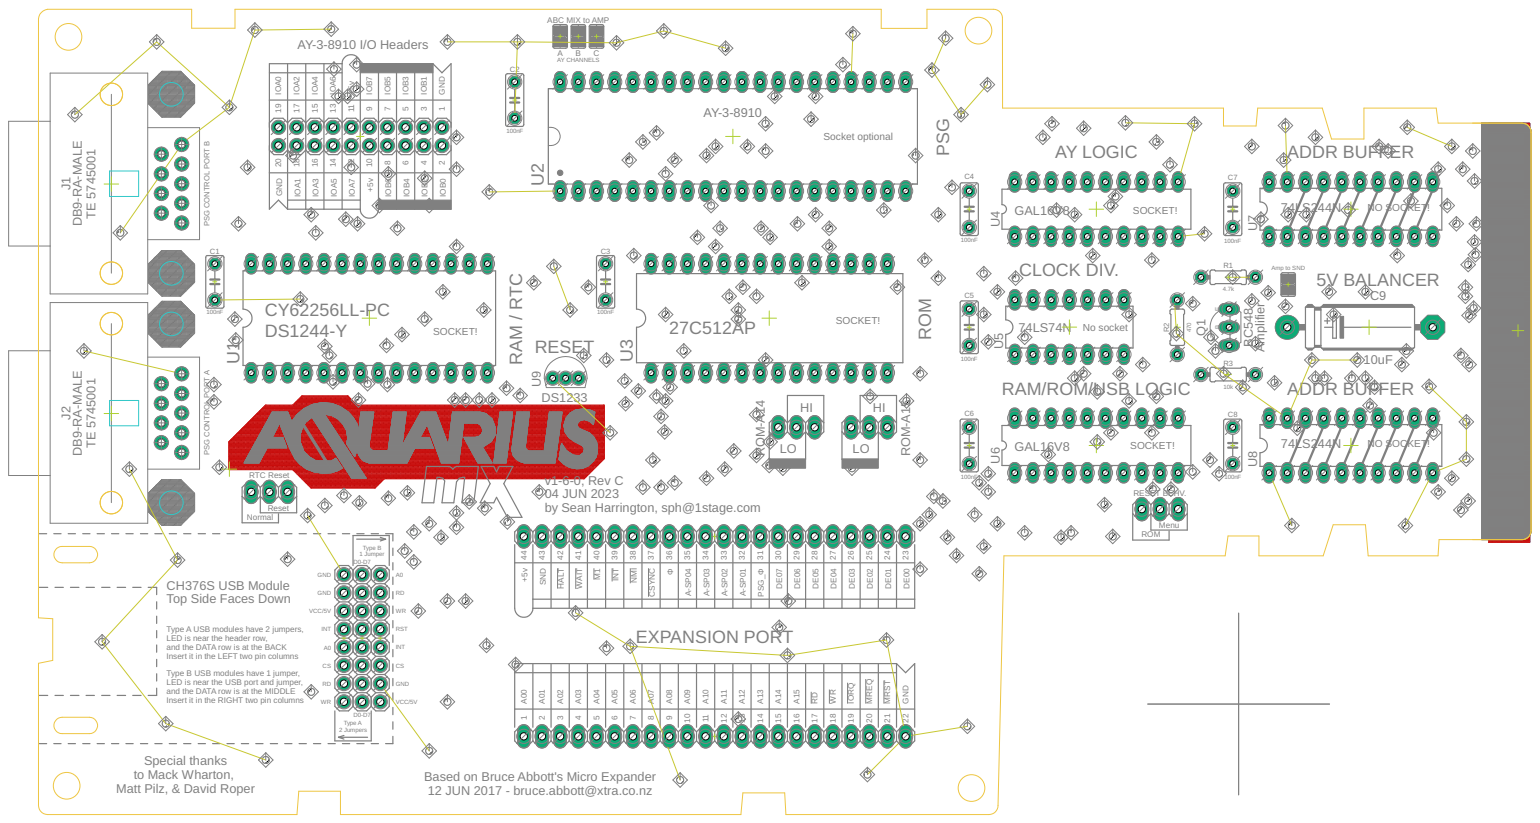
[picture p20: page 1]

ABC MIX to AMP

PSG CONTROL PORT B PSG CONTROL PORT A

RAM/ROM/USB LOGIC

ROM-A14HI HI LO LO

RESET BEHV. RTC Reset

v1-6-0, Rev C
04 JUN 2023
by Sean Harrington, sph@1stage.com

CH376S USB Module Top Side Faces Down

Type A USB modules have 2 jumpers, LED is near the header row, and the DATA row is at the BACK

Insert it in the LEFT two pin columns Type B USB modules have 1 jumper, LED is near the USB port and jumper, and the DATA row is at the MIDDLE

IORQ 19 MREQ 20 MRST 21 GND 22

Insert it in the RIGHT two pin columns

Special thanks
to Mack Wharton, Matt Pilz, & David Roper

Based on Bruce Abbott's Micro Expander 12 JUN 2017 - bruce.abbott@xtra.co.nz

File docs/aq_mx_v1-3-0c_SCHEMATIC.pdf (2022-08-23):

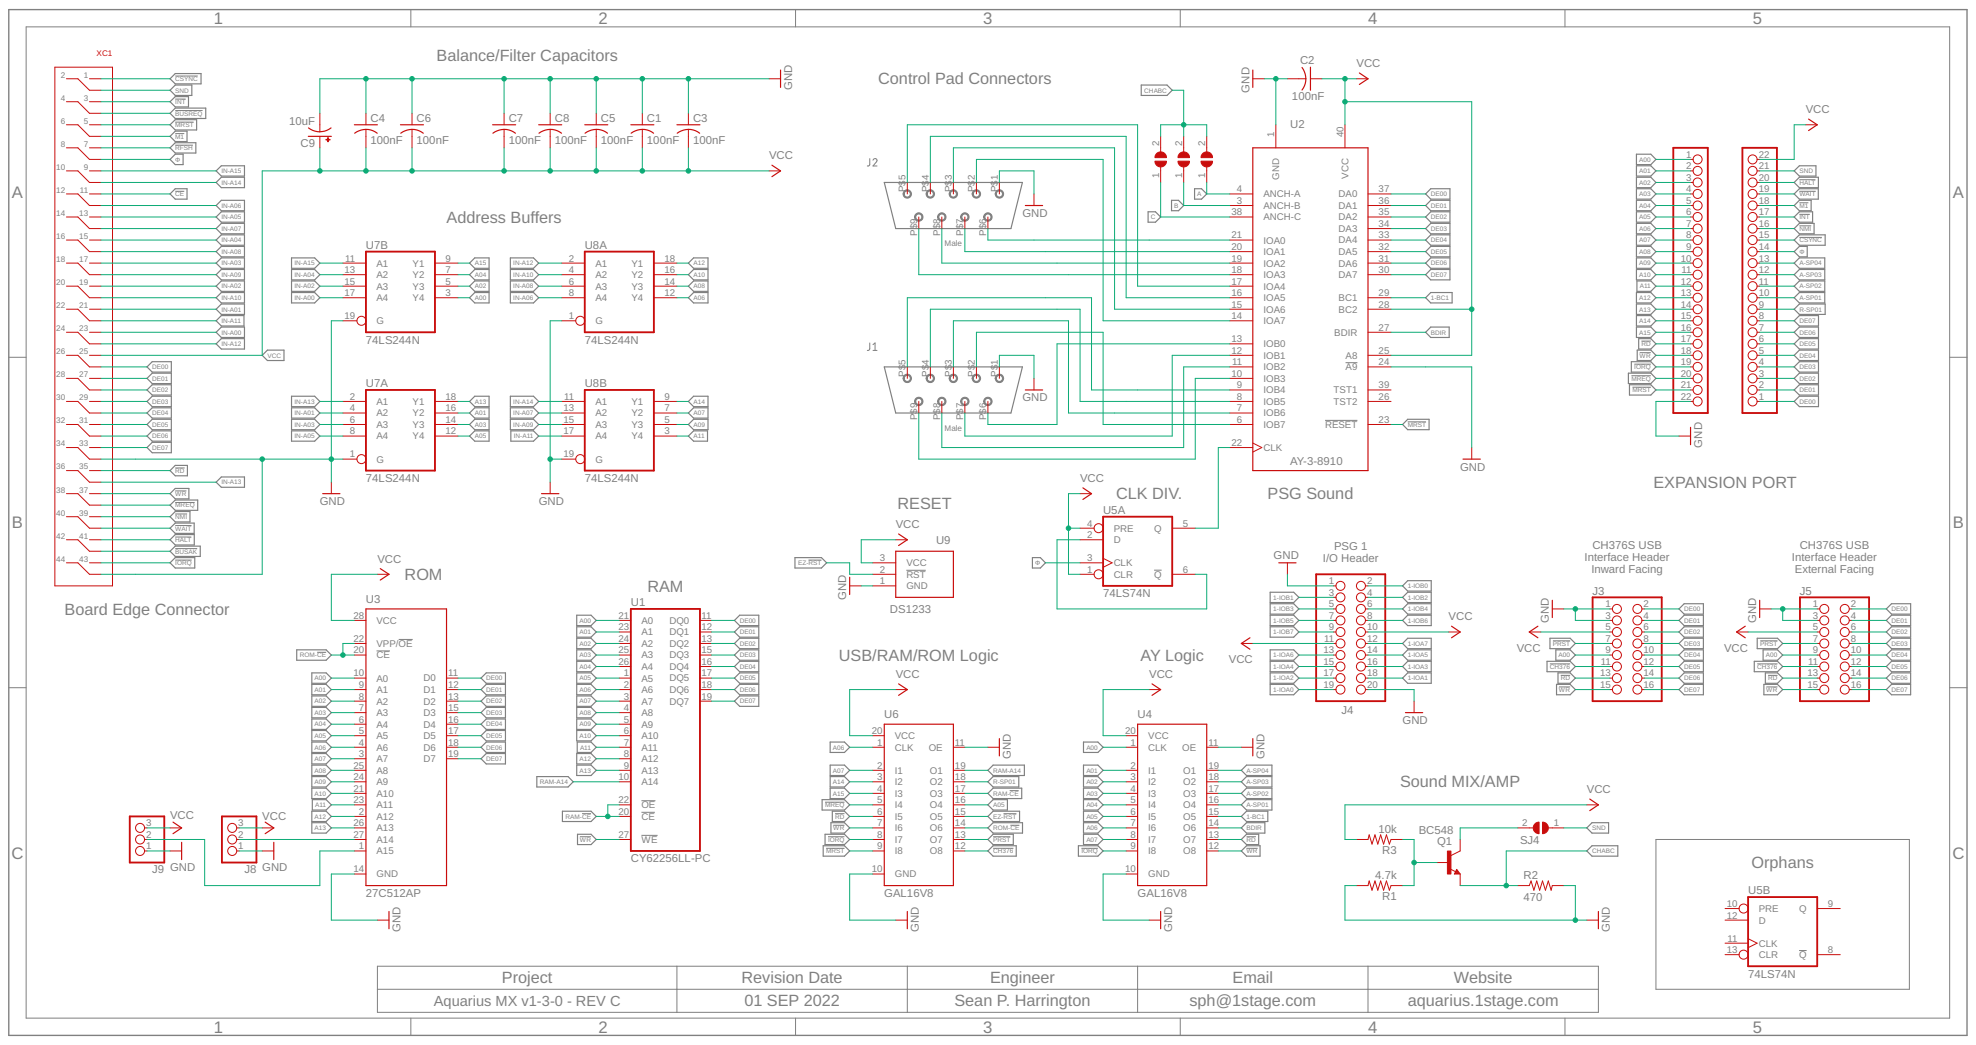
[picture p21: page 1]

CH376S USB
Interface Header External Facing

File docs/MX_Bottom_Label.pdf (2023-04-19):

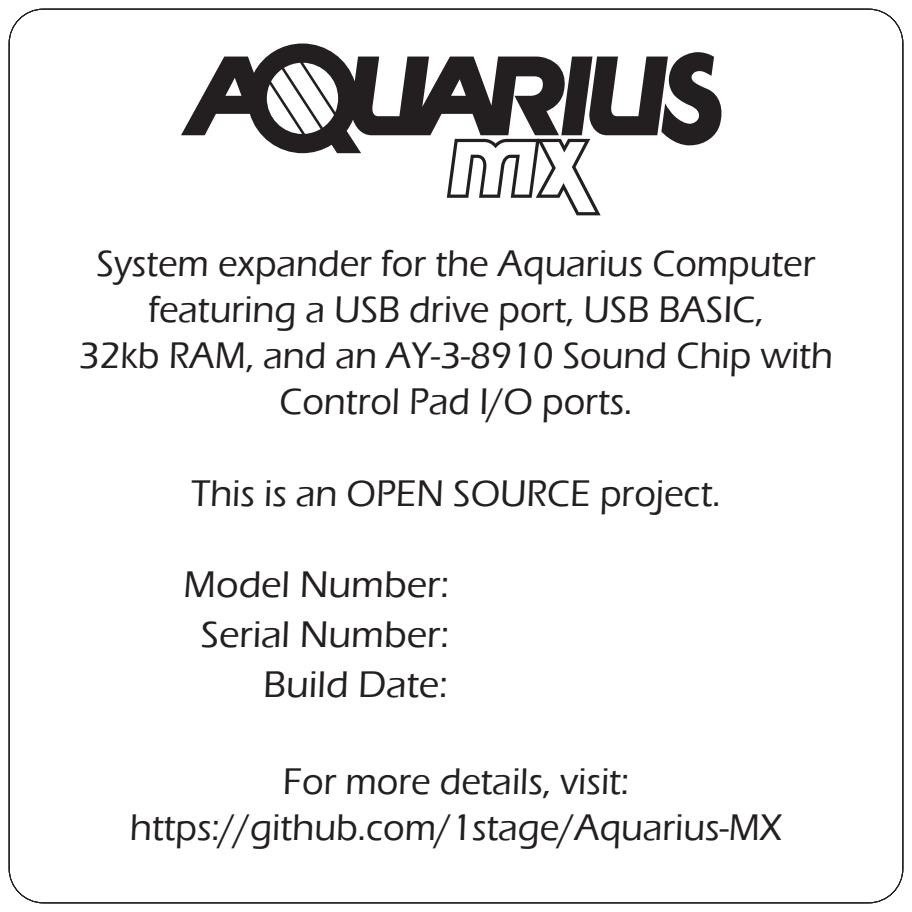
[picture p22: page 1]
Model Number: Serial Number: Build Date:

System expander for the Aquarius Computer
featuring a USB drive port, USB BASIC,
32kb RAM, and an AY-3-8910 Sound Chip with

Control Pad I/O ports.

This is an OPEN SOURCE project.

For more details, visit:

https://github.com/1stage/Aquarius-MX

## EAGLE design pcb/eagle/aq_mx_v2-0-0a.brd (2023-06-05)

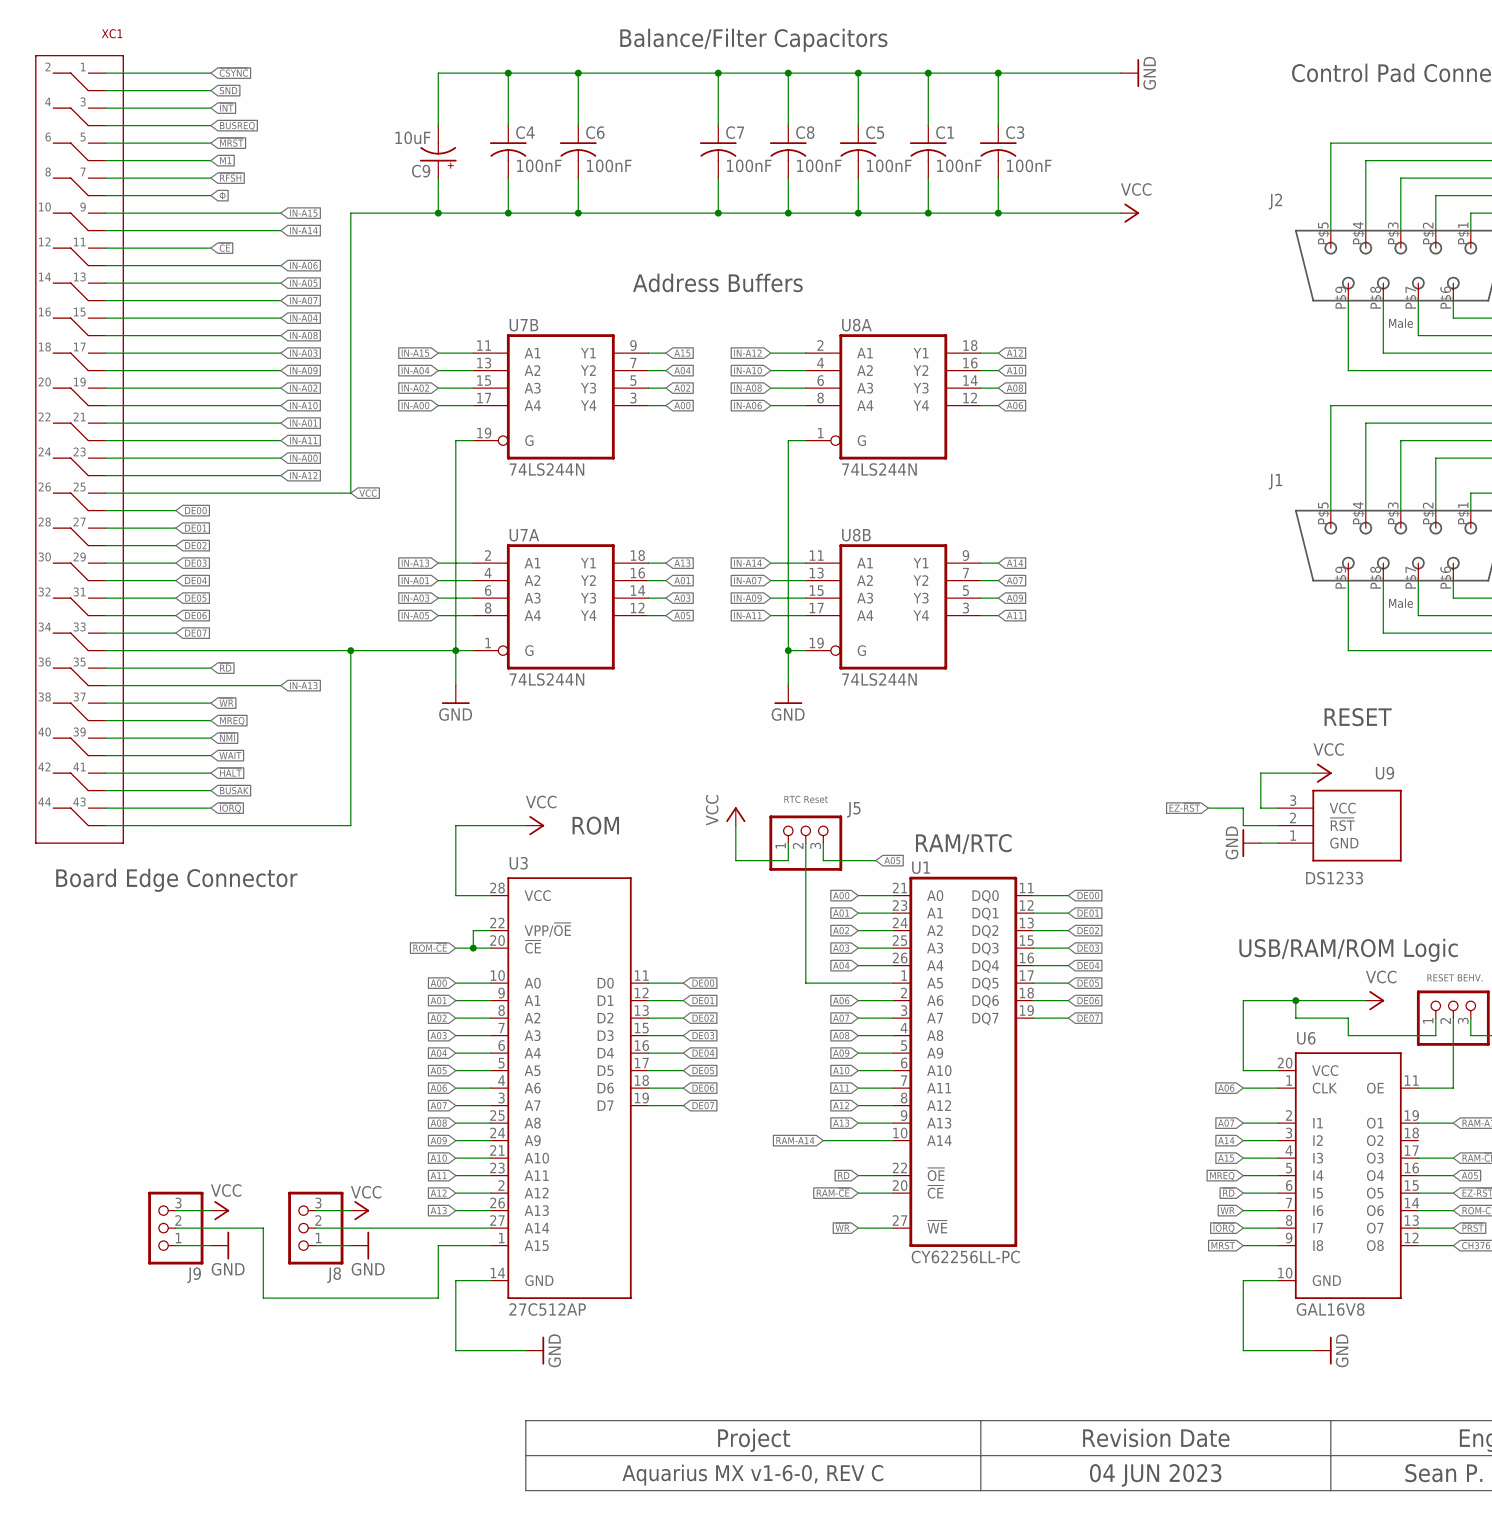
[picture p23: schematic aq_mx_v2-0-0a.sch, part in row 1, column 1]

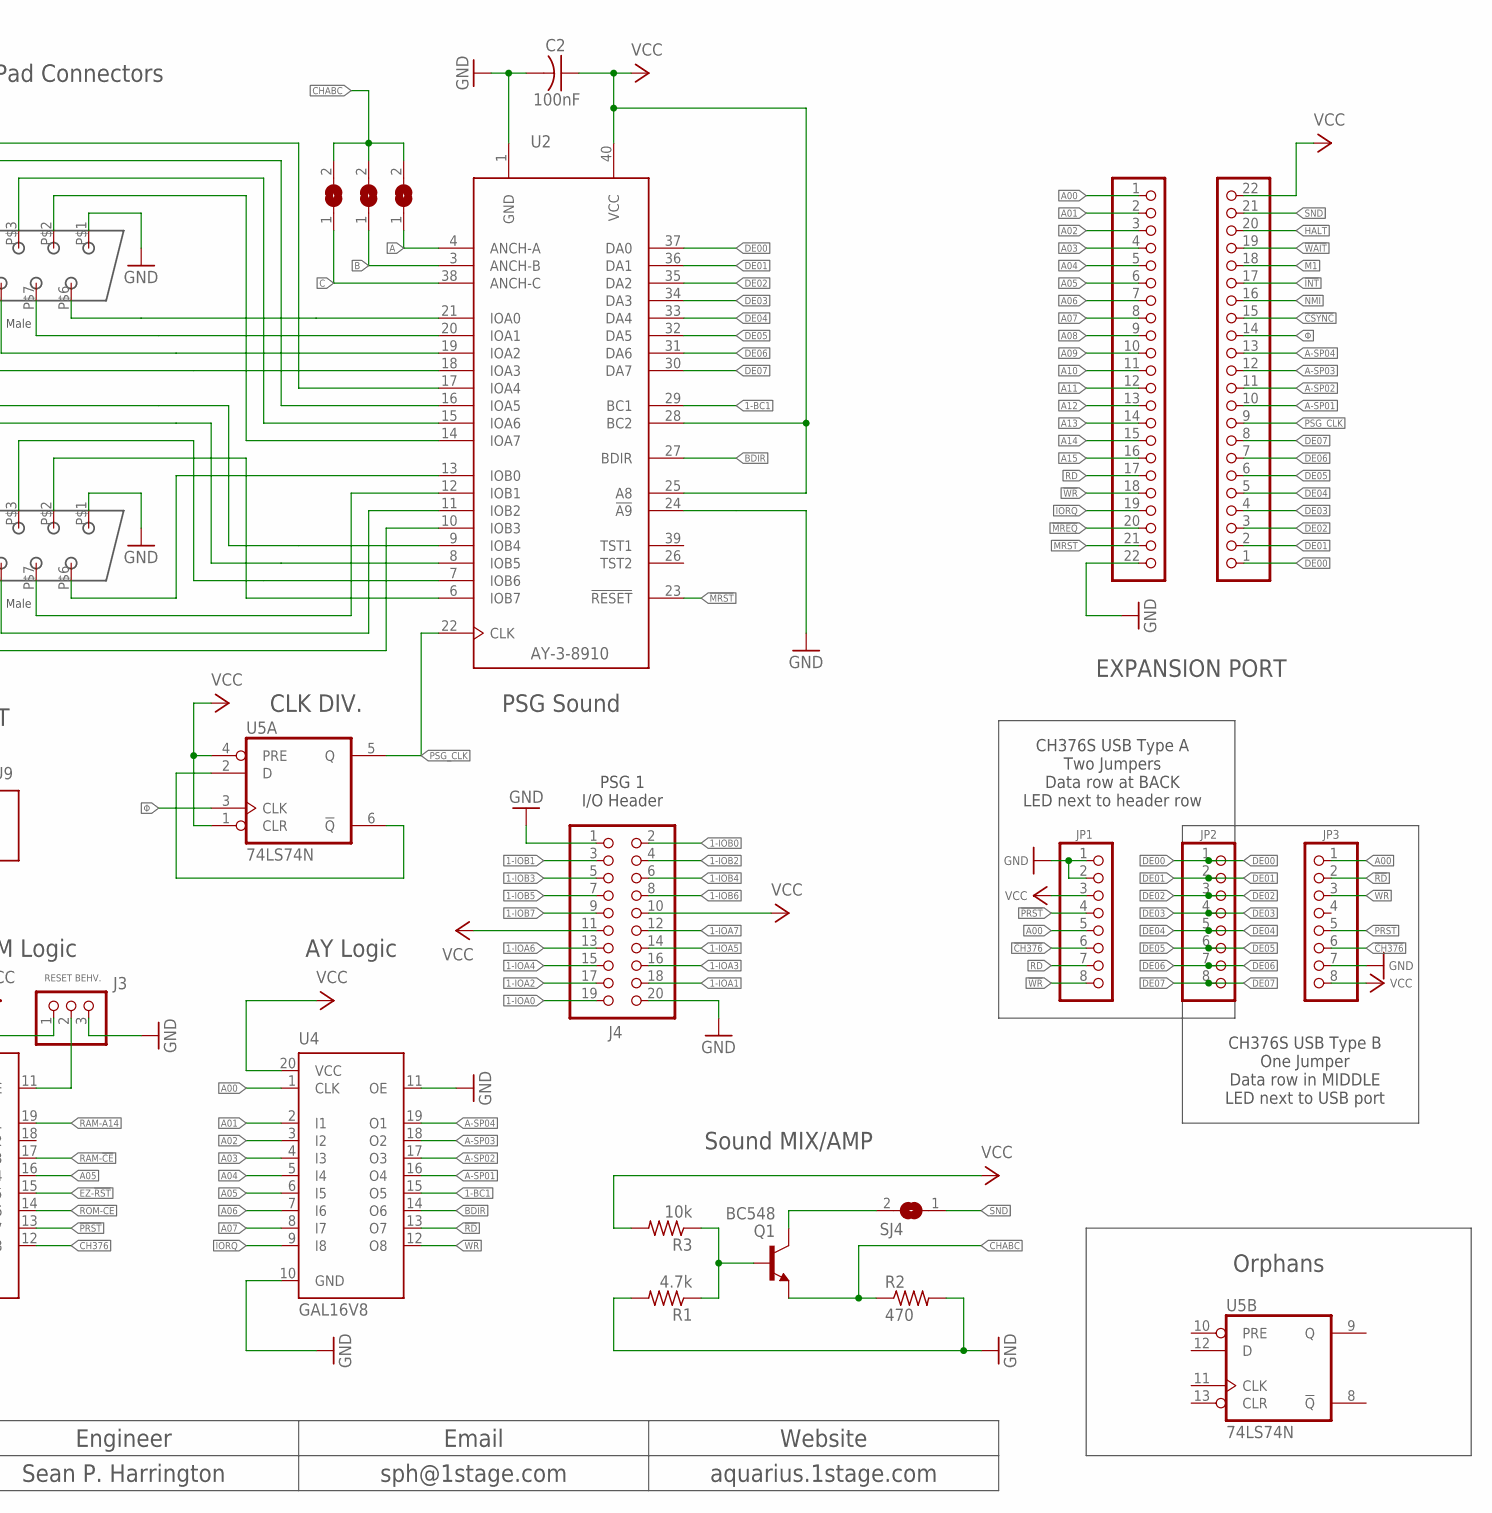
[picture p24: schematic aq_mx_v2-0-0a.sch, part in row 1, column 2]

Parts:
C1, C2, C3, C4, C5, C6, C7, C8: 100nF; C050-025X075
C9: 10uF; E22-6
J1, J2: DB9-MALE-RA
J3: RESET BEHV.; 1X03
J4: PINHD-2X10; 2X10
J5: RTC Reset; 1X03
J6, J7: PINHD-1X22; 1X22
J8, J9: PINHD-1X3; 1X03
JP1, JP2, JP3: PINHD-1X8; 1X08
Q1: BC548; TO92-CBE
R1: 4.7k; 0204/7
R2: 470; 0204/7
R3: 10k; 0204/7
SJ1, SJ2, SJ3, SJ4: SJ
U1: CY62256LL-PC; DIL28-6
U2: AY-3-8910; RAD38910-DIL40-6
U3: 27C512AP; DIL28-6
U4, U6: GAL16V8; DIL20
U5: 74LS74N; DIL14
U7, U8: 74LS244N; DIL20
U9: DS1233; TO-92
XC1: AQ-CART-EDGE

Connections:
1-BC1: U2.29 (BC1), U4.15 (O5)
1-IOA0: J2.P$6, J4.19, U2.21 (IOA0)
1-IOA1: J2.P$7, J4.18, U2.20 (IOA1)
1-IOA2: J2.P$8, J4.17, U2.19 (IOA2)
1-IOA3: J2.P$9, J4.16, U2.18 (IOA3)
1-IOA4: J2.P$5, J4.15, U2.17 (IOA4)
1-IOA5: J2.P$4, J4.14, U2.16 (IOA5)
1-IOA6: J2.P$3, J4.13, U2.15 (IOA6)
1-IOA7: J2.P$2, J4.12, U2.14 (IOA7)
1-IOB0: J1.P$6, J4.2, U2.13 (IOB0)
1-IOB1: J1.P$7, J4.3, U2.12 (IOB1)
1-IOB2: J1.P$8, J4.4, U2.11 (IOB2)
1-IOB3: J1.P$9, J4.5, U2.10 (IOB3)
1-IOB4: J1.P$5, J4.6, U2.9 (IOB4)
1-IOB5: J1.P$4, J4.7, U2.8 (IOB5)
1-IOB6: J1.P$3, J4.8, U2.7 (IOB6)
1-IOB7: J1.P$2, J4.9, U2.6 (IOB7)
!BUSAK: XC1.P$42 (X42)
!BUSREQ: XC1.P$4 (X4)
!CE: XC1.P$11 (X11)
!CH376: JP1.6, JP3.6, U6.12 (O8)
!CSYNC: J6.15, XC1.P$1 (X1)
!HALT: J6.20, XC1.P$41 (X41)
!INT: J6.17, XC1.P$3 (X3)
!IORQ: J7.19, U4.9 (I8), U6.8 (I7), XC1.P$43 (X43)
!M1: J6.18, XC1.P$6 (X6)
!MREQ: J7.20, U6.5 (I4), XC1.P$38 (X38)
!MRST: J7.21, U2.23 (!RESET), U6.9 (I8), XC1.P$5 (X5)
!NMI: J6.16, XC1.P$39 (X39)
!PRST: JP1.4, JP3.5, U6.13 (O7)
!RD: J7.17, JP1.7, JP3.2, U1.22 (!OE), U4.13 (O7), U6.6 (I5), XC1.P$35 (X35)
!RFSH: XC1.P$7 (X7)
!WAIT: J6.19, XC1.P$40 (X40)
!WR: J7.18, JP1.8, JP3.3, U1.27 (!WE), U4.12 (O8), U6.7 (I6), XC1.P$37 (X37)
A: SJ1.1, U2.4 (ANCH-A)
A00: J7.1, JP1.5, JP3.1, U1.21 (A0), U3.10 (A0), U4.1 (CLK), U7.3 (Y4)
A01: J7.2, U1.23 (A1), U3.9 (A1), U4.2 (I1), U7.16 (Y2)
A02: J7.3, U1.24 (A2), U3.8 (A2), U4.3 (I2), U7.5 (Y3)
A03: J7.4, U1.25 (A3), U3.7 (A3), U4.4 (I3), U7.14 (Y3)
A04: J7.5, U1.26 (A4), U3.6 (A4), U4.5 (I4), U7.7 (Y2)
A05: J5.3, J7.6, U3.5 (A5), U4.6 (I5), U6.16 (O4), U7.12 (Y4)
A06: J7.7, U1.2 (A6), U3.4 (A6), U4.7 (I6), U6.1 (CLK), U8.12 (Y4)
A07: J7.8, U1.3 (A7), U3.3 (A7), U4.8 (I7), U6.2 (I1), U8.7 (Y2)
A08: J7.9, U1.4 (A8), U3.25 (A8), U8.14 (Y3)
A09: J7.10, U1.5 (A9), U3.24 (A9), U8.5 (Y3)
A10: J7.11, U1.6 (A10), U3.21 (A10), U8.16 (Y2)
A11: J7.12, U1.7 (A11), U3.23 (A11), U8.3 (Y4)
A12: J7.13, U1.8 (A12), U3.2 (A12), U8.18 (Y1)
A13: J7.14, U1.9 (A13), U3.26 (A13), U7.18 (Y1)
A14: J7.15, U6.3 (I2), U8.9 (Y1)
A15: J7.16, U6.4 (I3), U7.9 (Y1)
A-SP01: J6.10, U4.16 (O4)
A-SP02: J6.11, U4.17 (O3)
A-SP03: J6.12, U4.18 (O2)
A-SP04: J6.13, U4.19 (O1)
B: SJ2.1, U2.3 (ANCH-B)
BDIR: U2.27 (BDIR), U4.14 (O6)
C: SJ3.1, U2.38 (ANCH-C)
CHABC: Q1.E, R2.1, SJ1.2, SJ2.2, SJ3.2
DE00: J6.1, JP2.1, U1.11 (DQ0), U2.37 (DA0), U3.11 (D0), XC1.P$26 (X26)
DE01: J6.2, JP2.2, U1.12 (DQ1), U2.36 (DA1), U3.12 (D1), XC1.P$27 (X27)
DE02: J6.3, JP2.3, U1.13 (DQ2), U2.35 (DA2), U3.13 (D2), XC1.P$28 (X28)
DE03: J6.4, JP2.4, U1.15 (DQ3), U2.34 (DA3), U3.15 (D3), XC1.P$29 (X29)
DE04: J6.5, JP2.5, U1.16 (DQ4), U2.33 (DA4), U3.16 (D4), XC1.P$30 (X30)
DE05: J6.6, JP2.6, U1.17 (DQ5), U2.32 (DA5), U3.17 (D5), XC1.P$31 (X31)
DE06: J6.7, JP2.7, U1.18 (DQ6), U2.31 (DA6), U3.18 (D6), XC1.P$32 (X32)
DE07: J6.8, JP2.8, U1.19 (DQ7), U2.30 (DA7), U3.19 (D7), XC1.P$33 (X33)
EZ-!RST: U6.15 (O5), U9.2 (!RST)
GND: C1.1, C2.2, C3.1, C4.1, C5.1, C6.1, C7.1, C8.1, C9.-, J1.P$1, J2.P$1, J3.3, J4.1, J4.20, J7.22, J8.1, J9.1, JP1.1, JP1.2, JP3.7, R1.2, R2.2, U1.14 (GND), U2.1 (GND), U2.24 (!A9), U3.14 (GND), U4.10 (GND), U4.11 (OE), U5.7 (GND), U6.10 (GND), U7.1 (G), U7.10 (GND), U7.19 (G), U8.1 (G), U8.10 (GND), U8.19 (G), U9.1 (GND), XC1.P$34 (X34), XC1.P$44 (X44)
IN-A00: U7.17 (A4), XC1.P$23 (X23)
IN-A01: U7.4 (A2), XC1.P$21 (X21)
IN-A02: U7.15 (A3), XC1.P$19 (X19)
IN-A03: U7.6 (A3), XC1.P$17 (X17)
IN-A04: U7.13 (A2), XC1.P$15 (X15)
IN-A05: U7.8 (A4), XC1.P$13 (X13)
IN-A06: U8.8 (A4), XC1.P$12 (X12)
IN-A07: U8.13 (A2), XC1.P$14 (X14)
IN-A08: U8.6 (A3), XC1.P$16 (X16)
IN-A09: U8.15 (A3), XC1.P$18 (X18)
IN-A10: U8.4 (A2), XC1.P$20 (X20)
IN-A11: U8.17 (A4), XC1.P$22 (X22)
IN-A12: U8.2 (A1), XC1.P$24 (X24)
IN-A13: U7.2 (A1), XC1.P$36 (X36)
IN-A14: U8.11 (A1), XC1.P$10 (X10)
IN-A15: U7.11 (A1), XC1.P$9 (X9)
unnamed: J3.2, U6.11 (OE)
unnamed: J5.2, U1.1 (A5)
unnamed: Q1.B, R1.1, R3.1
unnamed: Q1.C, SJ4.2
unnamed: U5.2 (D), U5.6 (!Q)
PSG_CLK: J6.9, U2.22 (CLK), U5.5 (Q)
RAM-!CE: U1.20 (!CE), U6.17 (O3)
RAM-A14: U1.10 (A14), U6.19 (O1)
ROM-!CE: U3.20 (!CE), U3.22 (VPP/!OE), U6.14 (O6)
ROM-A14: J8.2, U3.27 (A14)
ROM-A15: J9.2, U3.1 (A15)
SND: J6.21, SJ4.1, XC1.P$2 (X2)
VCC: C1.2, C2.1, C3.2, C4.2, C5.2, C6.2, C7.2, C8.2, C9.+, J3.1, J4.10, J4.11, J5.1, J6.22, J8.3, J9.3, JP1.3, JP3.8, R3.2, U1.28 (VCC), U2.25 (A8), U2.28 (BC2), U2.40 (VCC), U3.28 (VCC), U4.20 (VCC), U5.1 (CLR), U5.4 (PRE), U5.14 (VCC), U6.20 (VCC), U7.20 (VCC), U8.20 (VCC), U9.3 (VCC), XC1.P$25 (X25)
Φ: J6.14, U5.3 (CLK), XC1.P$8 (X8)

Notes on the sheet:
Orphans
Board Edge Connector
Control Pad Connectors
PSG Sound
Sound MIX/AMP
Address Buffers
Balance/Filter Capacitors
Aquarius MX v1-6-0, REV C
Project
04 JUN 2023
Revision Date
Sean P. Harrington
Engineer
aquarius.1stage.com
Website
Email
sph@1stage.com
PSG 1 I/O Header
AY Logic
USB/RAM/ROM Logic
RAM/RTC
ROM
CLK DIV.
RESET
CH376S USB Type A Two Jumpers Data row at BACK LED next to header row
EXPANSION PORT
CH376S USB Type B One Jumper Data row in MIDDLE LED next to USB port

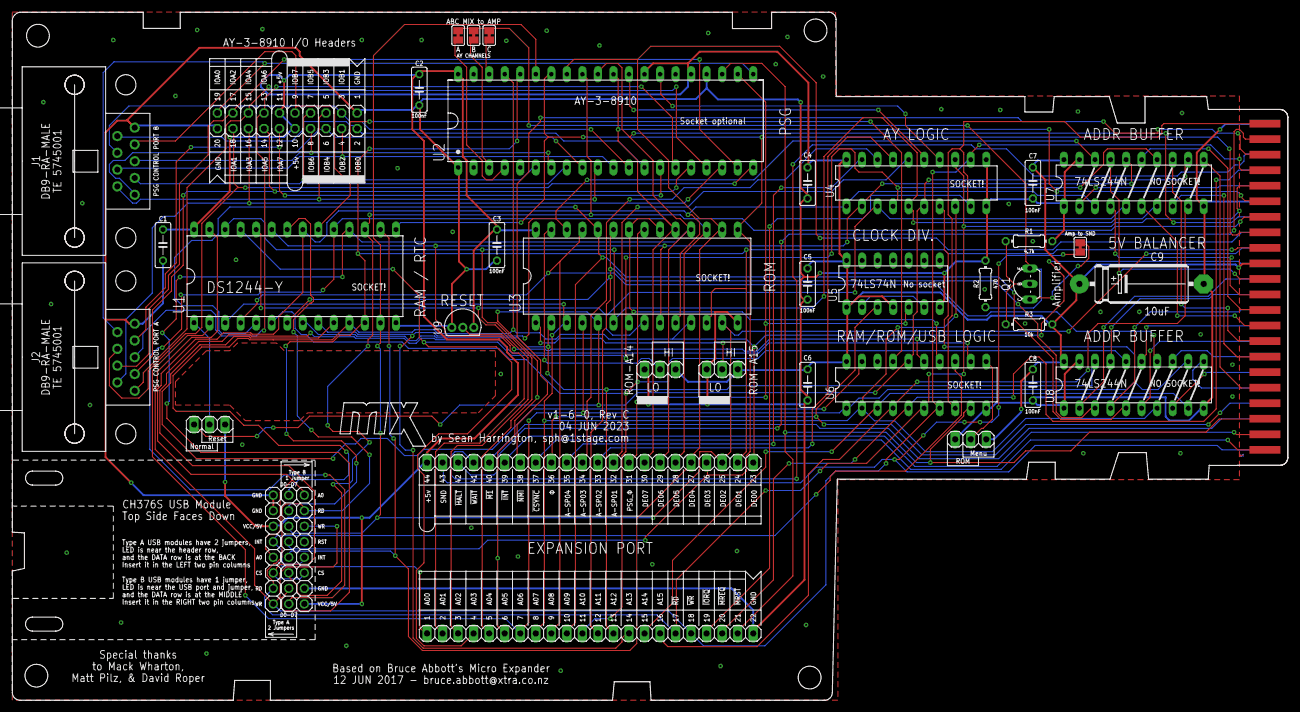
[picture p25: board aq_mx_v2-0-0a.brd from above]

Board: 2 copper layers, 208.6 x 112.5 mm, 40 parts (0 on the bottom side), 95 nets.

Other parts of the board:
LOGO: AQUARIUS-LOGO-SMALL

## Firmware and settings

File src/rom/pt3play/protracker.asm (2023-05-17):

; PT3 player for USB BASIC ROM
;
; 2017-03-22 V0.01 add visuals
; 2017-05-03 V0.03 checking flag bit SF_NTSC to adjust timing for NTSC
; 2017-05-04 V0.04 replaced KEYCHK with AquBASIC Key_Check, SCANCNT set
;                  to 66 after pressing SPACE to reduce debounce time.
; 2017-06-12 V1.0  bumped to release version
; 2023-04-13 v1.5  Standalone ROM version

60Hz = -1  ; make this -1 to play 50Hz songs on 60Hz machine

; address of variables in RAM
VARMEM = $38A0      ; Top of stack at boot (before initializing BASIC)
PLAYER_VER = 1
PLAYER_REV = 5

PSG1A       = $F6   ; PSG1 data     IO port $F6
PSG1B       = $F7   ; PSG1 register IO port $F7
PSG2A       = $F8   ; PSG2 data     IO port $F8
PSG2B       = $F9   ; PSG2 register IO port $F9

; AY registers
; STRUCT AYREGS
TonA     = 0
TonB     = 2
TonC     = 4
Noise    = 6
Mixer    = 7
AmplA    = 8
AmplB    = 9
AmplC    = 10
Env      = 11
EnvTp    = 13

;ChannelsVars
; STRUCT  CHP
;reset group
PsInOr   =  0
PsInSm   =  1
CrAmSl   =  2
CrNsSl   =  3
CrEnSl   =  4
TSlCnt   =  5
CrTnSl   =  6
TnAcc    =  8
COnOff   = 10
;reset group

OnOffD   = 11

;IX for PTDECOD here (+12)
OffOnD   = 12
OrnPtr   = 13
SamPtr   = 15
NNtSkp   = 17
Note     = 18
SlToNt   = 19
Env_En   = 20
PtFlags  = 21
 ;Enabled - 0,SimpleGliss - 2
TnSlDl   = 22
TSlStp   = 23
TnDelt   = 25
NtSkCn   = 27
Volume   = 28
;   ENDS
CHP_size = 29

;---------------------------------------------------------
; Variables (and self-mofifying code, if present) in RAM
; NOTE: must be initialized before use!
;---------------------------------------------------------
;
 STRUCTURE VARS,VARMEM
      BYTE SETUP        ; bit7 = 1 when loop point reached
      WORD CrPsPtr
      BYTE AddToEn
      WORD AdInPtA
      WORD AdInPtB
      WORD AdInPtC
      BYTE Env_Del
      WORD MODADDR
      WORD ESldAdd
      BYTE Delay
      WORD SaveSP
      WORD SamPtrs
      WORD OrnPtrs
      WORD PatsPtr
      WORD LPosPtr
      WORD PrSlide
L3       = PrSlide    ; opcode + RET
M2       = PrSlide
      BYTE PrNote
      BYTE PtVersion
;end of variables and self-modifying code
;start of cleared data area
    STRUCT ChanA,CHP_size
    STRUCT ChanB,CHP_size
    STRUCT ChanC,CHP_size

;GlobalVars
      BYTE DelyCnt
      WORD CurESld
      WORD CurEDel
;arrays
      BYTE Ns_Base
Ns_Base_AddToNs = Ns_Base
      BYTE AddToNs
    STRUCT VT_,256  ; 256 bytes CreatedVolumeTableAddress

AYREGS   = VT_      ; 14 AY-3-8910 registers
EnvBase  = VT_+14
VAR0END  = VT_+16   ; end of cleared data area

T1_      = VT_+16   ; Tone table data depacked here
T_OLD_1  = T1_
T_OLD_2  = T_OLD_1+24
T_OLD_3  = T_OLD_2+24
T_OLD_0  = T_OLD_3+2
T_NEW_0  = T_OLD_0
T_NEW_1  = T_OLD_1
T_NEW_2  = T_NEW_0+24
T_NEW_3  = T_OLD_3

;local vars
Ampl     = AYREGS+AmplC

NT_      = VT_+256       ; 192 bytes Note Table
VAREND   = NT_+192       ; end of variable data area
VAR_size = VAREND-VARMEM

; GUI player variables
  STRUCTURE Player,VAREND

       WORD SKINPTR           ; Pointer to the current meter skin
       BYTE NumSongs          ; number of songs (1-36)
       BYTE Song              ; current song number (0-35)
     STRUCT pt3_files,(36*16) ; array to store 36 file infos
     STRUCT SongData,0        ; pt3 file loaded here!
  ENDSTRUCT Player

PT3_START:
    LD      HL,EQText            ; Set HL to address of default EQ skin
    LD      (SKINPTR),HL         ; Set pointer to the default EQ skin address
PT3_PLAY:
    LD      IX,BgdWindow
       CALL OpenWindow
       LD   IX,SelectWindow
       CALL OpenWindow
       LD   HL,pt3_files      ; array of file infos to fill
       LD   B,36              ; 36 files max.
       LD   DE,pt3pat         ; "*.PT3"
       CALL RequestFile       ; user selects file
       RET  NZ                ; if no file selected then quit
       LD   (Song),A
       LD   A,C
       LD   (NumSongs),A
PT3_LOAD:
       LD   IX,PlayWindow
       CALL OpenWindow        ; open/clear window
       LD   DE,256*1+21
       CALL WinSetCursor      ; cursor at window bottm/left
       LD   HL,PT3help
       CALL WinPrtStr         ; show key help
       LD   A,(Song)
       LD   HL,pt3_files
       CALL IndexArray        ; HL = pt3files[song]
       PUSH HL
       POP  IY
       BIT  ATTR_B_DIRECTORY,(IY+11) ; directory?
       JP   NZ, .next_song     ; yes, skip file
       PUSH HL                ; Save filename address to HL stack
       LD   D,13
       LD   E,1
       CALL WinSetCursor
       LD   A,(SONG)
       ADD  '0'
       CP   '0'+10            ; ID = '0-9', 'A-Z'
       JR   C,.shownum
       ADD  7
.shownum:
       CALL WinPrtChr           ; Print ID
       CALL WinPrtMsg           ; Print ": "
       db   ": ",0              ; Print colon and space before filename
       LD   A,8                 ; Save name length of 8 into A
       CALL WinPrtChrs          ; Print filename (address in HL)
       POP  HL                  ; Retrieve saved filename address from HL
       CALL usb__open_read      ; Open song file
       RET  NZ                  ; Quit if error opening file
       LD   HL,SongData
       LD   DE,-1
       CALL usb__read_bytes     ; Read song file into buffer
       PUSH AF
       CALL usb__close_file
       POP  AF
       RET  NZ                  ; quit if error reading file
       LD   HL,SongData
                                ; Different background char loads will go here
        CALL    DrawBarChars        

       CALL INIT                ; Initialize player
.play_quark:
       LD   B,5                 ; Play 5 'quarks'
.play_loop:
       PUSH BC
       CALL wait_vbl
       CALL Animation
       LD   HL,SongData
       CALL PLAY              ; play next line
       POP  BC
       ld   hl,SETUP
       bit  7,(hl)            ; quit if end of song
       jr   nz,.next_song
       LD   HL,SCANCNT
       LD   A,6               ; starting key up debounce?
       CP   (HL)
       JR   NZ,.debounced     ; no
       LD   (HL),DEBOUNCE-4   ; yes, debounce count to go = 4 scans (~250ms)
.debounced:
       call Key_Check         ; Get ASCII of last key pressed
       cp   $0d
       jr   z,.restart        ; if RTN pressed then return to file list
       cp   " "
       jr   z,.next_song      ; if SPACE pressed then play next song

        CP   "1"                 ; If 1 key pressed...
        JR   Z, .ss1         ; ...set to skin 1 (EQText)
        CP   "2"                 ; If 2 key pressed...
        JR   Z, .ss2         ; ...set to skin 2 (MeterText)
        CP   "3"                 ; If 3 key pressed...
        JR   Z, .ss3         ; ...set to skin 3 (KelpText)
    ;                           --- Add More skins below ---
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

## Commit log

2022-08-22 First push of Eagle items
    [aq_mx_v1-3-0c.brd, aq_mx_v1-3-0c.sch]
2022-08-22 Add ADDR BUFFER crossover indicators
    [aq_mx_v1-3-0c.brd]
2022-08-22 First GERBER export
2022-08-22 Board updates
    [aq_mx_v1-3-0c.brd]
2022-08-22 First export of 3D STL case files
    [aq_mx_case_bottom.stl, aq_mx_case_top.stl]
2022-08-22 First push of docs
    [aq_mx_v1-3-0c.sch]
2022-08-22 PCB Tweaks
    [aq_mx_v1-3-0c.brd]
2022-08-23 PCB updates
2022-08-23 Schematic updates
    [aq_mx_v1-3-0c.sch]
2022-08-24 Update aq_mx_case_bottom.stl
    Increased diameter of screw head holes on BOTTOM for better clearance
    [aq_mx_case_bottom.stl]
2022-10-06 Animation sample
2023-01-22 Updates for v1-4-0b
    [aq_mx_v1-3-0c.brd, aq_mx_v1-3-0c.sch, aq_mx_v1-4-0b.brd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]
2023-01-22 More v1-4-0b updates
    [Aquarius MX - BOM.xlsx]
2023-02-03 Fix for 1.4.0c PCB
    Controller B was missing one of it's mounting holes for metal DB9 ports. If you ordered a PCB with 1.4.0b, you can drill a 1.8" / 3.25mm hole in that position to match the others.
    [aq_mx_v1-4-0c.brd, aq_mx_v1-4-0c.sch]
2023-02-03 PCB Tweak
    Added soldering contact for ground plane to back of PCB for metal DB9 mounting lugs
    [aq_mx_v1-4-0c.brd]
2023-02-11 Minor tweaks to 1.4.0c PCB
    [aq_mx_v1-4-0c.brd]
2023-02-11 Update case for 1.4.0 updates
    Larger USB port opening on back
    Inset case near front of unit to accommodate address buffers in chip sockets.
    Offset top screw posts to allow slightly wider CH376S USB modules.
    [aq_mx_case_bottom.stl, aq_mx_case_top.stl]
2023-03-15 Housekeeping Updates
    [aq_mx_top2.stl, aq_mx_top2_door.stl, aq_mx_v1-4-0c.brd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]
2023-03-15 Update Aquarius MX - BOM.xlsx
    [Aquarius MX - BOM.xlsx]
2023-03-25 Minor PCB Tweaks
    [aq_mx_v1-4-0c.brd, aq_mx_v1-4-0c.sch]
2023-04-09 Case Tweaks & PCB Pics
    Updated STL file for MX Case Top (no door) to fit socketed Address Buffers, and added some updated PCB pictures.
    [aq_mx_case_top.stl]
2023-04-11 Thickened wall at front of 'ramp" on case tops
    [aq_mx_case_top.stl, aq_mx_top2.stl]
2023-04-18 Added DS1244 driver and code for reading the chip
2023-04-19 Updated PCB to v1-5-0a
    Fixed OE & RD issues when using an RTC.
    [aq_mx_v1-4-0c.brd, aq_mx_v1-4-0c.sch, aq_mx_v1-5-0a.brd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]
2023-05-01 Fixes, add Alpha Test Plan
    [Alpha Test Plan - USB BASIC v1.3.xlsx]
2023-05-01 Update Alpha Test Plan - USB BASIC v1.3.xlsx
    [Alpha Test Plan - USB BASIC v1.3.xlsx]
2023-05-04 Poke fixes
    [Alpha Test Plan - USB BASIC v1.3.xlsx]
2023-05-04 Test plan updates, etc
    [Alpha Test Plan - USB BASIC v1.3.xlsx]
2023-05-04 Post-SDTM fix compile
    [Alpha Test Plan - USB BASIC v1.3.xlsx]
2023-05-05 Updates before Alpha
    [Alpha Test Plan - USB BASIC v1.3.xlsx]
2023-05-10 RE-FROZEN for Alpha (post RTC fix)
    [Alpha Test Plan - USB BASIC v1.3.xlsx]
2023-05-10 Alpha Test Plans FINALLY Updated!
    [Alpha Test Plan - USB BASIC v1.3.xlsx]
2023-05-12 1-6-0a PCB Updates
    [aq_mx_v1-5-0a.brd, aq_mx_v1-5-0a.sch, aq_mx_v1-6-0a.brd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]
2023-05-16 Create Alpha 2 Test Plan - MX BASIC v2.0.xlsx
    [Alpha 2 Test Plan - MX BASIC v2.0.xlsx]
2023-05-26 Minor docs tweaks, PEEK recompile
    Words within < > in markdown have to have spaces between the < and > and the word within, otherwise, MD sees it as a special formatting case.
2023-05-30 Ctrl-S mapped to lower case S in edit.asm
2023-06-02 Fixed a pair of shorts in 1-6-0a boards
    [aq_mx_v1-6-0b.brd, aq_mx_v1-6-0b.sch]
2023-06-03 Removed PRINT USING from inline docs for now
2023-06-08 Created AqUnit test framework and test programs
2023-06-17 PCB Future State
    [aq_mx_v2-0-0a.brd, aq_mx_v2-0-0a.sch]
2023-06-17 Show DOS Error 'no disk' when USB drive not inserted
2023-06-20 Switch to <RTN> MX BASIC on splash screen.
2023-06-22 Create Aquarius MX Case.png
2024-02-10 Case updates for universal fit of ports
    [Base Ports.stl, Top Ports.stl, aq_mx_case_bottom.stl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]

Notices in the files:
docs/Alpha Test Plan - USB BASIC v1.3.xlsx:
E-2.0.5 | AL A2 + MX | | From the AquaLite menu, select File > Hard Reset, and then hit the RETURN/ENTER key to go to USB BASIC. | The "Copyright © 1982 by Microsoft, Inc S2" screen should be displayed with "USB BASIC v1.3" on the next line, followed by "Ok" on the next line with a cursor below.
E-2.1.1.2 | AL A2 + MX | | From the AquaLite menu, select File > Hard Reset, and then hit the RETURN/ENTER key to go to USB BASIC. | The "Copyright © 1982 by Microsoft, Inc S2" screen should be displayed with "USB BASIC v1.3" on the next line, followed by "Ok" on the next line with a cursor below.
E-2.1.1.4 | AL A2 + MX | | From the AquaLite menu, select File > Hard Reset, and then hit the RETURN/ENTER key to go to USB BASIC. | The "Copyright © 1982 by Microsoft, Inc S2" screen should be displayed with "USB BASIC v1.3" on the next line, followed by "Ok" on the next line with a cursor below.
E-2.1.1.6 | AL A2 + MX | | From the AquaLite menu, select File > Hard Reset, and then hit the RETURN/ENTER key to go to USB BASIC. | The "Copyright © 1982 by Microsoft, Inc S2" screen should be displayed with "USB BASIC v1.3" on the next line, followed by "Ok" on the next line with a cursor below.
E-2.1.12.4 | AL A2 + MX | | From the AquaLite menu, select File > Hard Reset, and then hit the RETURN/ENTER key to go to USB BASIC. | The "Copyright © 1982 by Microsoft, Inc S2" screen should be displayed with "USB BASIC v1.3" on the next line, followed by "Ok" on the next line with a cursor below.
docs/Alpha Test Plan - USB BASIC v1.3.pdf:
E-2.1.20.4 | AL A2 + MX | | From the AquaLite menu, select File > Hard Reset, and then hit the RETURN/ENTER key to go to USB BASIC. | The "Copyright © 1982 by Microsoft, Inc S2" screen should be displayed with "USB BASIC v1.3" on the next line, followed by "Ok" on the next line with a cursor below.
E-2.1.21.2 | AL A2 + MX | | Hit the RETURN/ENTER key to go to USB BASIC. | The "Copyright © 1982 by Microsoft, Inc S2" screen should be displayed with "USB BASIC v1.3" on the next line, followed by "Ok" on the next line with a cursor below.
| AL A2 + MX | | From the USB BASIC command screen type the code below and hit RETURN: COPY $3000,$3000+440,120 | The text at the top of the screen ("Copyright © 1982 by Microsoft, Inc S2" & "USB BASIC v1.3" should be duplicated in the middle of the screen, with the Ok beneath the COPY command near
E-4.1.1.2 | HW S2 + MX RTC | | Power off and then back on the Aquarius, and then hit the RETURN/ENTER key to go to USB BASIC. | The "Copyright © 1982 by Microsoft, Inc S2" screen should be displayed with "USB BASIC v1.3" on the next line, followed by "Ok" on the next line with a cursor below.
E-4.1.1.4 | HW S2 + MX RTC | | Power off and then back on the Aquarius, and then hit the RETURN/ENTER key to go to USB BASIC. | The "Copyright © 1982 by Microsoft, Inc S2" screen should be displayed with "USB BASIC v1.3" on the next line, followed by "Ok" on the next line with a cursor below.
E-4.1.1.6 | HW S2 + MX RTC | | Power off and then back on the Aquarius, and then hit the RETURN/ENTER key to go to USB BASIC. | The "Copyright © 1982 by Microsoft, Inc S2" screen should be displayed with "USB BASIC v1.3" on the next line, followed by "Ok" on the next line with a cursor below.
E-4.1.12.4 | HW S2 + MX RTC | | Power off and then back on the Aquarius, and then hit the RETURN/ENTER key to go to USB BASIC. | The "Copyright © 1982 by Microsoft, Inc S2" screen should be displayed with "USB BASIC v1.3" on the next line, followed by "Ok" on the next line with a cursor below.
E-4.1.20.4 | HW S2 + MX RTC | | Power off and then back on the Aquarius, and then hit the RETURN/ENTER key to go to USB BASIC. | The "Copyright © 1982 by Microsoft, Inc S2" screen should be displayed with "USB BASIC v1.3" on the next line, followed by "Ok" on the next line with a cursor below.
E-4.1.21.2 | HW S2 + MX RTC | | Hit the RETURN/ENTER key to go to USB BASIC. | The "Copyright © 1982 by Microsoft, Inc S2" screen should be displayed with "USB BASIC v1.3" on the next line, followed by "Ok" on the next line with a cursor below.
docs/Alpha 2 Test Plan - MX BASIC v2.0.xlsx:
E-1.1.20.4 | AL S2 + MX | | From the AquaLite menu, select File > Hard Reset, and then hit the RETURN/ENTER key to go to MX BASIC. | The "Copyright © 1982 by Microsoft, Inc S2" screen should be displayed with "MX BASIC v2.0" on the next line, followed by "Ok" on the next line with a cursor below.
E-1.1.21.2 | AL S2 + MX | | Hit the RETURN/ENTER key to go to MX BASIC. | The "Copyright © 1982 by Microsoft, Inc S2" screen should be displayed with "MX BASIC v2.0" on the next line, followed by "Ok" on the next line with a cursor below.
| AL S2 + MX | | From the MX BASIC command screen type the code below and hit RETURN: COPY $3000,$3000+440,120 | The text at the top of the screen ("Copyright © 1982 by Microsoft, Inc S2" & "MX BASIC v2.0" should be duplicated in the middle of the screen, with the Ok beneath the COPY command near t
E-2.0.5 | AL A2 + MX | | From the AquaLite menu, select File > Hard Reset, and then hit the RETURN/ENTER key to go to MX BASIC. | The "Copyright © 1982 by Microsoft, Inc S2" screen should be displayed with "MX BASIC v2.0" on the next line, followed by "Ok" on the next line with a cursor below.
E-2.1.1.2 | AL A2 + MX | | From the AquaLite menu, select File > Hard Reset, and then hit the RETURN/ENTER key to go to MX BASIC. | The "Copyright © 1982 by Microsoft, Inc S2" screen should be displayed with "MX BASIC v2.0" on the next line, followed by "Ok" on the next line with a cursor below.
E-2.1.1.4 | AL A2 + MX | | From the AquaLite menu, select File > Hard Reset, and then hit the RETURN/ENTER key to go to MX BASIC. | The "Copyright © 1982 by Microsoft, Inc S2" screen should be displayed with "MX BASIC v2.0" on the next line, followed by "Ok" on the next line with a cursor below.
